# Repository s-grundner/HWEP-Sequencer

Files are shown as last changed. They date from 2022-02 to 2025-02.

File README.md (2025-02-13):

# HWEP - Sequencer [DE]



Frontpanel

| Neueste Renderung der Platine | Assemblierter Prototyp |
|:---:|:---:|
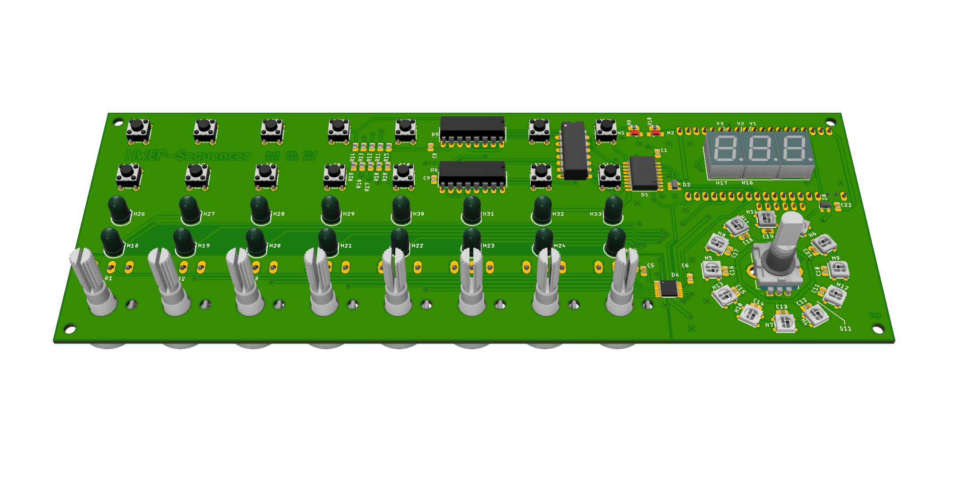
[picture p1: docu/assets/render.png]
render
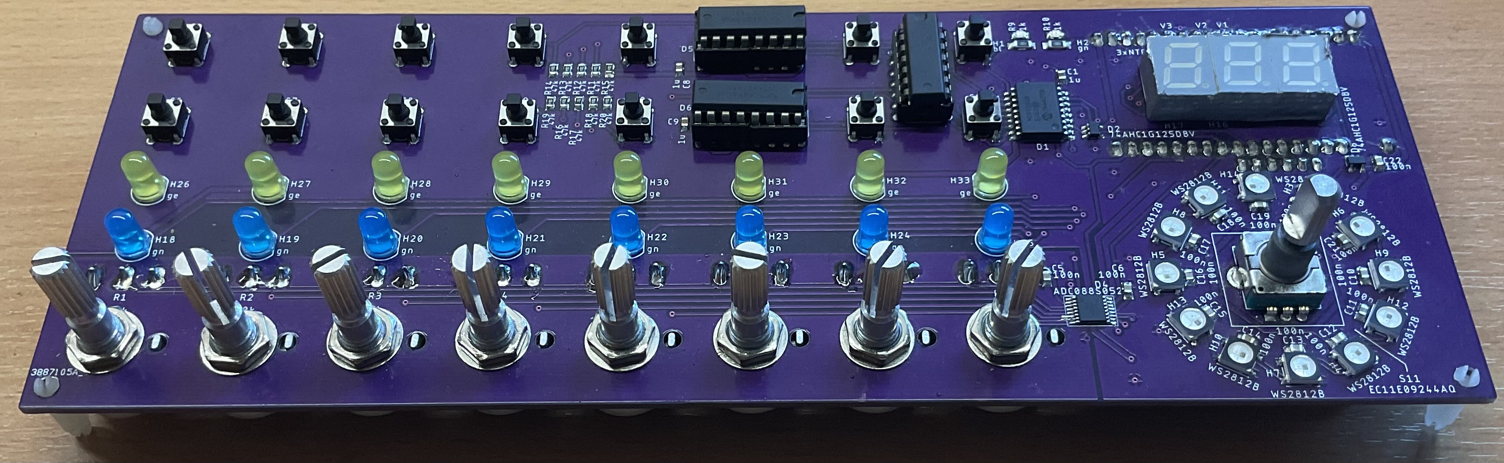
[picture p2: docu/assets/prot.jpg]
prototype
|||

## Projektstatus

MIDI Erweiterung in Arbeit. CAD dateien e.g. Gehäuse sind noch nicht im Projekt inkludiert.
Um die Diagramme in der Dokumentation gut erkennen zu können, empfiehlt sich, das Dark-Mode-Theme von GitHub zu Verwenden.

## Repository Struktur

 - [**Hardware DOCS**](manufacturing/hwep_sequencer_v2)
 - [**Software DOCS**](src/SRC_HWEP_Sequencer_V2)

## KUB - Kurzbeschreibung

Der Sequenzer ist ein musisches Instrument, welches vom Benutzer einstellbare Töne nacheinander abspielt und dadurch eine Melodie erzeugt. Die Tonlage wird durch Potentiometer analog eingestellt und anschließend an die chromatische Skala angepasst. Die acht Töne werden mit jeder steigenden Flanke des Takts durchgeschaltet.

Mit einem Pause-Taster kann der Zyklus pausiert werden. Mit dem Reset-Taster kann zum Anfang des Zyklus gesprungen werden. Der "Show Key" Taster zeigt bei Betätigung die Gespielten Noten am Display an. Der Sequencer ist mit zwei Prescalern für Gate-Länge und Taktrate ausgestattet. Dieser teilt den Takt oder das Gate des Tones durch 1, 2, 4, 8 oder 16. Außerdem verfügt der Sequencer über eine Umschalttaste (Shift), die das Funktionsspektrum erweitern. Die Dokumentation für die Taster befindet sich in der Funktionsbeschreibung.

Zum Bedienen des Sequencers gibt es verschiedene Parameter, die mithilfe eines Dreh-Encoders gesteuert werden können. Der Dreh-Encoder hat einen integrierten Taster, mit welchem man die Parameter, die man verändern will, einstellen kann. Die Veränderung der Parameter wird je nach Modus an verschiedenen Status LEDs und Anzeigen abgezeichnet.

Der Sequencer wird mit dem einem RTOS am ESP32 32-bit Microcontroller betrieben. Der Digitale Audioausgang erfolgt über das I²S (Inter-IC-Sound) Protokoll und kann 16-Bit Sounds bei einer Abtastrate von 44.1kHz übertragen und durch einen I²S-DAC (PCM5102a) direkt als Audio-Signal ausgegeben werden.

## FUB - Funktionsbeschreibung

Button_desc

#### 1. 8 Potentiometer als analoger Eingang

 - dient als analoger Eingang für die Tonlage der einzelnen Töne
 - jedes Potentiometer umfasst 24 Halbtöne bzw. zwei Oktaven
 - die analogen Werte einem 8 Channel ADC (ADC088S052) über die SPI Schnittstelle eingelesen

#### 2. 16 Status LED’s:

 - 8 EN-LED’s:
   - zeigen an, welcher Ton spielen wird oder stummgeschalten ist (LED aus)
 - 8 Index/Cursor-LED’s:
   - **Index:** zeigen an, welcher Ton gerade spielt
   - **Cursor:** dient zum Anzeigen eines Cursors

#### 3. 3x 7-Segent Display:

 - nützen zur Anzeige von Parametern
 - werden mit einem MCP23S08 via die SPI Schnittstelle seriell angesteuert
 
#### 4. Dreh-Encoder:

 - zum Einstellen der Parameter der verschiedenen Modi
 - um den Drehencoder befinden sich 12 RGB-LED’s, welche den Rotationstatus anzeigen
 
#### 5. Taster: 

> Jeder Taster wird mittels eines MCP23S08 via SPI eingelesen.

 - **Pause:** pausiert den Zyklus
 - **Reset:** setzt den Zyklus asynchron zurück
 - **Show Keys:** zeigt die gespielten Noten am Display
 - **Shift:** zum Einstellen der Parameter der verschiedenen Modi
 - e. **Prescaler:** einstellen von zwei verschiedenen Prescalern für Gate und Takt
   - 5 Taster für jeden Prescaler
   - Tasten werden auf 4-Bit Priorität-Encodiert
 
#### 6. 4 Modi

> Jeder Modus verändert die Anzeigen an den Status LED’s und Displays bzw. die Funktionalität verschiedener Eingaben. Nach wechseln eines Modus wird der aktuelle Modus am 7-Segment Display angezeigt, bis die Anzeige benötigt wird, um einen Parameter anzuzeigen.
 
 - BPM:
   - **7-Segment Display:** zeigt die eingestellten BPM bzw. die Wellenform an
   - **Index/Cursor:** zeigt den Index an
   - **Drehencoder:** zum Verändern der BPM
   - **Shift Taster:** Drehencoder verändert die Wellenform
 - Tonleiter Einstellungen:
   - **7-Segment Display:** zeigt den Tonleiter bzw. den Modalen Tonleiter an.
   - **Index/Cursor:** zeigt den Index an
   - **Drehencoder:** zum Verändern den Tonleiter
   - **Shift Taster:** verändert den Modus des Tonleiters (Dur,Moll…)
 - Enable/Reset:
   - **7-Segment Display:**
   - **Index/Cursor:** zeigt den Cursor an
   - **Drehencoder:** bewegt den Cursor. Dort wo der Cursor stehen bleibt, setzt sich der Zyklus zurück.
   - **Shift Taster:** stummt/entstummt einen Ton an der Cursorstellung
 
 - Transpose:
   - **7-Segment Display:** zeigt an um wieviel Halbtöne die Melodie transponiert wird
   - **Index/Cursor:** zeigt den Index an
   - **Drehencoder:** Transponiert die Tonlage um einen Halbton
   - **Shift Taster:** Drehencoder verändert die Tonlage um eine Oktave
 
#### 7. ESP32 32-Bit Microcontroller:

 - Zentrale Recheneinheit für den Sequenzer
 - Berechnung der Wavetables
 - SPI als Übertragungsprotokoll zur Ansteuerung der internen Peripherien
 - Audio-Output:
   - Digitale Audioübertragung via I²S Protokoll
   - 16-bit Audio-Signale mit Abtastrate von 44,1kHz
   - Ein I²S-DAC (PCM5102a) decodiert die Audio-Daten und gibt sie Analog an eine 3,5mm Klinkenbuchse aus.
   - Kompatibel mit Trinity Endstufe

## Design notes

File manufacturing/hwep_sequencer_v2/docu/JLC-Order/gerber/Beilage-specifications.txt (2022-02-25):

PC board specifications: 
Board thickness:   	1.570000mm
Board type:       	FR4
Number of layers:  	2
End copper thickness:	35.000000um
Stop mask color:   	green
Silk screen color: 	white
Surface finish:    	any lead free
Silk screen trim: 	Trim on solder mask opening pads

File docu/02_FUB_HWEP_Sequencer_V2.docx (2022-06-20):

Funktionsbeschreibung

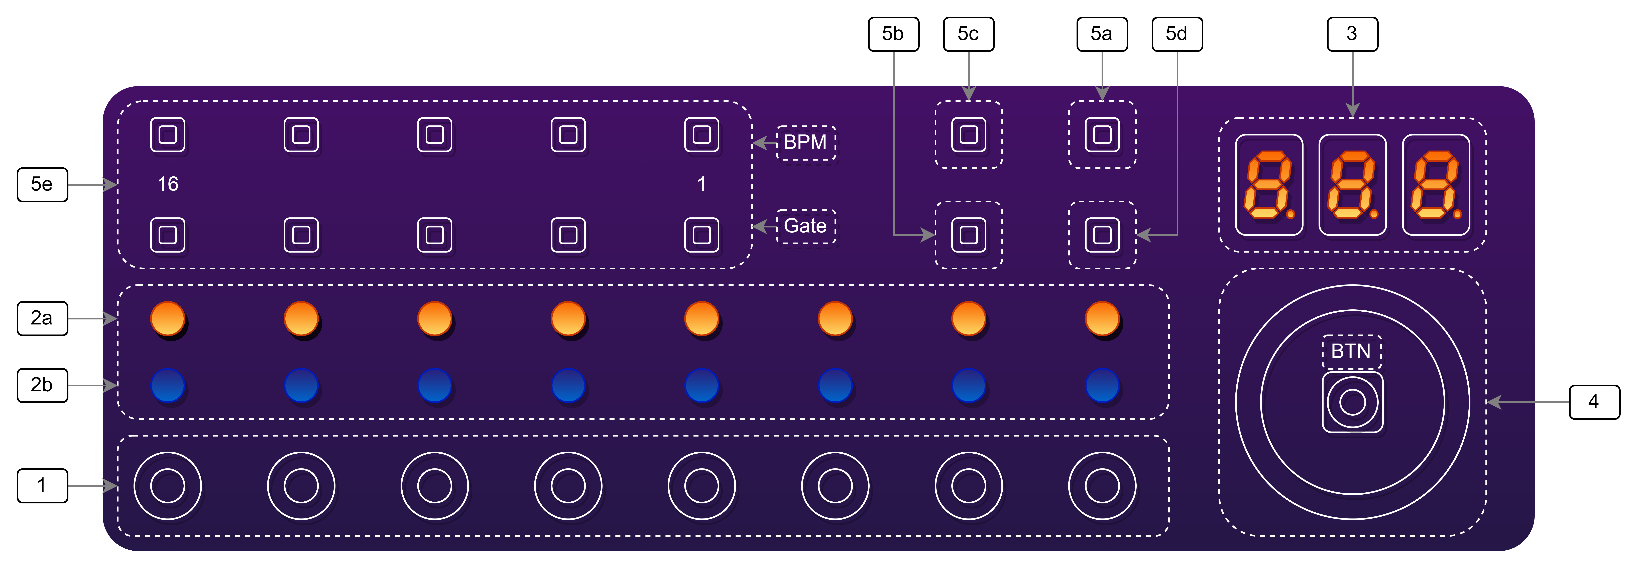
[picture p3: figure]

1. 8 Potentiometer als analoger Eingang:
  a. dient als analoger Eingang für die Tonlage der einzelnen Töne
  b. jedes Potentiometer umfasst 24 Halbtöne bzw. zwei Oktaven
  c. die analogen Werte einem 8 Channel ADC (ADC088S052) über die SPI Schnittstelle eingelesen
2. 16 Status LED’s:
  a. 8 EN-LED’s:
    i. zeigen an, welcher Ton spielen wird oder stummgeschalten ist (LED aus)
  b. 8 Index/Cursor-LED’s:
    i. Index: zeigen an, welcher Ton gerade spielt
    ii. Cursor: dient zum Anzeigen eines Cursors
3. 3x 7-Segent Display:
  a. nützen zur Anzeige von Parametern
  b. werden mit einem MCP23S08 via die SPI Schnittstelle seriell angesteuert
4. Dreh-Encoder:
  a. zum Einstellen der Parameter der verschiedenen Modi
  b. um den Drehencoder befinden sich 12 RGB-LEDs, welche den Rotationstatus anzeigen
5. Taster: Jeder Taster wird mittels eines MCP23S08 via SPI eingelesen.
  a. Pause: pausiert den Zyklus
  b. Reset: setzt den Zyklus asynchron zurück
  c. Show Keys: zeigt die gespielten Noten am Display
  d. Shift: zum Einstellen der Parameter der verschiedenen Modi
  e. Prescaler: einstellen von zwei verschiedenen Prescalern für Gate und Takt
    i. 5 Taster für jeden Prescaler
    ii. Taster werden auf 4-Bit Priorität-Encodiert
6. 4 Modi

Jeder Modus verändert die Anzeigen an den Status LEDs und Displays bzw. die Funktionalität verschiedener Eingaben. Nach wechseln eines Modus wird der aktuelle Modus am 7-Segment Display angezeigt, bis die Anzeige benötigt wird, um einen Parameter anzuzeigen. Der Modus wird Weitergeschalten, indem man den integrierten Taster des Dreh-Encoder drückt.

  a. BPM:
    i. 7-Segment Display: zeigt die eingestellten BPM bzw. die Wellenform an
    ii. Index/Cursor: zeigt den Index an
    iii. Drehencoder: zum Verändern der BPM
    iv. Event Taster: Drehencoder verändert die Wellenform
  b. Tonleiter Einstellungen:
    i. 7-Segment Display: zeigt den Tonleiter bzw. den Modalen Tonleiter an.
    ii. Index/Cursor: zeigt den Index an
    iii. Drehencoder: zum Verändern des Tonleiters
    iv. Event Taster: verändert den Modus des Tonleiters (Dur, Moll…)
  c. Enable/Reset:
    i. 7-Segment Display: -
    ii. Index/Cursor: zeigt den Cursor an
    iii. Drehencoder: bewegt den Cursor. Dort wo der Cursor stehen bleibt, setzt sich der Zyklus zurück.
    iv. Event Taster: stummt/entstummt einen Ton an der Cursorstellung
  d. Transpose:
    i. 7-Segment Display: zeigt an um wieviel Halbtöne die Melodie transponiert wird
    ii. Index/Cursor: zeigt den Index an
    iii. Drehencoder: Transponiert die Tonlage um einen Halbton
    iv. Event Taster: Drehencoder verändert die Tonlage um eine Oktave
7. ESP32 32-Bit Microcontroller:
  a. Zentrale Recheneinheit für den Sequenzer
  b. Berechnung der Wavetables
  c. SPI als Übertragungsprotokoll zur Ansteuerung der internen Peripherien
  d. Audio-Output:
    i. Digitale Audioübertragung via I²S Protokoll
    ii. Auswahl zwischen 16-, 24- und 32-bit Audio-Signale mit Abtastrate von 44,1kHz
    iii. Ein I²S-DAC (PCM5102a) decodiert die Audio-Daten und gibt sie Analog an eine 3,5mm Klinkenbuchse aus.

4AHEL Grundner, Ihninger 20.6.2022 1 / 1

HWEP Sequencer Elektronik Technische Informatik Funktionsbeschreibung

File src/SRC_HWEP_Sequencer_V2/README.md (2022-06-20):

# Software DOCS [DE]

Die Software am ESP32 des Sequencers kümmert sich um die Anzeigen, die Benutzer-Eingaben sowie das Audio. Um diese Aufgaben zu erfüllen, wurde ein Real Time Operating System (freeRTOS) verwendet, welches die auf der nächsten Seite zusehenden Tasks verwaltet.
Der Source Code und auch alle Libraries sind ausschließlich in C geschrieben.

# Toolchain
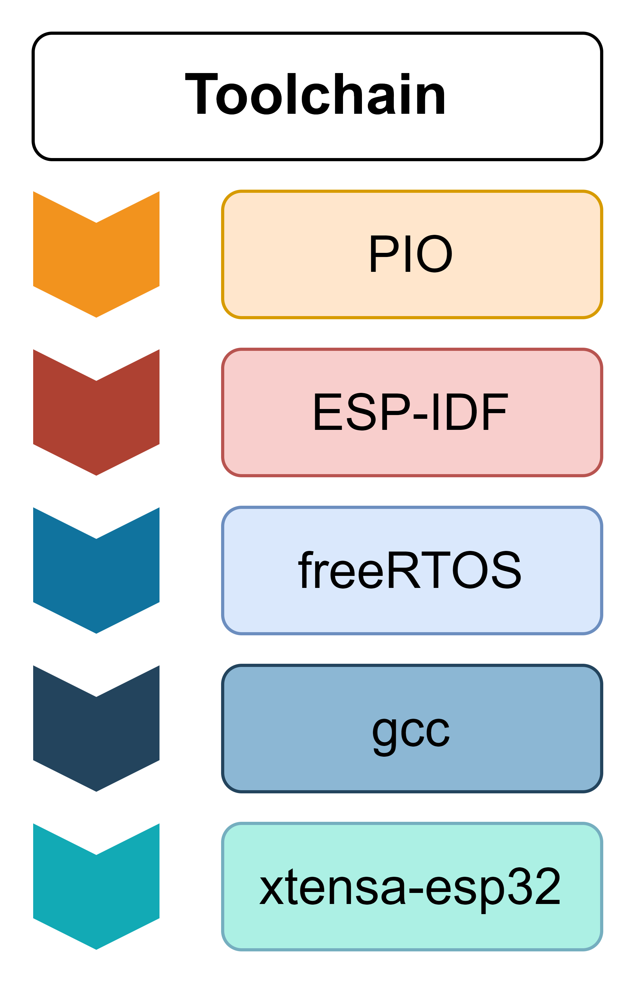
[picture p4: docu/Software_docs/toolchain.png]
Toolchain


# Programm beschreibung

RTOS

BSB

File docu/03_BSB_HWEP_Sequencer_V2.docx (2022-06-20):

##### Blockschaltbild

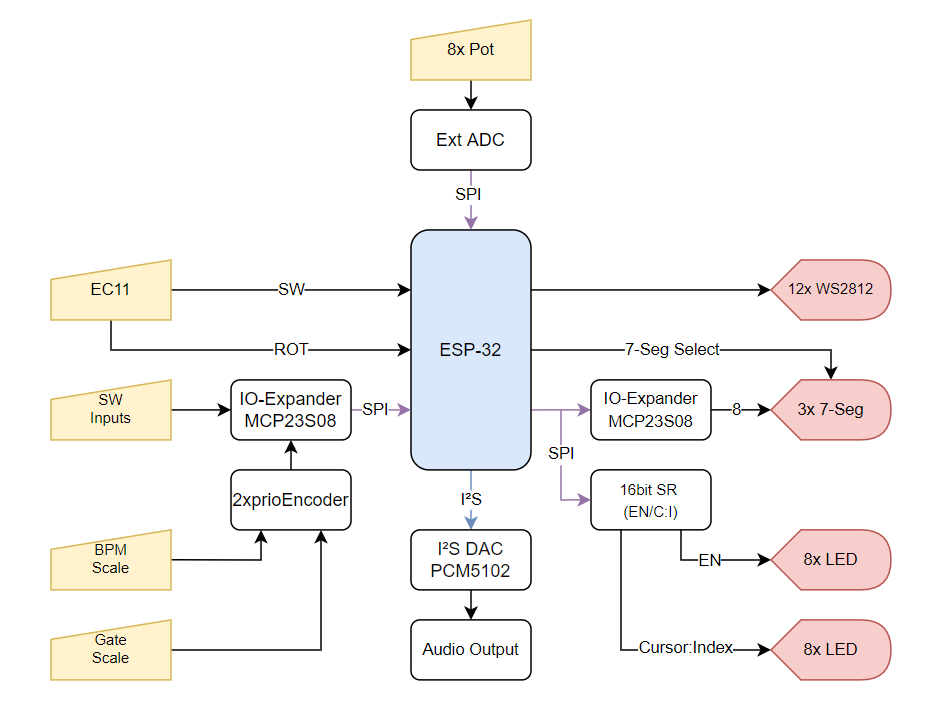
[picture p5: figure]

4AHEL Grundner/Ihninger 20.6.2022

HWEP Sequencer Elektronik Technische Informatik Blockschaltbild

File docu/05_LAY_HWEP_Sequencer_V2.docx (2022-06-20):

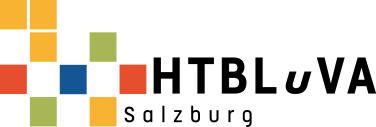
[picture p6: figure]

Werkstoff:

Sachnummer, Dateiname:

Name:

Benennung:

Toleranz:

Blatt:

Blätter:

Datum:

Spr.:

Maßstab:

Dokumentart:

ID-Nr.:

Version:

Dokumentstatus:

Gez.:

Geprüft:

Betreuer:

Freigabe:

Revision:

Beilage 2

Grundner, Ihninger

Sequencer

Layout top

4AHEL

ohne

DE

1

1

20.06.2022

HTBLuVA Salzburg

Elektronik

GruS

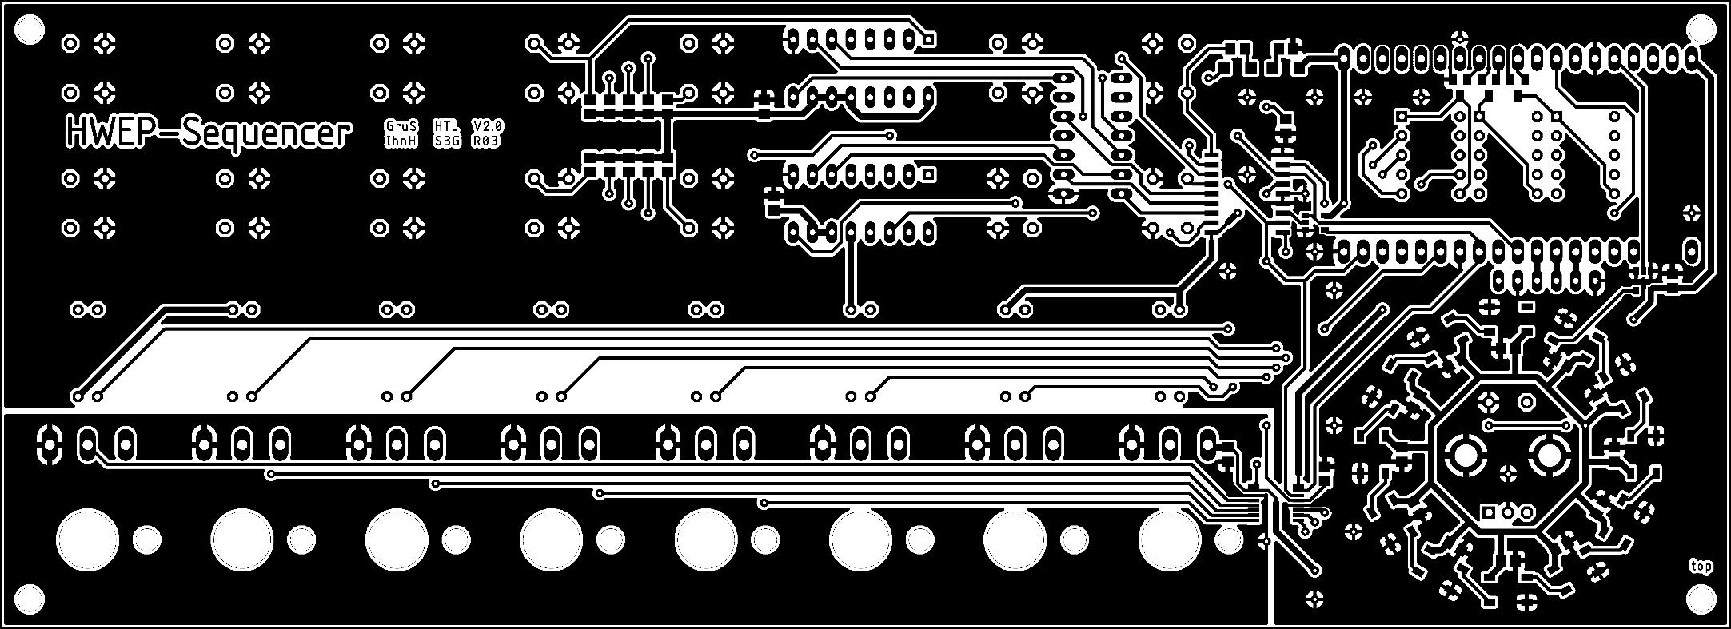
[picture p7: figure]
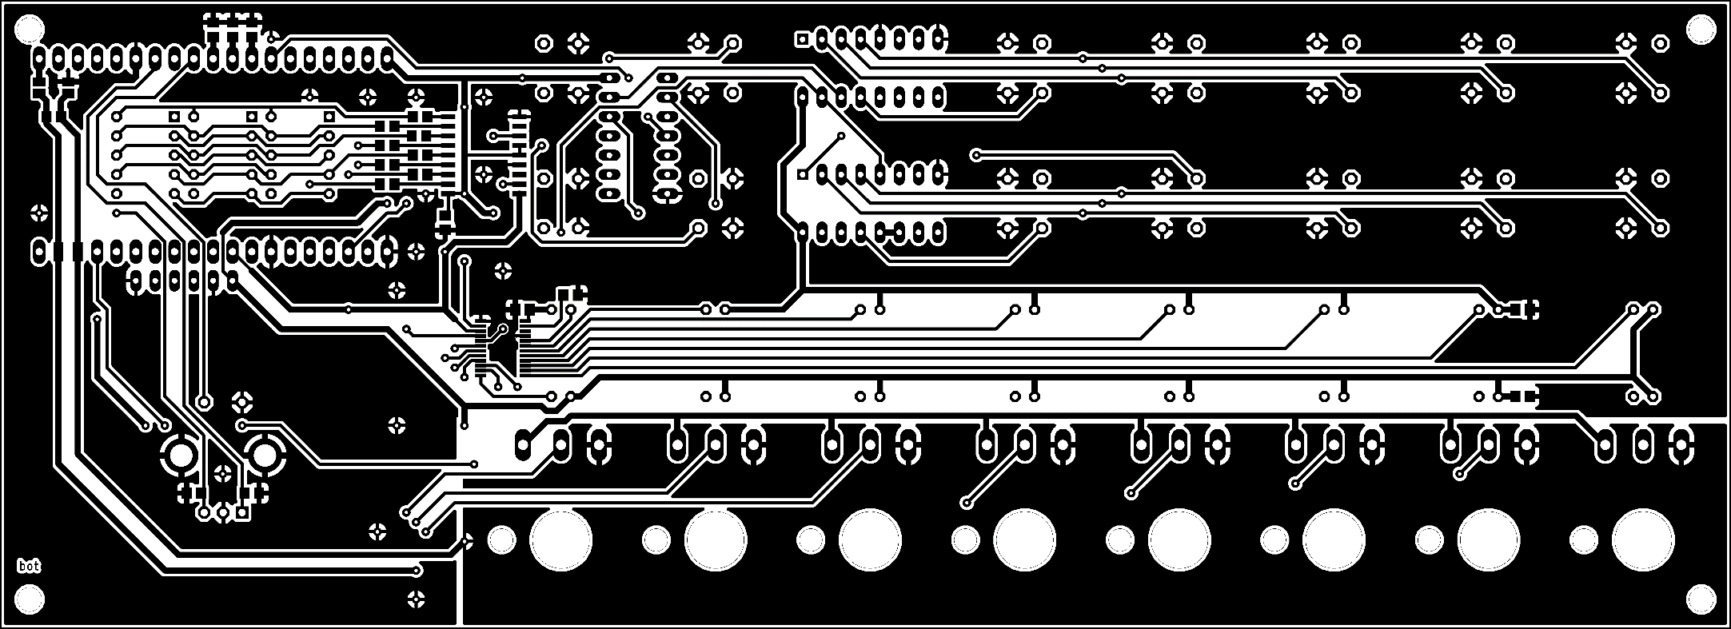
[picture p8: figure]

Werkstoff:

Sachnummer, Dateiname:

Name:

Benennung:

Toleranz:

Blatt:

Blätter:

Datum:

Spr.:

Maßstab:

Dokumentart:

ID-Nr.:

Version:

Dokumentstatus:

Gez.:

Geprüft:

Betreuer:

Freigabe:

Revision:

Beilage 3

Grundner, Ihninger

Sequenzer

Layout bot

4AHEL

ohne

DE

1

1

20.06.2022

HTBLuVA Salzburg

Elektronik

GruS

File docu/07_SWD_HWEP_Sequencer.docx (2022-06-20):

Softwarebeschreibung

Die Software am ESP32 des Sequencers kümmert sich um die Anzeigen, die Benutzer-Eingaben sowie das Audio. Um diese Aufgaben zu erfüllen, wurde ein Real Time Operating System (freeRTOS) verwendet, welches die auf der nächsten Seite zusehenden Tasks verwaltet.

Der Source Code und auch alle Libraries sind ausschließlich in C geschrieben.

Das Hauptprogramm hat folgenden Ablauf:

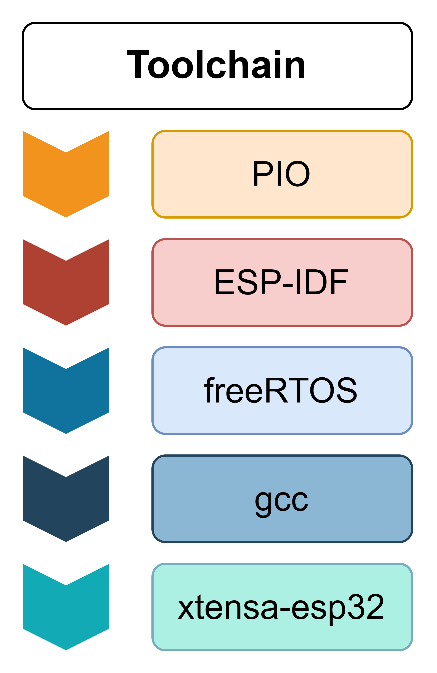
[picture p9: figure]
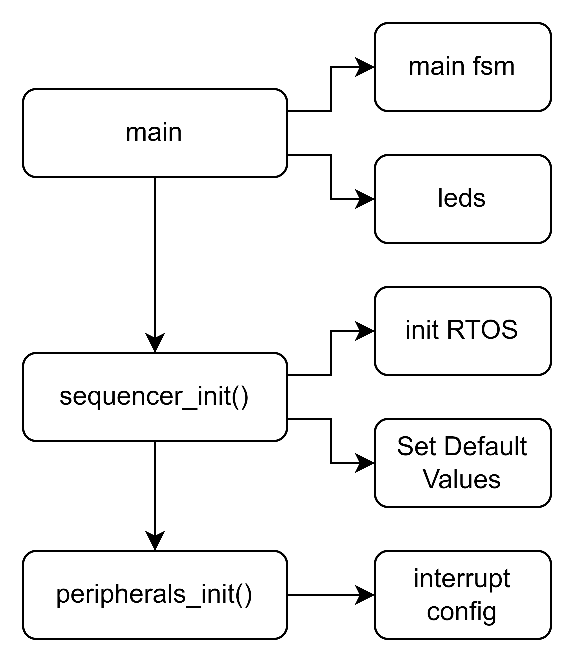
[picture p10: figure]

Das Open Source Projekt kann auf https://github.com/s-grundner/HWEP-Sequencer vollständig angesehen werden.

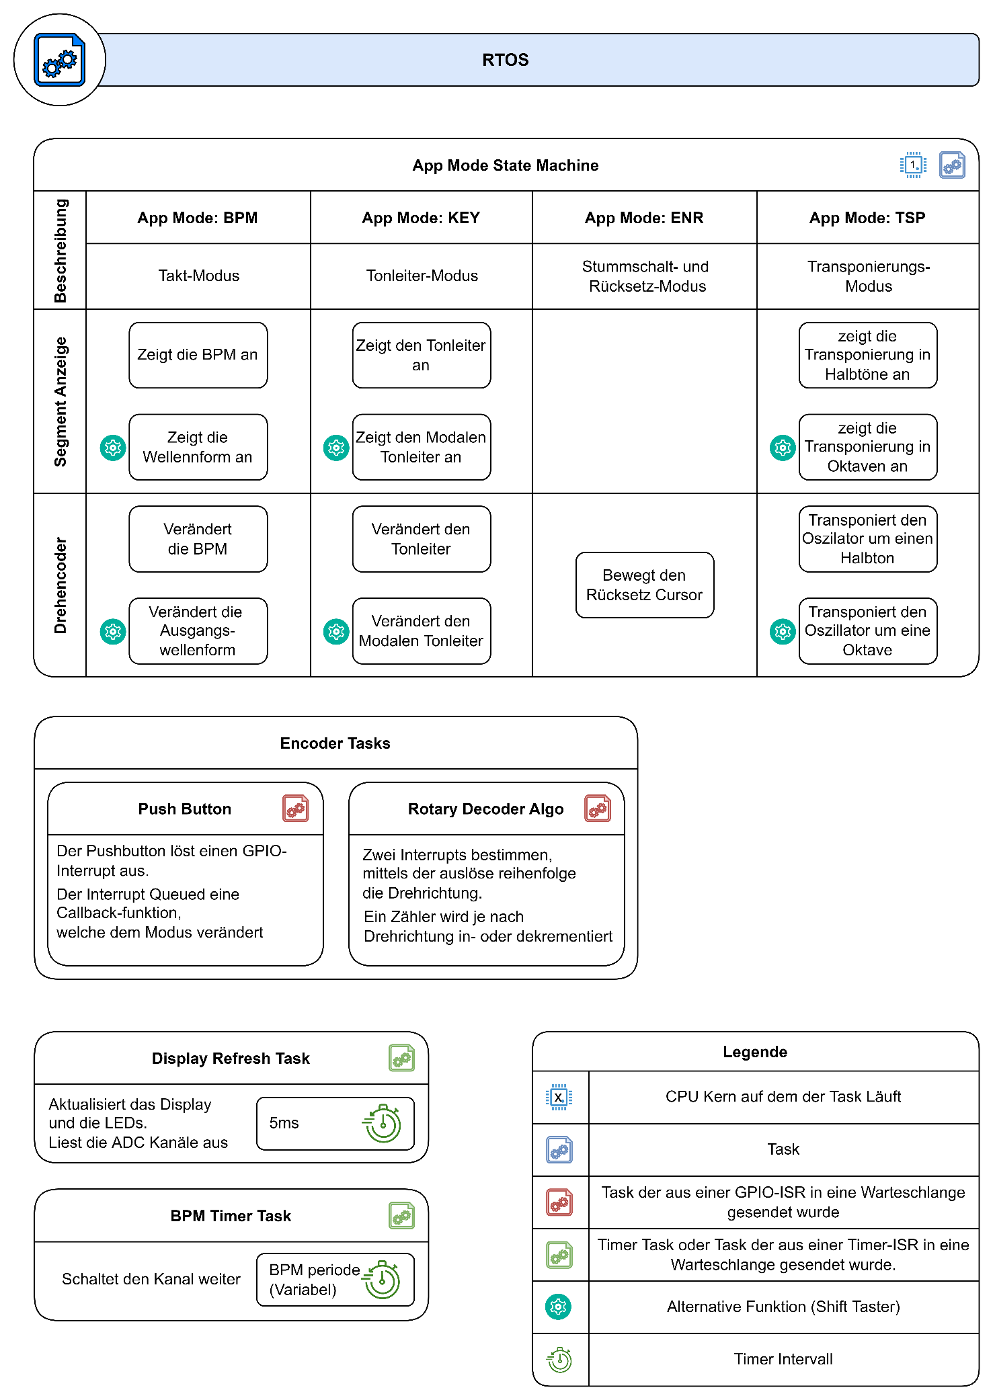
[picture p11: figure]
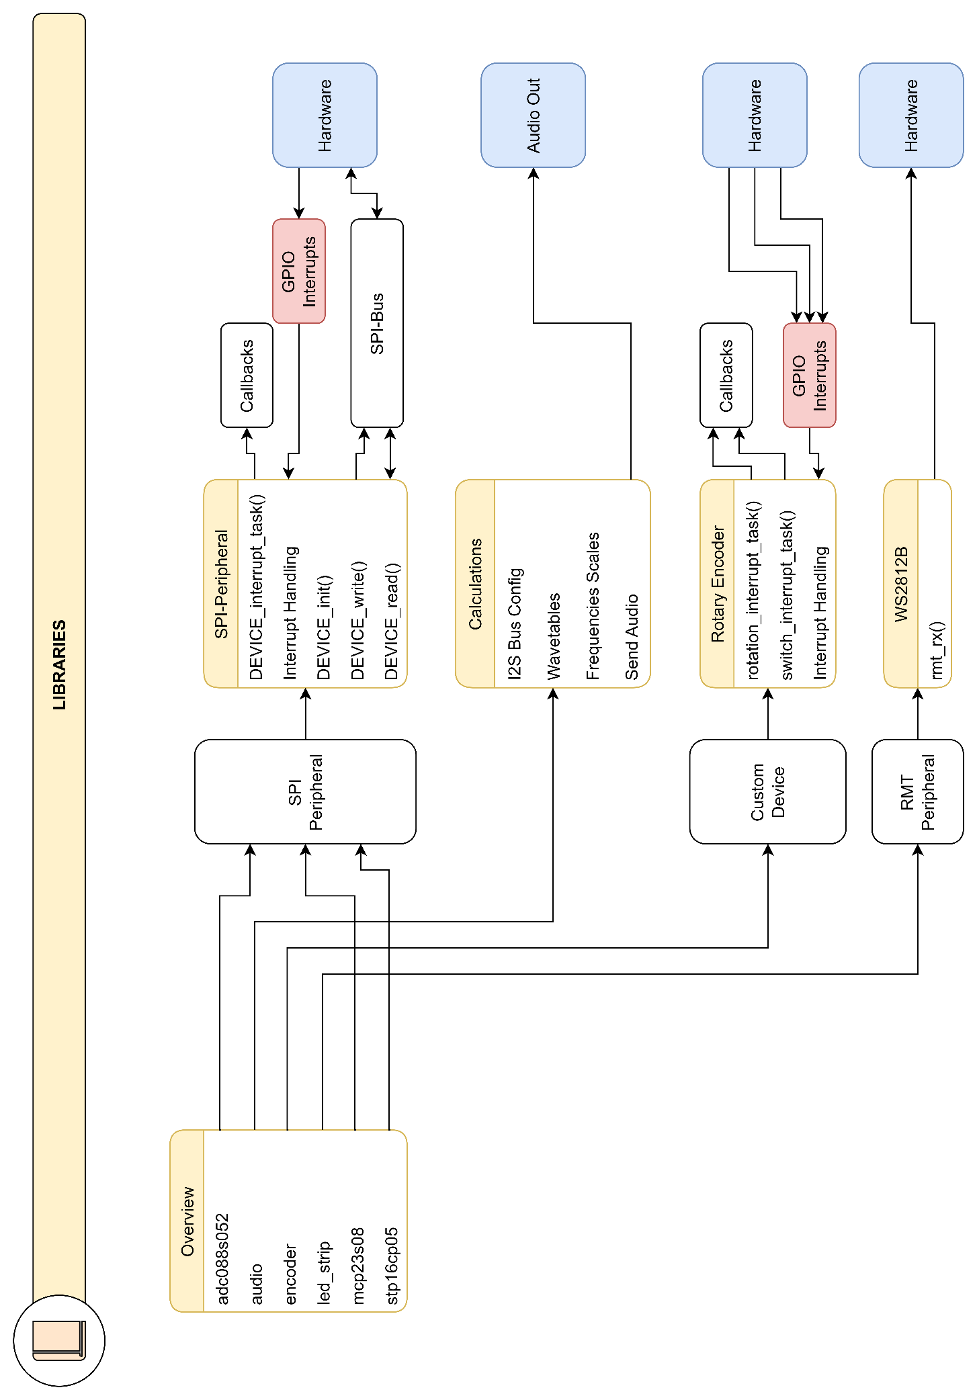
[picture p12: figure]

4AHEL Grundner/Ihninger 20.6.2022

HWEP Sequencer Elektronik Technische Informatik Software-Dokumentation

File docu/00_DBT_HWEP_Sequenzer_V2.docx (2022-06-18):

Sequencer

Ein Projekt

von Grunder Simon

&

Ihninger Hanna

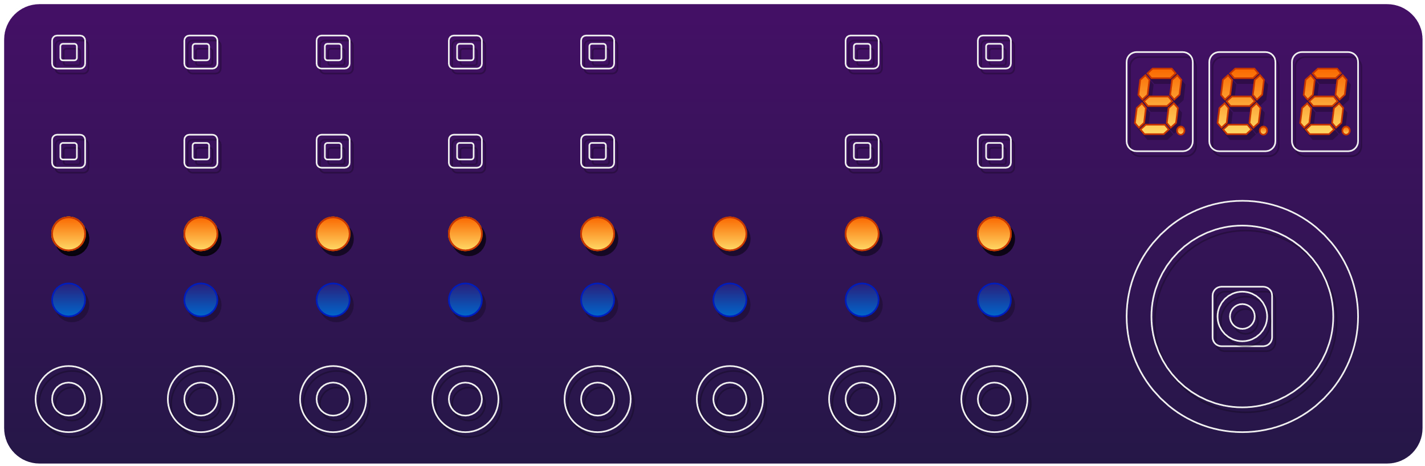
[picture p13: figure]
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

S a l z b u r g

Abteilung für Elektronik und technische Informatik

4AHEL

2022

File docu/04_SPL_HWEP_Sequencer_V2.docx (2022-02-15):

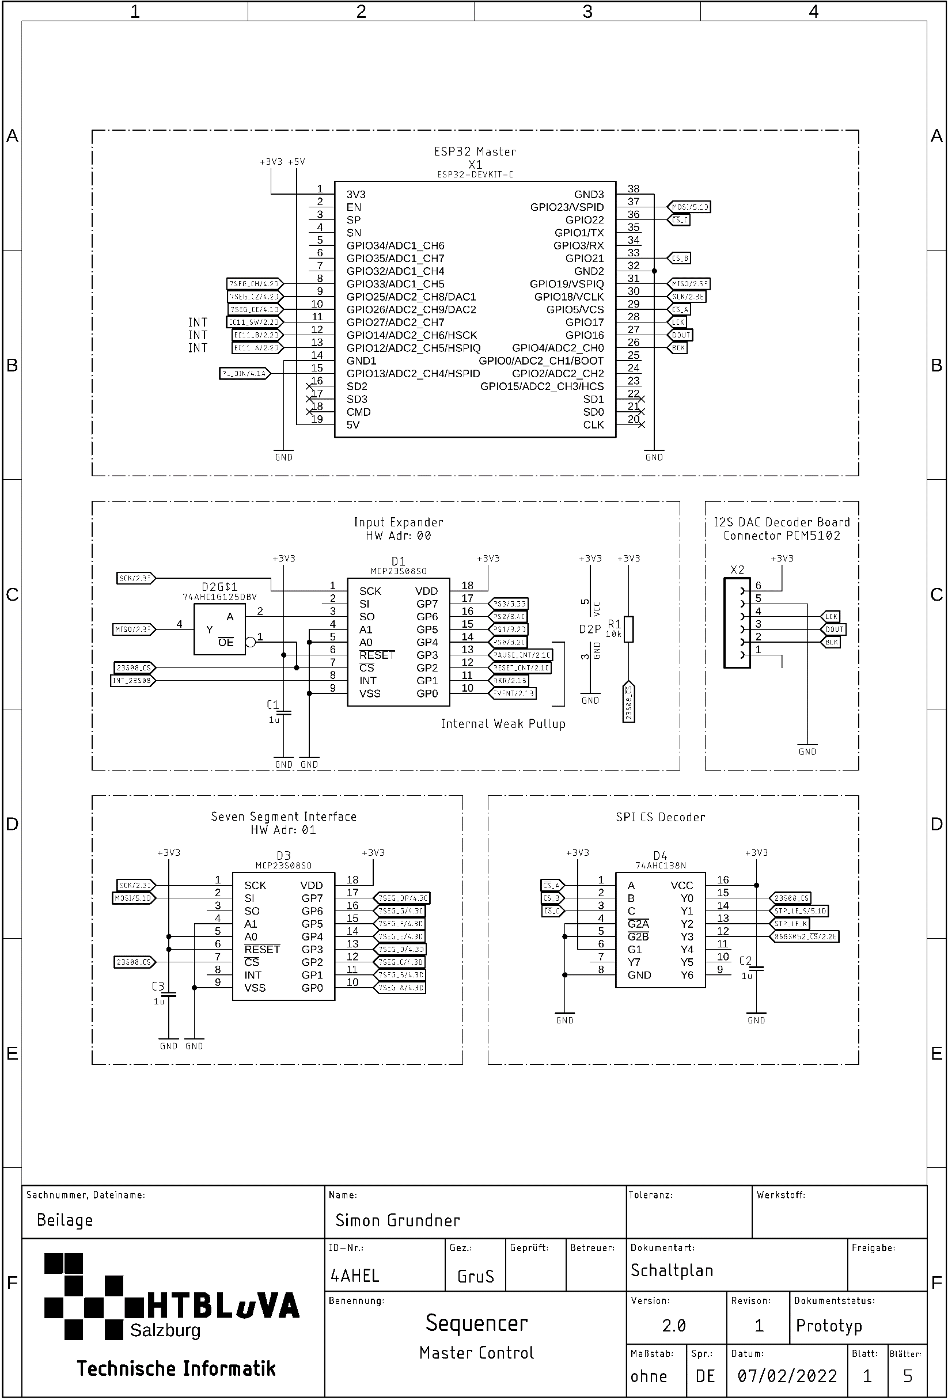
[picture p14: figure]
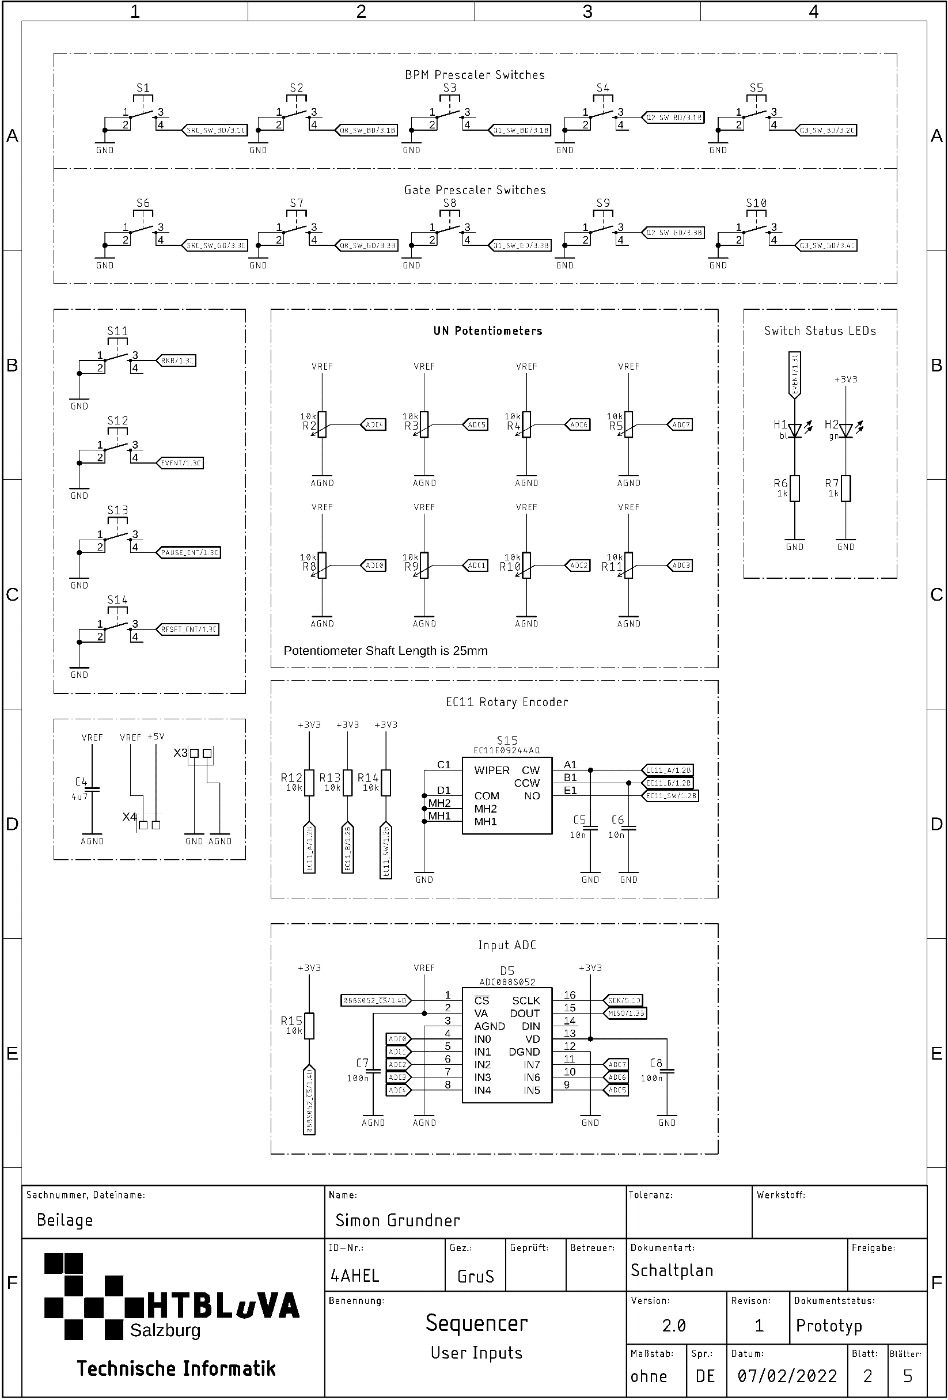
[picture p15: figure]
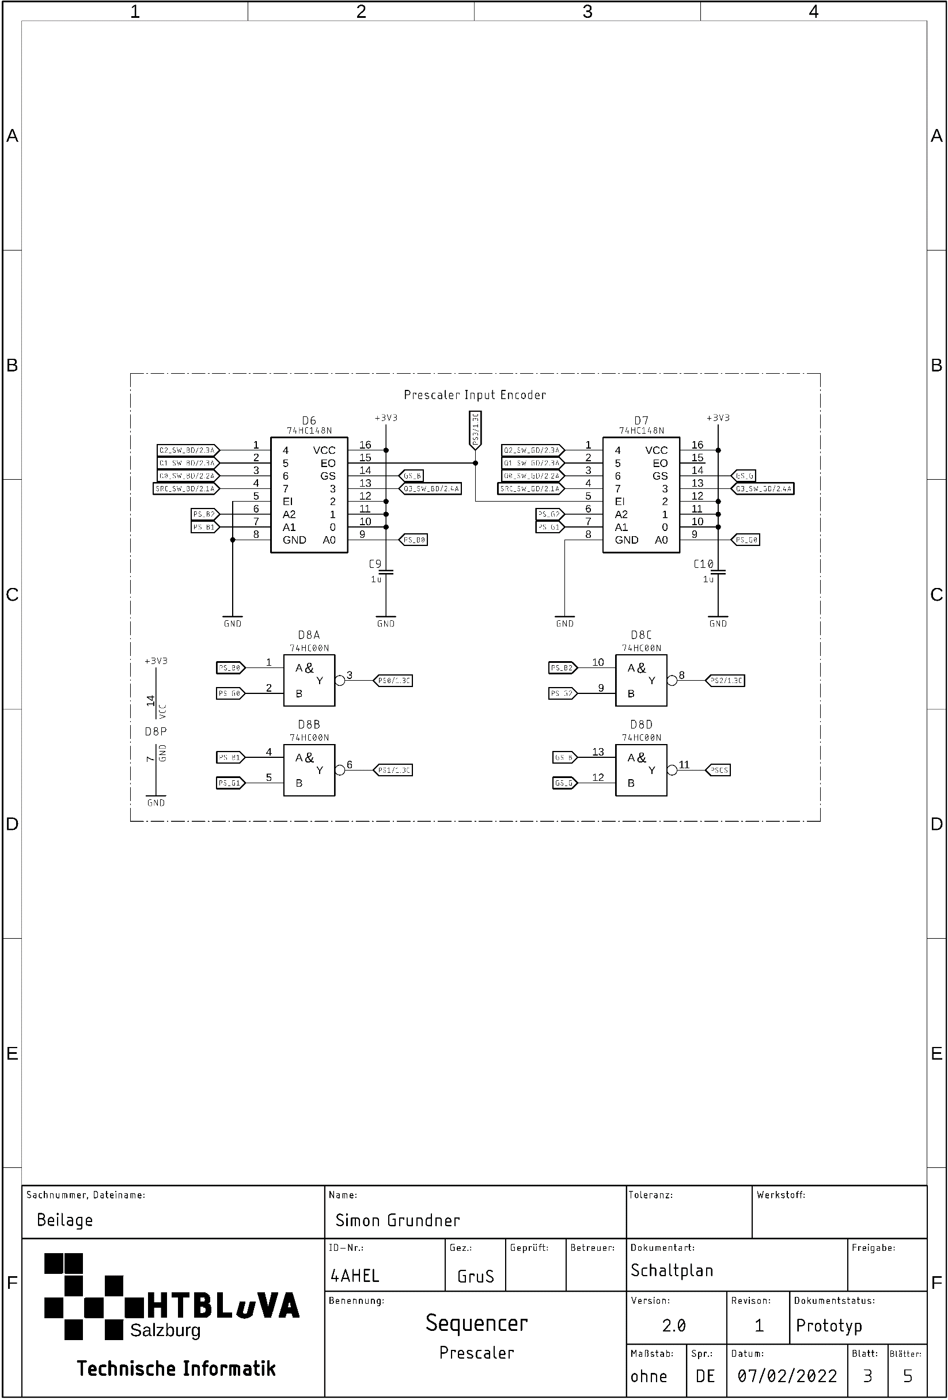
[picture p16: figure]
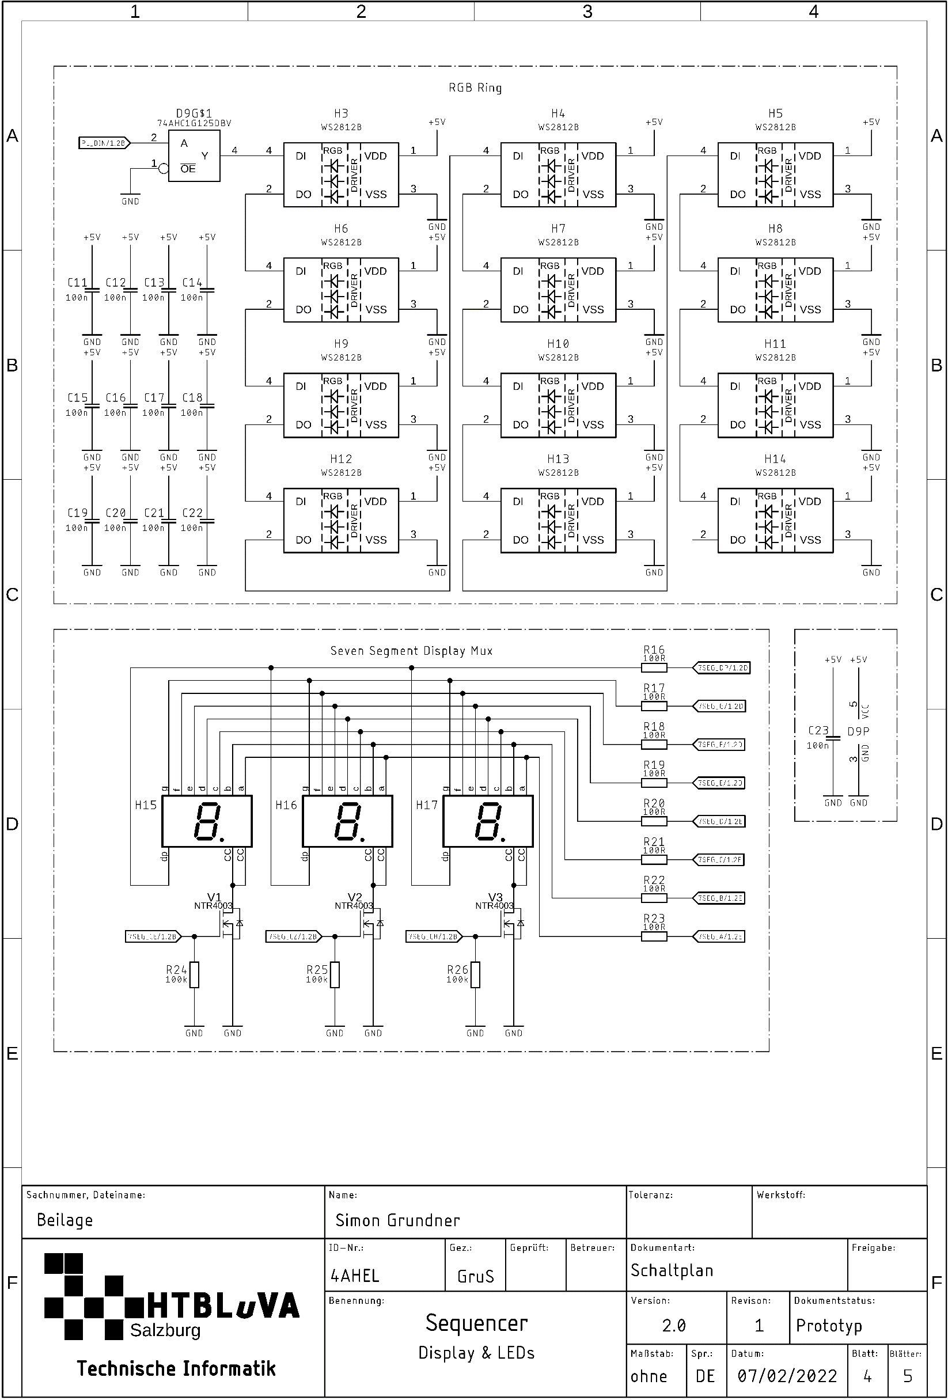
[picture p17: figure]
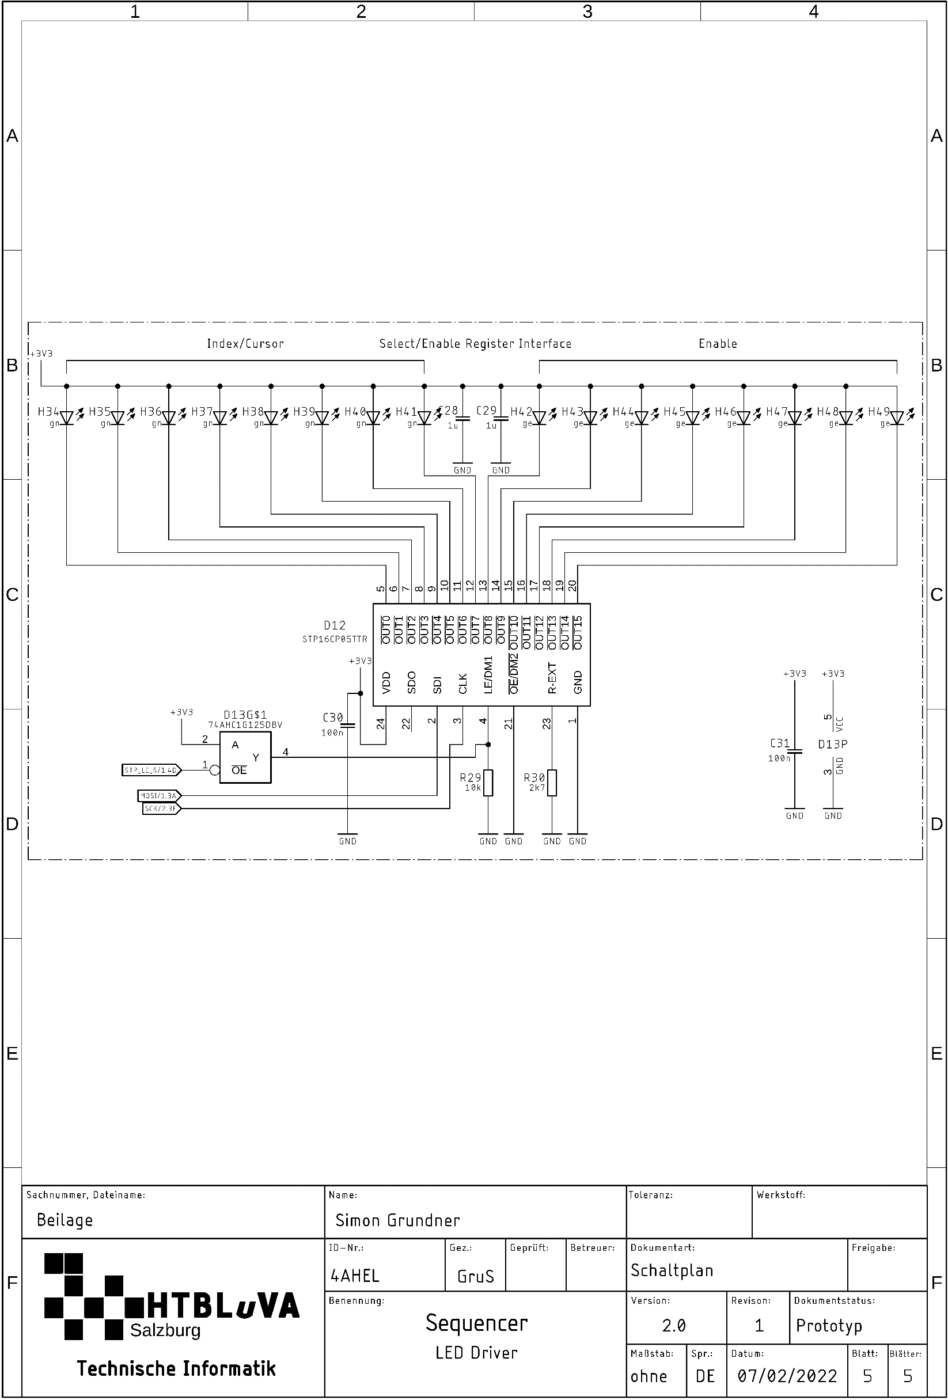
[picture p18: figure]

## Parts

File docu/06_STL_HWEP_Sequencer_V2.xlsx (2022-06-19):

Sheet: Notizblatt
Stückliste Notizblatt |  |  |  |  | HTBLuVA-Salzburg, Elektronik
Lfd. Nr. | Stück- zahl | Ein- heit | Benennung | Referenzkennzeichen | Lieferant | Bestellnummer | MCd | Preis/EH | VE | Bemerkung
1 | 8 | STK | RES 100R |  | www.mouser.de | 652-CR0805JW-101ELF | 1000 | 0.041 | 10 | SMD 0805
2 | 2 | STK | RES 1k |  | www.mouser.de | 652-CR0805FX-1001ELF | 1001 | 0.081 | 10 | SMD 0805
3 | 1 | STK | RES 2k7 |  | www.mouser.de | 652-CR0805FX-2701ELF | 2701 | 0.044 | 10 | SMD 0805
4 | 6 | STK | RES 10k |  | www.mouser.de | 652-CR0805FX-1002ELF | 1002 | 0.024 | 10 | SMD 0805
5 | 3 | STK | RES 100k |  | www.mouser.de | 652-CR0805FX-1003ELF | 1003 | 0.020 | 10 | SMD 0805
6 | 8 | STK | TRIM 10k |  | www.mouser.de | 858-P160KN20QA25B10K | p160 | 0.92 | 10 | P160
7 | 16 | STK | CAP 100n |  | www.mouser.de | 710-885012207045 |  | 0.047 | 10 | SMD 0805
8 | 2 | STK | CAP 10n |  | www.mouser.de | 80-C0805C103K1RAUTO |  | 0.051 | 10 | SMD 0805
9 | 6 | STK | CAP 1u |  | www.mouser.de | 963-UMF212B7105MGHT |  | 0.123 | 10 | SMD 0805
10 | 1 | STK | CAP 4u7 |  | www.mouser.de | 81-GRM21BR71C475KE1L |  | 0.117 | 10 | SMD 0805
11 | 1 | STK | LED bl |  | www.mouser.de | 720-LBQ39EN1P1351 |  | 0.368 | 1 | CHIPLED_1206
12 | 1 | STK | LED or |  | www.mouser.de | 720-LOR976-PS-1 |  | 0.271 | 1 | CHIPLED_1206
13 | 8 | STK | LED gn |  | www.mouser.de | 710-151051VS04000 |  | 0.219 | 1 | LED 5MM
14 | 8 | STK | LED ge |  | www.mouser.de | 710-151051YS04000 |  | 0.193 | 1 | LED 5MM
15 | 12 | STK | LED WS2812B |  | www.mouser.de | 474-COM-16346 |  | 22.750 | 50 | SMD 5050
16 | 3 | STK | TRMFN NTR4003 |  | www.mouser.de | 863-NTR4003NT1G |  | 0.298 | 1 | SOT-23
17 | 1 | STK | IC 74HC00 |  | www.mouser.de | 595-SN74HC00NE4 |  | 0.525 | 1 | DIP14
18 | 2 | STK | IC 74AHC1G125DBV |  | www.mouser.de | 595-SN74AHC1G125DBVT |  | 0.823 | 1 | SOT23-5
19 | 2 | STK | IC 74HC148N |  | www.mouser.de | 595-SN74HC148N |  | 0.525 | 1 | DIP16
20 | 1 | STK | IC ADC088S052 |  | www.mouser.de | 926-AD088S052CIMTNPB |  | 3.89 | 1 | TSSOP16
21 | 2 | STK | IC MCP23S08SO |  | www.mouser.de | 579-MCP23S08-E/SO |  | 1.36 | 1 | SO18W
22 | 2 | STK | IC STP16CP05TTR |  | www.mouser.de | 511-STP16CP05TTR |  | 1.75 |  | TSSOP24
23 | 1 | STK | MOD ESP32 |  | www.mouser.de |  |  |  |  | DevKitC, 2xH19 RM2,54 D25,4
24 | 1 | STK | MOD PCM5102 |  | www.amazon.de | https://www.amazon.de/-/en/Hojffuue-PCM5102-Digital-Analogue-Converter/dp/B09FZCQWZR |  | 12.68 |  | 1xH06
25 | 3 | STK | DISP HD-H103 |  | www.mouser.de |  |  |  |  | HDSP-E
26 | 1 | STK | SW EC11E09244AQ |  | www.mouser.de | 688-EC11E09244AQ |  | 4.860 | 1 | EC11E
27 | 14 | STK | SW |  | www.mouser.de | 179-TS016673BK260D |  | 0.11 | 10 | B3F-10XX
28 | 2 | STK | CON FE19 |  | www.amazon.de | https://www.amazon.de/-/en/gp/product/B07VNXL5BD/ref=ewc_pr_img_1?smid=A2VP41F3CQXNC&psc=1 |  |  |  | FE19 RM2,54
29 | 1 | STK | CON FE06 |  | www.amazon.de | https://www.amazon.de/-/en/gp/product/B07VNXL5BD/ref=ewc_pr_img_1?smid=A2VP41F3CQXNC&psc=1 |  |  |  | FE06 RM2,54
30 | 1 | STK | CON MA06 |  | www.amazon.de | https://www.amazon.de/-/en/gp/product/B07VNXL5BD/ref=ewc_pr_img_1?smid=A2VP41F3CQXNC&psc=1 |  |  |  | MA06 RM2,54
Nach dieser Linie dürfen keine Daten mehr eingegeben werden

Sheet: Eingabe
Jahrgang: |  |  |  | 2AHEL |  | Toleranz: |  |  |  | Dokumentart: | Stückliste | Sachnummer, Dateiname:
Katalognummer: |  |  |  |  |  | Werkstoff: |  |  |  | Datum: | 2022-06-19 | Stückliste: |  | Beilage 3
Vorname Nachname: |  |  |  | Simon Grundner |  | Geprüft : |  |  |  | Version: | 1.0 | Materialkalkulation: |  | Beilage 10
Kurzzeichen: |  |  |  | GruS |  | Betreuer: |  |  |  | Revision: | 1 | Einheiten zur Bestellung: |  | 1
Benennung (Projekt) / Version: |  |  |  | Sequencer |  | Freigabe. |  | StrH |  | Dokumentenstatus: | Fertigung | Ausbildungsrichtung:
Benennung (Projekt) Zeile 2: |  |  |  |  |  | Sprache: |  | DE |  | Maßstab: | ohne | Technische Informatik
Lfd. Nr. | Stück- zahl | Ein- heit | Benennung | Referenzkennzeichen | Lieferant | Bestellnummer | MCd | Preis/EH | VE | Bemerkung | Preisvorschau 71,3 €/STK | 1 EH inkl. 10% GK = 59,42 € zuzgl. 20% MwSt. = 71,3 € Bestellnummer Bestellmenge Bestelltextkontrolle - Ben. Ref.KZ - keine Feldlängenkontrolle
1 | 8 | STK | RES 100R |  | www.mouser.de | 652-CR0805JW-101ELF | 1000 | 0.041 | 10 | SMD 0805 | 0.4100 | 652-CR0805JW-101ELF | 10 STK | RES 100R
2 | 2 | STK | RES 1k |  | www.mouser.de | 652-CR0805FX-1001ELF | 1001 | 0.088 | 1 | SMD 0805 | 0.1760 | 652-CR0805FX-1001ELF | 2 STK | RES 1k
3 | 1 | STK | RES 2k7 |  | www.mouser.de | 652-CR0805FX-2701ELF | 2701 | 0.088 | 1 | SMD 0805 | 0.0880 | 652-CR0805FX-2701ELF | 1 STK | RES 2k7
4 | 6 | STK | RES 10k |  | www.mouser.de | 652-CR0805FX-1002ELF | 1002 | 0.024 | 10 | SMD 0805 | 0.2400 | 652-CR0805FX-1002ELF | 10 STK | RES 10k
5 | 3 | STK | RES 100k |  | www.mouser.de | 652-CR0805FX-1003ELF | 1003 | 0.020 | 10 | SMD 0805 | 0.2000 | 652-CR0805FX-1003ELF | 10 STK | RES 100k
6 | 8 | STK | TRIM 10k |  | www.mouser.de | 858-P160KN20QA25B10K | p160 | 0.92 | 10 | P160 | 9.1900 | 858-P160KN20QA25B10K | 10 STK | TRIM 10k
7 | 16 | STK | CAP 100n |  | www.mouser.de | 710-885012207045 |  | 0.047 | 10 | SMD 0805 | 0.9400 | 710-885012207045 | 20 STK | CAP 100n
8 | 2 | STK | CAP 10n |  | www.mouser.de | 80-C0805C103K1RAUTO |  | 0.051 | 10 | SMD 0805 | 0.5100 | 80-C0805C103K1RAUTO | 10 STK | CAP 10n
9 | 6 | STK | CAP 1u |  | www.mouser.de | 963-UMF212B7105MGHT |  | 0.123 | 10 | SMD 0805 | 1.2300 | 963-UMF212B7105MGHT | 10 STK | CAP 1u
10 | 1 | STK | CAP 4u7 |  | www.mouser.de | 81-GRM21BR71C475KE1L |  | 0.117 | 10 | SMD 0805 | 1.1700 | 81-GRM21BR71C475KE1L | 10 STK | CAP 4u7
11 | 1 | STK | LED bl |  | www.mouser.de | 720-LBQ39EN1P1351 |  | 0.368 | 1 | CHIPLED_1206 | 0.3680 | 720-LBQ39EN1P1351 | 1 STK | LED bl
12 | 1 | STK | LED or |  | www.mouser.de | 720-LOR976-PS-1 |  | 0.271 | 1 | CHIPLED_1206 | 0.2710 | 720-LOR976-PS-1 | 1 STK | LED or
13 | 8 | STK | LED gn |  | www.mouser.de | 710-151051VS04000 |  | 0.219 | 1 | LED 5MM | 1.7520 | 710-151051VS04000 | 8 STK | LED gn
14 | 8 | STK | LED ge |  | www.mouser.de | 710-151051YS04000 |  | 0.193 | 1 | LED 5MM | 1.5440 | 710-151051YS04000 | 8 STK | LED ge
15 | 12 | STK | LED WS2812B |  | www.mouser.de | 474-COM-16346 |  | 0.455 | 1 | SMD 5050 | 5.4600 | 474-COM-16346 | 12 STK | LED WS2812B
16 | 3 | STK | TRMFN NTR4003 |  | www.mouser.de | 863-NTR4003NT1G |  | 0.298 | 1 | SOT-23 | 0.8940 | 863-NTR4003NT1G | 3 STK | TRMFN NTR4003
17 | 1 | STK | IC 74HC00 |  | www.mouser.de | 595-SN74HC00NE4 |  | 0.525 | 1 | DIP14 | 0.5250 | 595-SN74HC00NE4 | 1 STK | IC 74HC00
18 | 2 | STK | IC 74AHC1G125DBV |  | www.mouser.de | 595-SN74AHC1G125DBVT |  | 0.823 | 1 | SOT23-5 | 1.6460 | 595-SN74AHC1G125DBVT | 2 STK | IC 74AHC1G125DBV
19 | 2 | STK | IC 74HC148N |  | www.mouser.de | 595-SN74HC148N |  | 0.525 | 1 | DIP16 | 1.0500 | 595-SN74HC148N | 2 STK | IC 74HC148N
20 | 1 | STK | IC ADC088S052 |  | www.mouser.de | 926-AD088S052CIMTNPB |  | 3.89 | 1 | TSSOP16 | 3.8900 | 926-AD088S052CIMTNPB | 1 STK | IC ADC088S052
21 | 2 | STK | IC MCP23S08SO |  | www.mouser.de | 579-MCP23S08-E/SO |  | 1.36 | 1 | SO18W | 2.7200 | 579-MCP23S08-E/SO | 2 STK | IC MCP23S08SO
22 | 1 | STK | IC STP16CP05TTR |  | www.mouser.de | 511-STP16CP05TTR |  | 1.75 |  | TSSOP24 | 0.0000 | 511-STP16CP05TTR | 0 STK | IC STP16CP05TTR
23 | 1 | STK | MOD ESP32 |  | www.mouser.de |  |  |  |  | DevKitC, 2xH19 RM2,54 D25,4
24 | 1 | STK | MOD PCM5102 |  | www.amazon.de | https://www.amazon.de/-/en/Hojffuue-PCM5102-Digital-Analogue-Converter/dp/B09FZCQWZR |  | 12.68 | 1 | 1xH06 | 12.6800 | https://www.amazon.de/-/en/Hojffuue-PCM5102-Digital-Analogue-Converter/dp/B09FZCQWZR | 1 STK | MOD PCM5102
25 | 3 | STK | DISP HD-H103 |  | www.mouser.de |  |  |  |  | HDSP-E
26 | 1 | STK | SW EC11E09244AQ |  | www.mouser.de | 688-EC11E09244AQ |  | 4.860 | 1 | EC11E | 4.8600 | 688-EC11E09244AQ | 1 STK | SW EC11E09244AQ
27 | 14 | STK | SW |  | www.mouser.de | 179-TS016673BK260D |  | 0.11 | 10 | B3F-10XX | 2.2000 | 179-TS016673BK260D | 20 STK | SW
28 | 2 | STK | CON FE19 |  | www.amazon.de | https://www.amazon.de/-/en/gp/product/B07VNXL5BD/ref=ewc_pr_img_1?smid=A2VP41F3CQXNC&psc=1 |  |  | 1 | FE19 RM2,54
29 | 1 | STK | CON FE06 |  | www.amazon.de | https://www.amazon.de/-/en/gp/product/B07VNXL5BD/ref=ewc_pr_img_1?smid=A2VP41F3CQXNC&psc=1 |  |  | 0 | FE06 RM2,54
30 | 1 | STK | CON MA06 |  | www.amazon.de | https://www.amazon.de/-/en/gp/product/B07VNXL5BD/ref=ewc_pr_img_1?smid=A2VP41F3CQXNC&psc=1 |  |  | 0 | MA06 RM2,54

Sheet: Stückliste (1)
1 | 2 | 3 | 4 |  | 5 |  |  |  |  | 6 |  | 7
Lfd. Nr. | Stück- zahl | Ein- heit | Benennung |  | Lieferant / Bestellnummer |  |  |  |  | MCd |  | Bemerkung
1 | 8 | STK | RES 100R |  | www.mouser.de 652-CR0805JW-101ELF |  |  |  |  | 1000 |  | SMD 0805
2 | 2 | STK | RES 1k |  | www.mouser.de 652-CR0805FX-1001ELF |  |  |  |  | 1001 |  | SMD 0805
3 | 1 | STK | RES 2k7 |  | www.mouser.de 652-CR0805FX-2701ELF |  |  |  |  | 2701 |  | SMD 0805
4 | 6 | STK | RES 10k |  | www.mouser.de 652-CR0805FX-1002ELF |  |  |  |  | 1002 |  | SMD 0805
5 | 3 | STK | RES 100k |  | www.mouser.de 652-CR0805FX-1003ELF |  |  |  |  | 1003 |  | SMD 0805
6 | 8 | STK | TRIM 10k |  | www.mouser.de 858-P160KN20QA25B10K |  |  |  |  | p160 |  | P160
7 | 16 | STK | CAP 100n |  | www.mouser.de 710-885012207045 |  |  |  |  |  |  | SMD 0805
8 | 2 | STK | CAP 10n |  | www.mouser.de 80-C0805C103K1RAUTO |  |  |  |  |  |  | SMD 0805
9 | 6 | STK | CAP 1u |  | www.mouser.de 963-UMF212B7105MGHT |  |  |  |  |  |  | SMD 0805
10 | 1 | STK | CAP 4u7 |  | www.mouser.de 81-GRM21BR71C475KE1L |  |  |  |  |  |  | SMD 0805
11 | 1 | STK | LED bl |  | www.mouser.de 720-LBQ39EN1P1351 |  |  |  |  |  |  | CHIPLED_1206
12 | 1 | STK | LED or |  | www.mouser.de 720-LOR976-PS-1 |  |  |  |  |  |  | CHIPLED_1206
13 | 8 | STK | LED gn |  | www.mouser.de 710-151051VS04000 |  |  |  |  |  |  | LED 5MM
14 | 8 | STK | LED ge |  | www.mouser.de 710-151051YS04000 |  |  |  |  |  |  | LED 5MM
15 | 12 | STK | LED WS2812B |  | www.mouser.de 474-COM-16346 |  |  |  |  |  |  | SMD 5050
16 | 3 | STK | TRMFN NTR4003 |  | www.mouser.de 863-NTR4003NT1G |  |  |  |  |  |  | SOT-23
17 | 1 | STK | IC 74HC00 |  | www.mouser.de 595-SN74HC00NE4 |  |  |  |  |  |  | DIP14
18 | 2 | STK | IC 74AHC1G125DBV |  | www.mouser.de 595-SN74AHC1G125DBVT |  |  |  |  |  |  | SOT23-5
19 | 2 | STK | IC 74HC148N |  | www.mouser.de 595-SN74HC148N |  |  |  |  |  |  | DIP16
20 | 1 | STK | IC ADC088S052 |  | www.mouser.de 926-AD088S052CIMTNPB |  |  |  |  |  |  | TSSOP16
21 | 2 | STK | IC MCP23S08SO |  | www.mouser.de 579-MCP23S08-E/SO |  |  |  |  |  |  | SO18W
22 | 1 | STK | IC STP16CP05TTR |  | www.mouser.de 511-STP16CP05TTR |  |  |  |  |  |  | TSSOP24
23 | 1 | STK | MOD ESP32 |  | www.mouser.de |  |  |  |  |  |  | DevKitC, 2xH19 RM2,54 D25,4
24 | 1 | STK | MOD PCM5102 |  | www.amazon.de https://www.amazon.de/-/en/Hojffuue-PCM5102-Digital-Analogue-Converter/dp/B09FZCQWZR |  |  |  |  |  |  | 1xH06
25 | 3 | STK | DISP HD-H103 |  | www.mouser.de |  |  |  |  |  |  | HDSP-E
Sachnummer, Dateiname: |  |  |  | Name: |  |  |  | Toleranz: |  |  |  | Werkstoff:
Beilage 3 |  |  |  | Simon Grundner
 |  |  |  | ID-Nr.: | Gez.: | Geprüft: | Betreuer: | Dokumentart:
 |  |  |  | 2AHEL | GruS |  |  | Stückliste
 |  |  |  | Benennung: |  |  |  | Version: |  |  | Revision: |  | Dokumentenstatus:
 |  |  |  | Sequencer |  |  |  | 1.0 |  |  | 1 |  | Fertigung
HTBLuVA Salzburg
 |  |  |  |  |  |  |  | Maßstab: | Spr.: |  | Datum:
Technische Informatik |  |  |  |  |  |  |  | ohne | DE |  | 2022-06-19

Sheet: Stückliste (2)
1 | 2 | 3 | 4 |  | 5 |  |  |  |  | 6 |  | 7
Lfd. Nr. | Stück- zahl | Ein- heit | Benennung |  | Lieferant / Bestellnummer |  |  |  |  | MCd |  | Bemerkung
26 | 1 | STK | SW EC11E09244AQ |  | www.mouser.de 688-EC11E09244AQ |  |  |  |  |  |  | EC11E
27 | 14 | STK | SW |  | www.mouser.de 179-TS016673BK260D |  |  |  |  |  |  | B3F-10XX
28 | 2 | STK | CON FE19 |  | www.amazon.de https://www.amazon.de/-/en/gp/product/B07VNXL5BD/ref=ewc_pr_img_1?smid=A2VP41F3CQXNC&psc=1 |  |  |  |  |  |  | FE19 RM2,54
29 | 1 | STK | CON FE06 |  | www.amazon.de https://www.amazon.de/-/en/gp/product/B07VNXL5BD/ref=ewc_pr_img_1?smid=A2VP41F3CQXNC&psc=1 |  |  |  |  |  |  | FE06 RM2,54
30 | 1 | STK | CON MA06 |  | www.amazon.de https://www.amazon.de/-/en/gp/product/B07VNXL5BD/ref=ewc_pr_img_1?smid=A2VP41F3CQXNC&psc=1 |  |  |  |  |  |  | MA06 RM2,54
Sachnummer, Dateiname: |  |  |  | Name: |  |  |  | Toleranz: |  |  |  | Werkstoff:
Beilage 3 |  |  |  | Simon Grundner
 |  |  |  | ID-Nr.: | Gez.: | Geprüft: | Betreuer: | Dokumentart:
 |  |  |  | 2AHEL | GruS |  |  | Stückliste
 |  |  |  | Benennung: |  |  |  | Version: |  |  | Revision: |  | Dokumentenstatus:
 |  |  |  | Sequencer |  |  |  | 1.0 |  |  | 1 |  | Fertigung
HTBLuVA Salzburg
 |  |  |  |  |  |  |  | Maßstab: | Spr.: |  | Datum:
Technische Informatik |  |  |  |  |  |  |  | ohne | DE |  | 2022-06-19

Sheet: Stückliste (3)
1 | 2 | 3 | 4 |  | 5 |  |  |  |  | 6 |  | 7
Lfd. Nr. | Stück- zahl | Ein- heit | Benennung |  | Lieferant / Bestellnummer |  |  |  |  | MCd |  | Bemerkung
Sachnummer, Dateiname: |  |  |  | Name: |  |  |  | Toleranz: |  |  |  | Werkstoff:
Beilage 3 |  |  |  | Simon Grundner
 |  |  |  | ID-Nr.: | Gez.: | Geprüft: | Betreuer: | Dokumentart:
 |  |  |  | 2AHEL | GruS |  |  | Stückliste
 |  |  |  | Benennung: |  |  |  | Version: |  |  | Revision: |  | Dokumentenstatus:
 |  |  |  | Sequencer |  |  |  | 1.0 |  |  | 1 |  | Fertigung
HTBLuVA Salzburg
 |  |  |  |  |  |  |  | Maßstab: | Spr.: |  | Datum:
Technische Informatik |  |  |  |  |  |  |  | ohne | DE |  | 2022-06-19

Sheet: Stückliste (4)
1 | 2 | 3 | 4 |  | 5 |  |  |  |  | 6 |  | 7
Lfd. Nr. | Stück- zahl | Ein- heit | Benennung |  | Lieferant / Bestellnummer |  |  |  |  | MCd |  | Bemerkung
Sachnummer, Dateiname: |  |  |  | Name: |  |  |  | Toleranz: |  |  |  | Werkstoff:
Beilage 3 |  |  |  | Simon Grundner
 |  |  |  | ID-Nr.: | Gez.: | Geprüft: | Betreuer: | Dokumentart:
 |  |  |  | 2AHEL | GruS |  |  | Stückliste
 |  |  |  | Benennung: |  |  |  | Version: |  |  | Revision: |  | Dokumentenstatus:
 |  |  |  | Sequencer |  |  |  | 1.0 |  |  | 1 |  | Fertigung
HTBLuVA Salzburg
 |  |  |  |  |  |  |  | Maßstab: | Spr.: |  | Datum:
Technische Informatik |  |  |  |  |  |  |  | ohne | DE |  | 2022-06-19

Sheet: Stückliste (5)
1 | 2 | 3 | 4 |  | 5 |  |  |  |  | 6 |  | 7
Lfd. Nr. | Stück- zahl | Ein- heit | Benennung |  | Lieferant / Bestellnummer |  |  |  |  | MCd |  | Bemerkung
Sachnummer, Dateiname: |  |  |  | Name: |  |  |  | Toleranz: |  |  |  | Werkstoff:
Beilage 3 |  |  |  | Simon Grundner
 |  |  |  | ID-Nr.: | Gez.: | Geprüft: | Betreuer: | Dokumentart:
 |  |  |  | 2AHEL | GruS |  |  | Stückliste
 |  |  |  | Benennung: |  |  |  | Version: |  |  | Revision: |  | Dokumentenstatus:
 |  |  |  | Sequencer |  |  |  | 1.0 |  |  | 1 |  | Fertigung
HTBLuVA Salzburg
 |  |  |  |  |  |  |  | Maßstab: | Spr.: |  | Datum:
Technische Informatik |  |  |  |  |  |  |  | ohne | DE |  | 2022-06-19

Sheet: Materialkalkulation (1)
1 | 2 | 3 | 4 |  |  | 5 |  |  |  |  |  |  | 6
Lfd. Nr. | Stück- zahl | Ein- heit | Benennung |  |  | Lieferant / Bestellnummer |  |  |  |  |  |  | Preis
 |  |  |  |  |  |  |  |  |  |  |  |  | Einzel
1 | 8 | STK | RES 100R |  |  | www.mouser.de / 652-CR0805JW-101ELF |  |  |  |  |  |  | 0.041
2 | 2 | STK | RES 1k |  |  | www.mouser.de / 652-CR0805FX-1001ELF |  |  |  |  |  |  | 0.088
3 | 1 | STK | RES 2k7 |  |  | www.mouser.de / 652-CR0805FX-2701ELF |  |  |  |  |  |  | 0.088
4 | 6 | STK | RES 10k |  |  | www.mouser.de / 652-CR0805FX-1002ELF |  |  |  |  |  |  | 0.024
5 | 3 | STK | RES 100k |  |  | www.mouser.de / 652-CR0805FX-1003ELF |  |  |  |  |  |  | 0.020
6 | 8 | STK | TRIM 10k |  |  | www.mouser.de / 858-P160KN20QA25B10K |  |  |  |  |  |  | 0.919
7 | 16 | STK | CAP 100n |  |  | www.mouser.de / 710-885012207045 |  |  |  |  |  |  | 0.047
8 | 2 | STK | CAP 10n |  |  | www.mouser.de / 80-C0805C103K1RAUTO |  |  |  |  |  |  | 0.051
9 | 6 | STK | CAP 1u |  |  | www.mouser.de / 963-UMF212B7105MGHT |  |  |  |  |  |  | 0.123
10 | 1 | STK | CAP 4u7 |  |  | www.mouser.de / 81-GRM21BR71C475KE1L |  |  |  |  |  |  | 0.117
11 | 1 | STK | LED bl |  |  | www.mouser.de / 720-LBQ39EN1P1351 |  |  |  |  |  |  | 0.368
12 | 1 | STK | LED or |  |  | www.mouser.de / 720-LOR976-PS-1 |  |  |  |  |  |  | 0.271
13 | 8 | STK | LED gn |  |  | www.mouser.de / 710-151051VS04000 |  |  |  |  |  |  | 0.219
14 | 8 | STK | LED ge |  |  | www.mouser.de / 710-151051YS04000 |  |  |  |  |  |  | 0.193
15 | 12 | STK | LED WS2812B |  |  | www.mouser.de / 474-COM-16346 |  |  |  |  |  |  | 0.455
16 | 3 | STK | TRMFN NTR4003 |  |  | www.mouser.de / 863-NTR4003NT1G |  |  |  |  |  |  | 0.298
17 | 1 | STK | IC 74HC00 |  |  | www.mouser.de / 595-SN74HC00NE4 |  |  |  |  |  |  | 0.525
18 | 2 | STK | IC 74AHC1G125DBV |  |  | www.mouser.de / 595-SN74AHC1G125DBVT |  |  |  |  |  |  | 0.823
19 | 2 | STK | IC 74HC148N |  |  | www.mouser.de / 595-SN74HC148N |  |  |  |  |  |  | 0.525
20 | 1 | STK | IC ADC088S052 |  |  | www.mouser.de / 926-AD088S052CIMTNPB |  |  |  |  |  |  | 3.890
21 | 2 | STK | IC MCP23S08SO |  |  | www.mouser.de / 579-MCP23S08-E/SO |  |  |  |  |  |  | 1.360
22 | 1 | STK | IC STP16CP05TTR |  |  | www.mouser.de / 511-STP16CP05TTR |  |  |  |  |  |  | 1.750
23 | 1 | STK | MOD ESP32 |  |  | www.mouser.de /
24 | 1 | STK | MOD PCM5102 |  |  | www.amazon.de / https://www.amazon.de/-/en/Hojffuue-PCM5102-Digital-Analogue-Converter/dp/B09FZCQWZR |  |  |  |  |  |  | 12.680
25 | 3 | STK | DISP HD-H103 |  |  | www.mouser.de /
26 | 1 | STK | SW EC11E09244AQ |  |  | www.mouser.de / 688-EC11E09244AQ |  |  |  |  |  |  | 4.860
27 | 14 | STK | SW |  |  | www.mouser.de / 179-TS016673BK260D |  |  |  |  |  |  | 0.110
28 | 2 | STK | CON FE19 |  |  | www.amazon.de / https://www.amazon.de/-/en/gp/product/B07VNXL5BD/ref=ewc_pr_img_1?smid=A2VP41F3CQXNC&psc=1
29 | 1 | STK | CON FE06 |  |  | www.amazon.de / https://www.amazon.de/-/en/gp/product/B07VNXL5BD/ref=ewc_pr_img_1?smid=A2VP41F3CQXNC&psc=1
30 | 1 | STK | CON MA06 |  |  | www.amazon.de / https://www.amazon.de/-/en/gp/product/B07VNXL5BD/ref=ewc_pr_img_1?smid=A2VP41F3CQXNC&psc=1
 |  |  |  |  |  | Übertrag:
 |  |  |  |  |  | Materialpreis |  |  |  |  |  |  | €50.807
 |  |  |  |  |  | Materialgemeinkosten (10%) |  |  |  |  |  |  | €5.081
 |  |  |  |  |  | Materialverkaufspreis |  |  |  |  |  |  | €55.888
Sachnummer, Dateiname: |  |  |  | Name: |  |  |  |  | Toleranz: |  |  | Werkstoff:
Beilage 10 |  |  |  | Simon Grundner
 |  |  |  | ID-Nr.: | Gez.: |  | Geprüft: | Betreuer: | Dokumentart:
 |  |  |  | 2AHEL | GruS |  |  |  | Materialkalkulation
 |  |  |  | Benennung: |  |  |  |  | Version: |  | Revision: |  | Dokumentenstatus:
 |  |  |  | Sequencer |  |  |  |  | 1.0 |  | 1 |  | Fertigung
HTBLuVA Salzburg
 |  |  |  |  |  |  |  |  | Maßstab: | Spr.: | Datum:
Technische Informatik |  |  |  |  |  |  |  |  | ohne | DE | 2022-06-19

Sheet: Materialkalkulation (2)
1 | 2 | 3 | 4 |  |  | 5 |  |  |  |  |  |  | 6
Lfd. Nr. | Stück- zahl | Ein- heit | Benennung |  |  | Lieferant / Bestellnummer |  |  |  |  |  |  | Preis
 |  |  |  |  |  |  |  |  |  |  |  |  | Einzel
 |  |  |  |  |  | Übertrag: |  |  |  |  |  |  | €55.888
 |  |  |  |  |  | Materialpreis |  |  |  |  |  |  | €0.000
 |  |  |  |  |  | Materialgemeinkosten (10%) |  |  |  |  |  |  | €0.000
 |  |  |  |  |  | Materialverkaufspreis |  |  |  |  |  |  | €55.888
Sachnummer, Dateiname: |  |  |  | Name: |  |  |  |  | Toleranz: |  |  | Werkstoff:
Beilage 10 |  |  |  | Simon Grundner
 |  |  |  | ID-Nr.: | Gez.: |  | Geprüft: | Betreuer: | Dokumentart:
 |  |  |  | 2AHEL | GruS |  |  |  | Materialkalkulation
 |  |  |  | Benennung: |  |  |  |  | Version: |  | Revision: |  | Dokumentenstatus:
 |  |  |  | Sequencer |  |  |  |  | 1.0 |  | 1 |  | Fertigung
HTBLuVA Salzburg
 |  |  |  |  |  |  |  |  | Maßstab: | Spr.: | Datum:
Technische Informatik |  |  |  |  |  |  |  |  | ohne | DE | 2022-06-19

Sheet: Materialkalkulation (3)
1 | 2 | 3 | 4 |  |  | 5 |  |  |  |  |  |  | 6
Lfd. Nr. | Stück- zahl | Ein- heit | Benennung |  |  | Lieferant / Bestellnummer |  |  |  |  |  |  | Preis
 |  |  |  |  |  |  |  |  |  |  |  |  | Einzel
 |  |  |  |  |  | Übertrag: |  |  |  |  |  |  | €55.888
 |  |  |  |  |  | Materialpreis |  |  |  |  |  |  | €0.000
 |  |  |  |  |  | Materialgemeinkosten (10%) |  |  |  |  |  |  | €0.000
 |  |  |  |  |  | Materialverkaufspreis |  |  |  |  |  |  | €55.888
Sachnummer, Dateiname: |  |  |  | Name: |  |  |  |  | Toleranz: |  |  | Werkstoff:
Beilage 10 |  |  |  | Simon Grundner
 |  |  |  | ID-Nr.: | Gez.: |  | Geprüft: | Betreuer: | Dokumentart:
 |  |  |  | 2AHEL | GruS |  |  |  | Materialkalkulation
 |  |  |  | Benennung: |  |  |  |  | Version: |  | Revision: |  | Dokumentenstatus:
 |  |  |  | Sequencer |  |  |  |  | 1.0 |  | 1 |  | Fertigung
HTBLuVA Salzburg
 |  |  |  |  |  |  |  |  | Maßstab: | Spr.: | Datum:
Technische Informatik |  |  |  |  |  |  |  |  | ohne | DE | 2022-06-19
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

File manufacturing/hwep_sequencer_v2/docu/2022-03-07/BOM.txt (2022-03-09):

Stückliste exportiert aus C:/Users/Smon/source/HWEP/eagle/hwep_sequencer_v2/Beilage.sch am 07.03.2022 22:36

Qty Value         Device          Package             Parts                                                                        Description                                                                                             ARROW_PART_NUMBER   ARROW_PRICE-STOCK                                                                 CATEGORY DESCRIPTION                                                                                             HEIGHT MANUFACTURER_NAME MANUFACTURER_PART_NUMBER MF MOUSER_PART_NUMBER   MOUSER_PRICE-STOCK                                                                                               MPN OC_FARNELL OC_NEWARK POPULARITY
1                 FE06-1          FE06                X2                                                                           FEMALE HEADER                                                                                                                                                                                                 18                                                                                                                                                                                                                                                                                                                                             
3                 HD-H103         HDSP-E              H15, H16, H17                                                                LED DISPLAY                                                                                                                                                                                                   15                                                                                                                                                                                                                                                                                                              unknown    unknown   0         
2                 JUMPSMD1FACH-1  MYLIB_SJ            X3, X4                                                                       SMD solder JUMPER                                                                                                                                                                                             18                                                                                                                                                                                                                                                                                                                                             
14                TASTE10XX       B3F-10XX            S1, S2, S3, S4, S5, S6, S7, S8, S9, S10, S12, S13, S14, S15                  OMRON SWITCH                                                                                                                                                                                                  17                                                                                                                                                                                                                                                                                                                                             
8   100R          R-EU_R0805      R0805               R21, R22, R23, R24, R25, R26, R27, R28                                       RESISTOR, European symbol                                                                                                                                                                                                                                                                                                                                                                                                                                                                                                                                    
3   100k          R-EUSR0805      R0805               R29, R30, R31                                                                RESISTOR, European symbol                                                                                                                                                                                                                                                                                                                                                                                                                                                                                                                                    
16  100n          C-EUC0805       C0805               C5, C6, C10, C11, C12, C13, C14, C15, C16, C17, C18, C19, C20, C21, C22, C25 CAPACITOR, European symbol                                                                                                                                                                                    2                                                                                                                                                                                                                                                                                                                                              
8   10k           P160LB          P160LB              R1, R2, R3, R4, R5, R6, R7, R8                                               Datasheet P160                                                                                                                                                                                                                                                                                                                                                                                                                                                                                                                                               
2   10n           C-EUC0805       C0805               C3, C4                                                                       CAPACITOR, European symbol                                                                                                                                                                                    2                                                                                                                                                                                                                                                                                                                                              
2   1k            R-EUSR0805      R0805               R9, R10                                                                      RESISTOR, European symbol                                                                                                                                                                                                                                                                                                                                                                                                                                                                                                                                    
6   1u            C-EUC0805       C0805               C1, C2, C8, C9, C23, C24                                                     CAPACITOR, European symbol                                                                                                                                                                                    2                                                                                                                                                                                                                                                                                                                                              
1   2k7           R-EUSR0805      R0805               R32                                                                          RESISTOR, European symbol                                                                                                                                                                                                                                                                                                                                                                                                                                                                                                                                    
10  47k           R-EUSR0805      R0805               R11, R12, R13, R14, R15, R16, R17, R18, R19, R20                             RESISTOR, European symbol                                                                                                                                                                                                                                                                                                                                                                                                                                                                                                                                    
1   4u7           C-EUC0805       C0805               C7                                                                           CAPACITOR, European symbol                                                                                                                                                                                    2                                                                                                                                                                                                                                                                                                                                              
2   74AHC1G125DBV 74AHC1G125DBV   SOT23-5             D2, D8                                                                       Single Bus Buffer Gate with 3-State Output                                                                                                                                                                    13                                                                                                                                                                                                                                                                                                                                             
1   74HC00N       74HC00N         DIP14               D7                                                                           Quad 2-Input Logic NAND                                                                                                                                                                                       13                                                                                                                                                                                                                                                                                                                                             
2   74HC148N      74HC148N        DIP16               D5, D6                                                                       Priority encoder,SN74HC148N DIL16 25pcs                                                                                                                                                                       13                                                                                                                                                                                                                                                                                                                                             
1   ADC088S052    ADC088S052      TSSOP16             D4                                                                           8-Channel, 200 ksps to 500 ksps, 8-Bit A/D Converter                                                    ADC088S052CIMT/NOPB https://www.arrow.com/en/products/adc088s052cimtnopb/texas-instruments?region=nac 2        8-Channel, 200 ksps to 500 ksps, 8-Bit A/D Converter                                                    1.2mm  Texas Instruments ADC088S052CIMT/NOPB         926-AD088S052CIMTNPB https://www.mouser.co.uk/ProductDetail/Texas-Instruments/ADC088S052CIMT-NOPB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                                    
1   EC11E09244AQ  EC11E09244AQ    EC11                S11                                                                          Alps 9 Pulse Incremental Mechanical Rotary Encoder with a 6 mm Flat Shaft (Not Indexed), Through Hole//                                                                                                       17       Alps 9 Pulse Incremental Mechanical Rotary Encoder with a 6 mm Flat Shaft (Not Indexed), Through Hole// 24.5mm ALPS              EC11E09244AQ                688-EC11E09244AQ     https://www.mouser.com/Search/Refine.aspx?Keyword=688-EC11E09244AQ                                                                                  
1   ESP32CLIP2122 ESP32CLIP2122   ESP32-DEVKIT-C-CLIP X1                                                                                                                                                                                                                                                                                         18                                                                                                                                                                                                                                                                                                                                             
2   MCP23S08SO    MCP23S08SO      SO18W               D1, D3                                                                       8-bit I/O Expander,SPI,MCP23S08-E/SO                                                                    MCP23S08-E/SO       https://www.arrow.com/en/products/mcp23s08-eso/microchip-technology?region=nac    13       8-bit I/O Expander,SPI,MCP23S08-E/SO                                                                    2.65mm Microchip         MCP23S08-E/SO               579-MCP23S08-E/SO    https://www.mouser.co.uk/ProductDetail/Microchip-Technology/MCP23S08-E-SO?qs=Sez7gRs8XSXMFunLZ5Ve%2FA%3D%3D                                         
3   NTR4003       NTR4003         SOT23               V1, V2, V3                                                                   Datasheet                                                                                                                                                                                                     5                                                                                                                                                                                                                                                                                                                                              
1   STP16CP05TTR  STP16CP05TTR    TSSOP24             D9                                                                           STP16CP05                                                                                                                                                                                                     13                                                                                                                                                                                                                                                                                                                                             
12  WS2812B       WS2812B         WS2812B             H3, H4, H5, H6, H7, H8, H9, H10, H11, H12, H13, H14                                                                                                                                                                                                                                        7                                                                                                                                                                                                                                                                                                                                              
1   bl            LEDCHIPLED_1206 CHIPLED_1206        H1                                                                           LED, EN-60617                                                                                                                                                                                                 7                                                                                                                                                                                                                                                                                                                                              
8   ge            LED5MM          LED5MM              H26, H27, H28, H29, H30, H31, H32, H33                                       LED, EN-60617                                                                                                                                                                                                 7                                                                                                                                                                                                                                                                                                                                              
8   gn            LED5MM          LED5MM              H18, H19, H20, H21, H22, H23, H24, H25                                       LED, EN-60617                                                                                                                                                                                                 7                                                                                                                                                                                                                                                                                                                                              
1   gn            LEDCHIPLED_1206 CHIPLED_1206        H2                                                                           LED, EN-60617                                                                                                                                                                                                 7

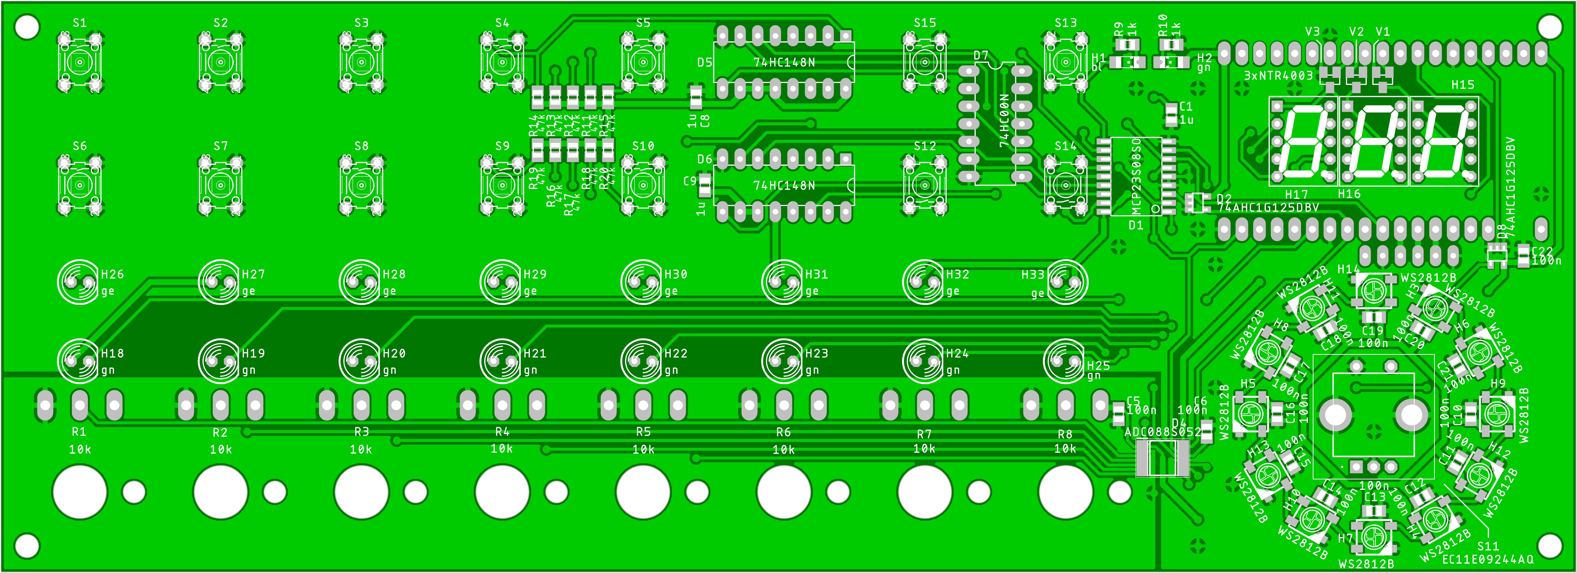
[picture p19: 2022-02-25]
manufacturing/hwep_sequencer_v2/docu/JLC-Order/images/Beilage-pcb-top.png

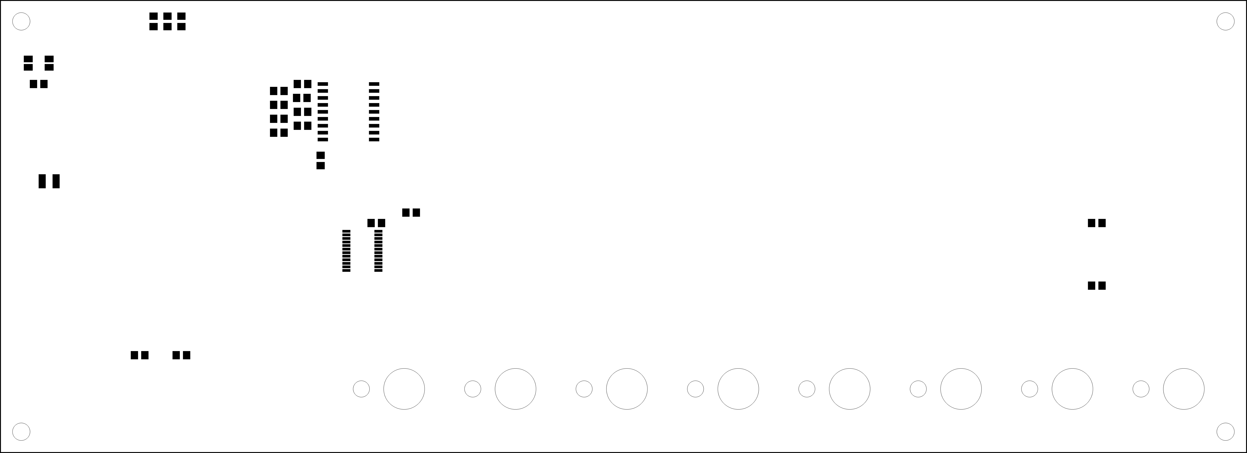
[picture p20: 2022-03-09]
manufacturing/hwep_sequencer_v2/docu/JLC-Order/images/Beilage-paste-bottom.png

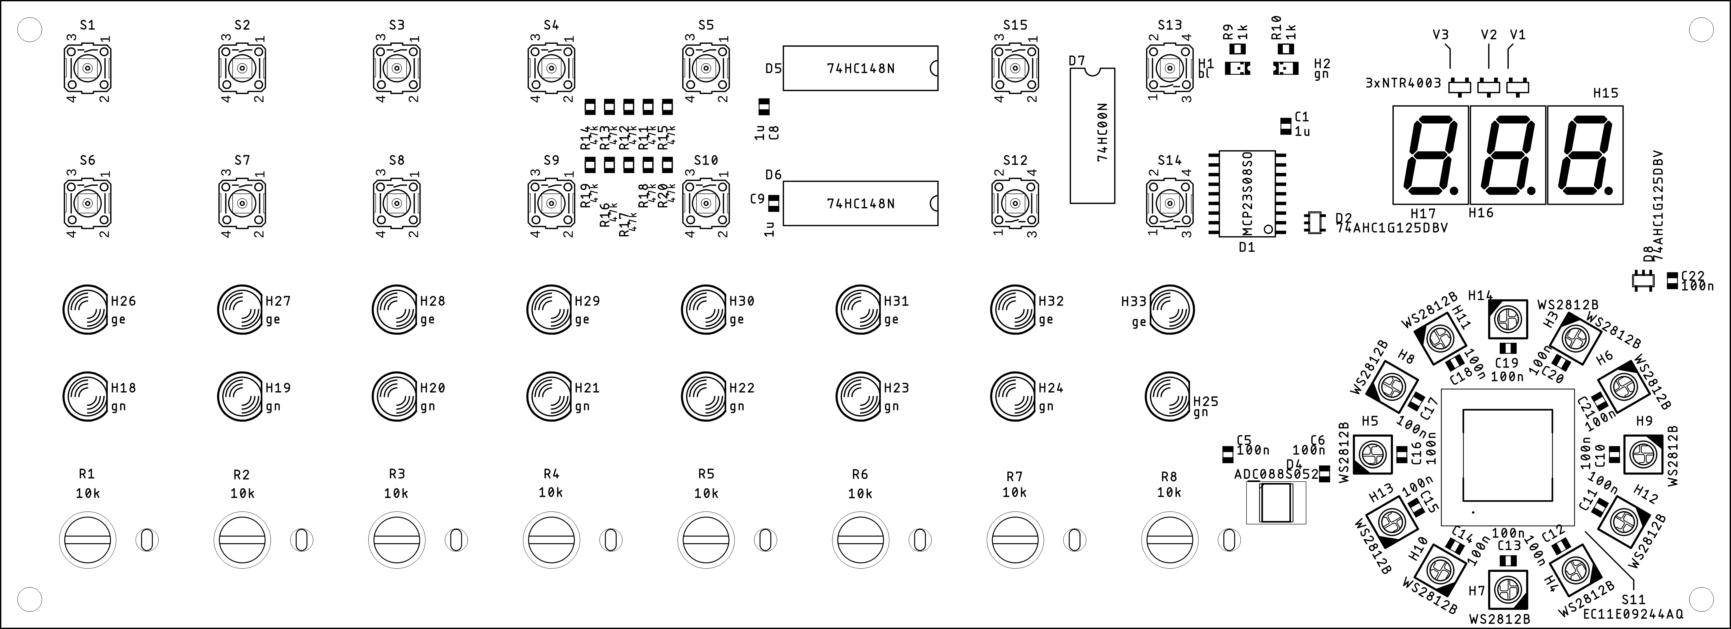
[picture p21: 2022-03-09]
manufacturing/hwep_sequencer_v2/docu/JLC-Order/images/Beilage-parts-top.png

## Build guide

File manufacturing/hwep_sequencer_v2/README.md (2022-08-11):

# Hardware DOCS

## BSB - Blockschaltbild

BSB

## SPL - Schaltplan

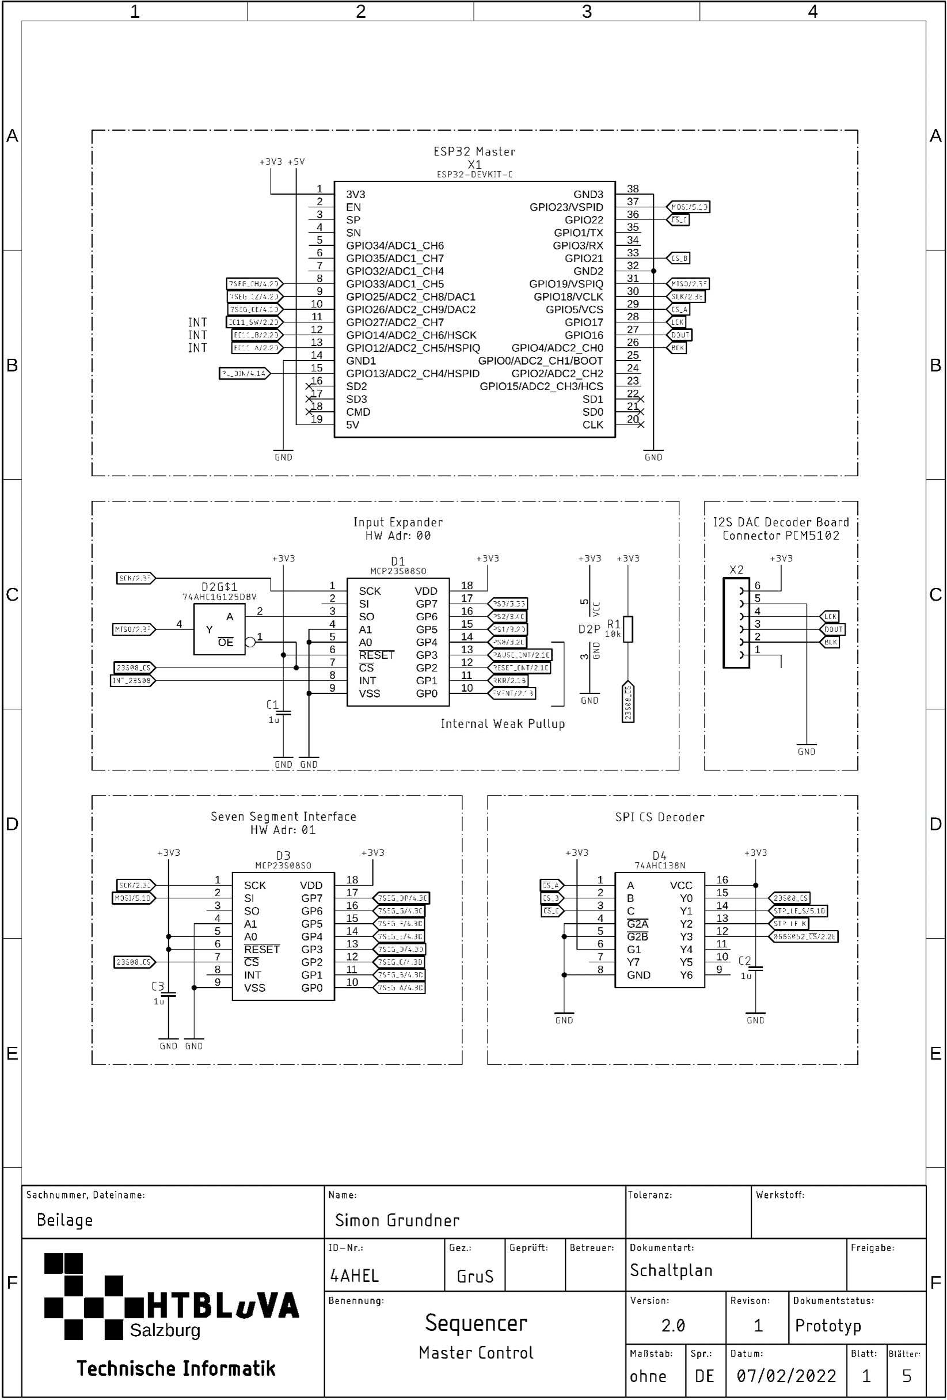
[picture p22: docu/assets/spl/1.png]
spl1

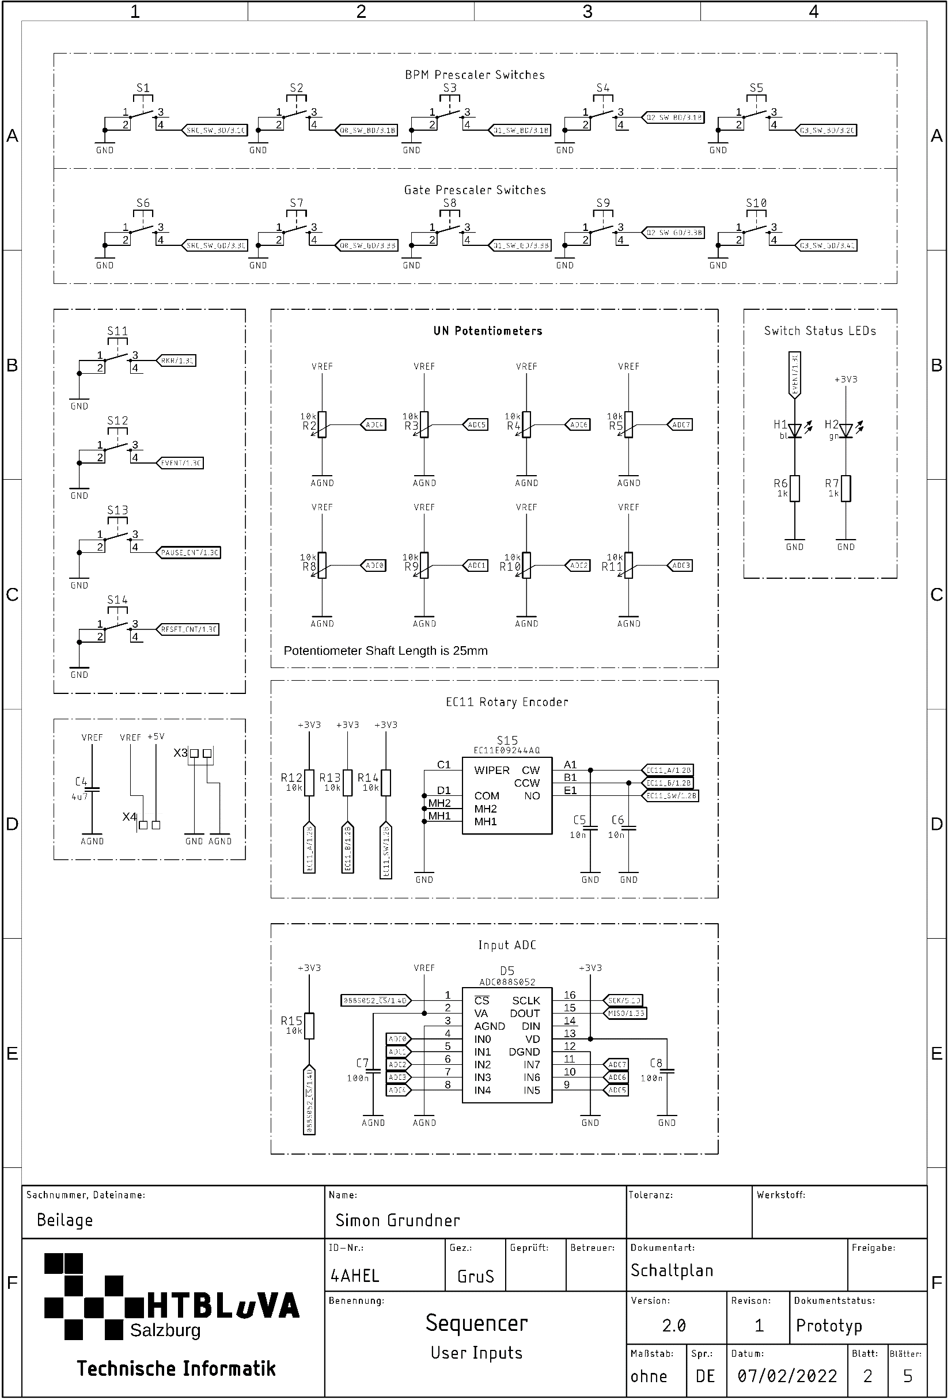
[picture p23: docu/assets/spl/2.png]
spl2

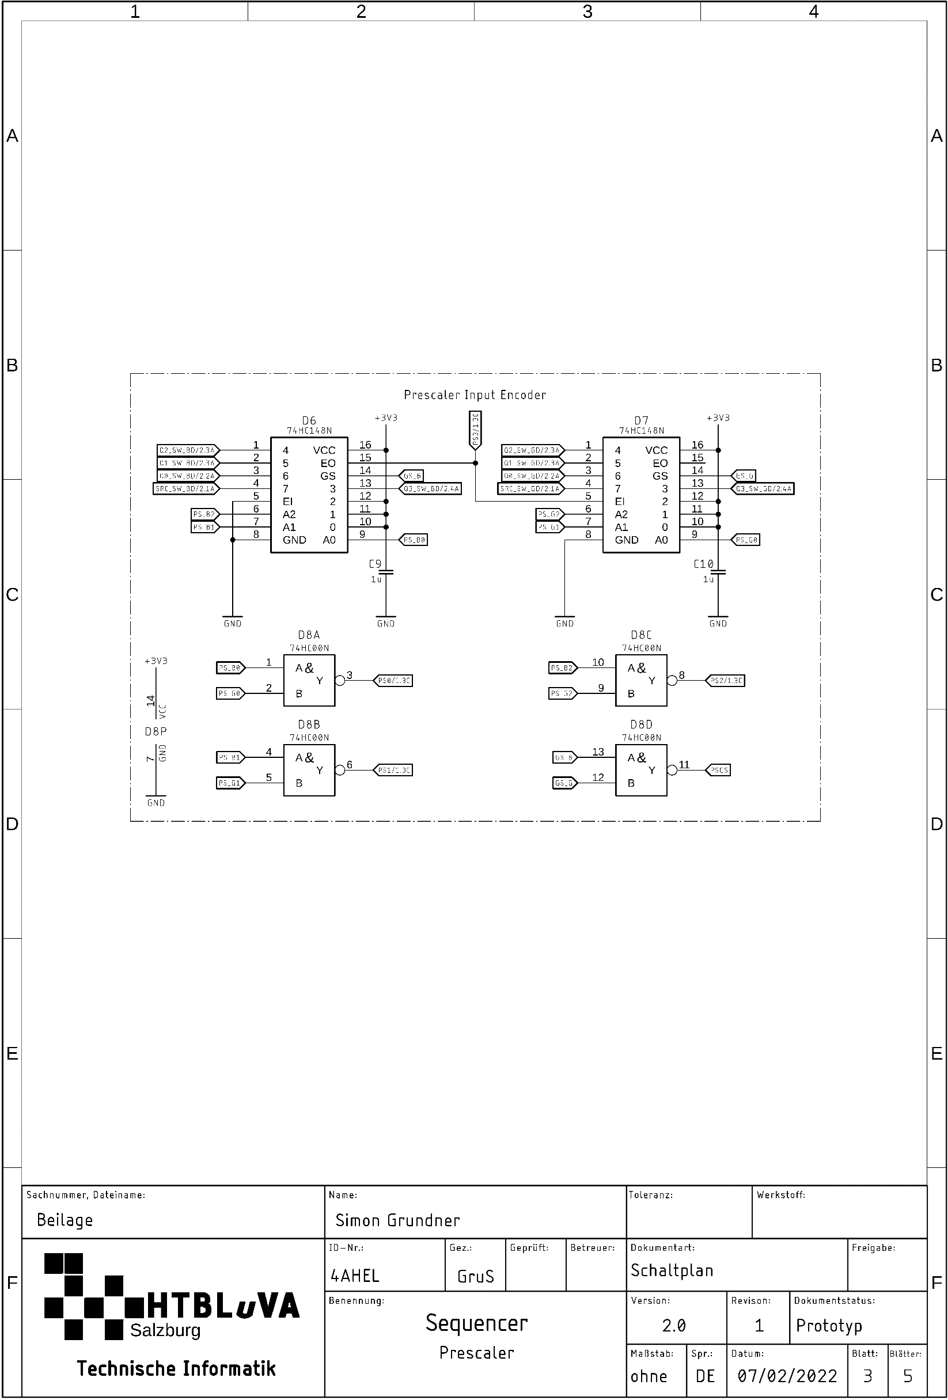
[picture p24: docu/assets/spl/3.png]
spl3

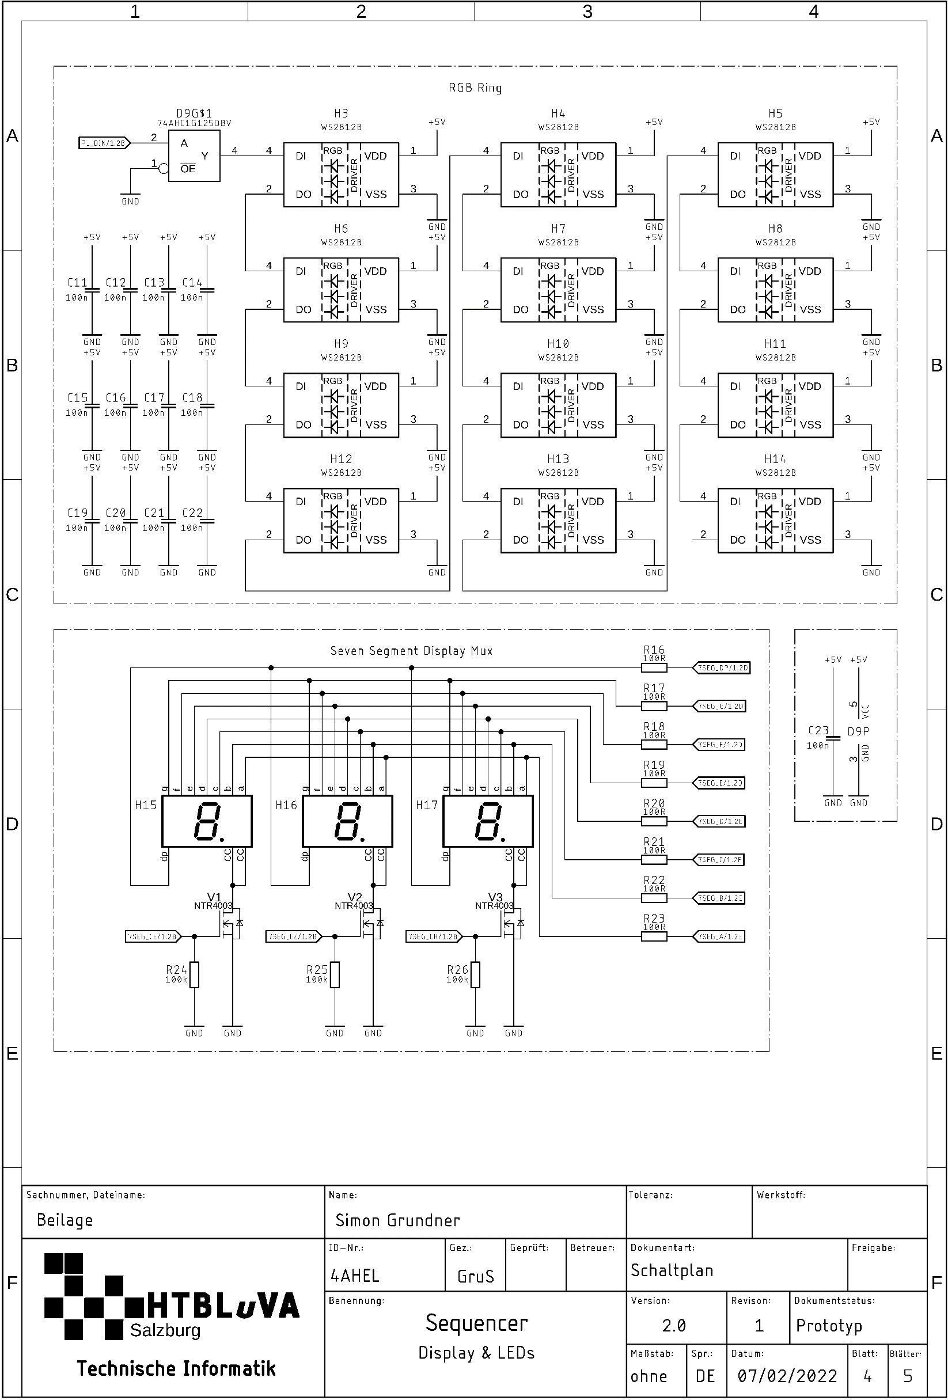
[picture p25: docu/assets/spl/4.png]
spl4

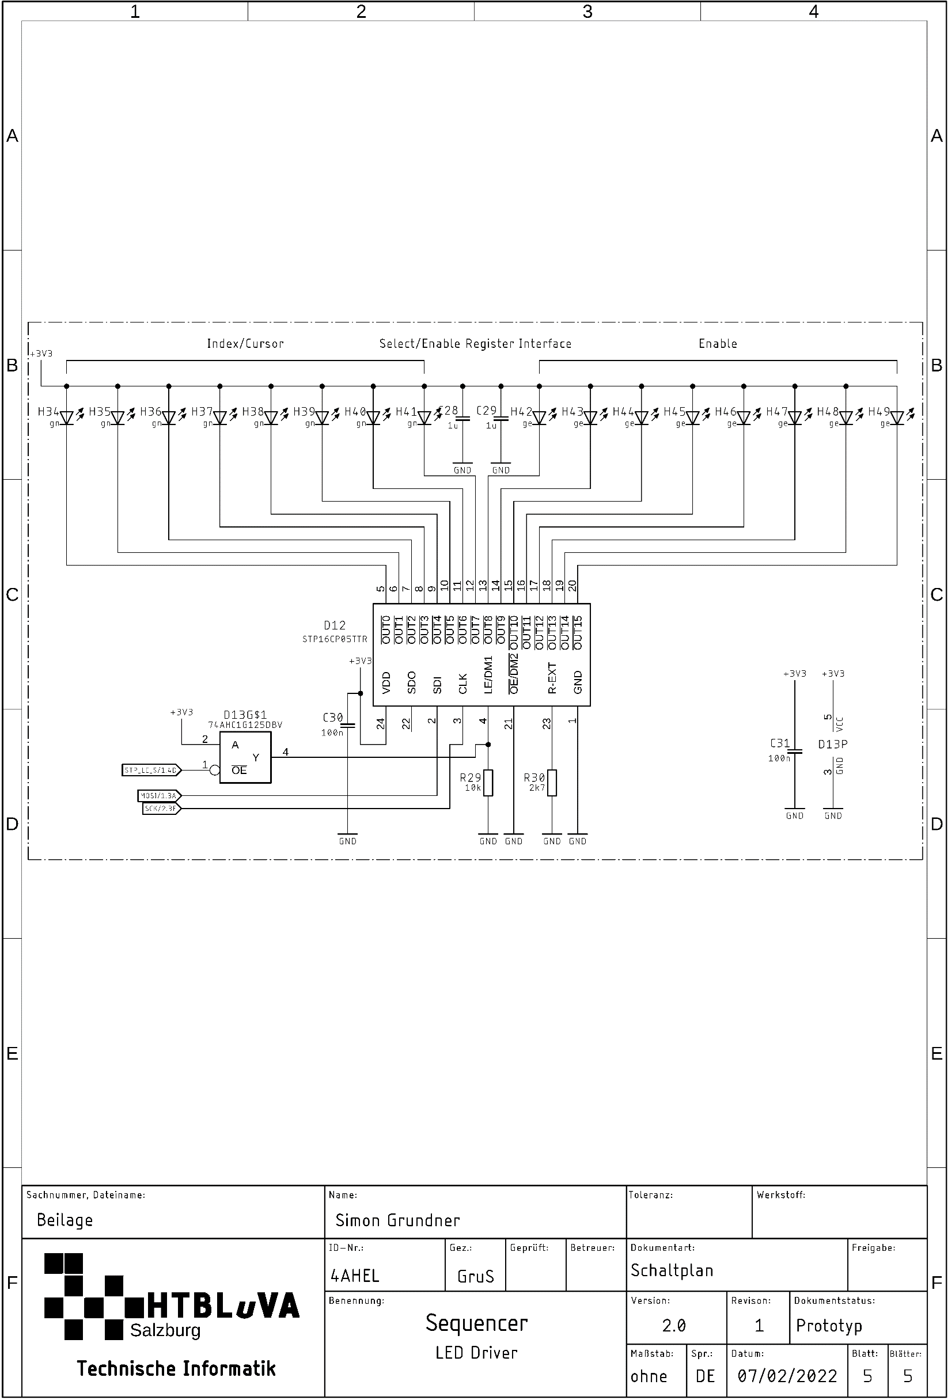
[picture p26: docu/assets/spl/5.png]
spl5


## BSP - Bestückungsplan

### Top
top

### Bottom
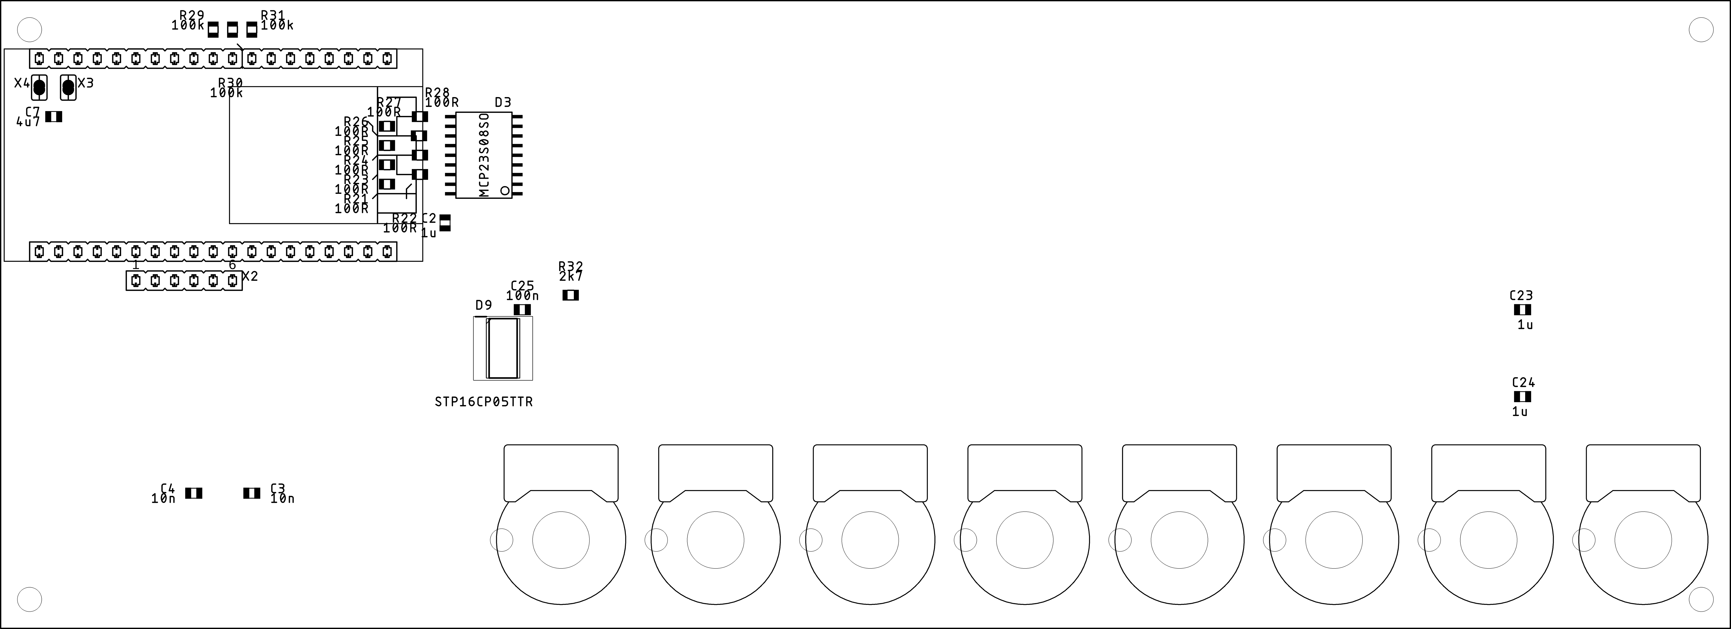
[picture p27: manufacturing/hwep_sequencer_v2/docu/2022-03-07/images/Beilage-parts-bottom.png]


## LAY - Layout

### Top-Layer
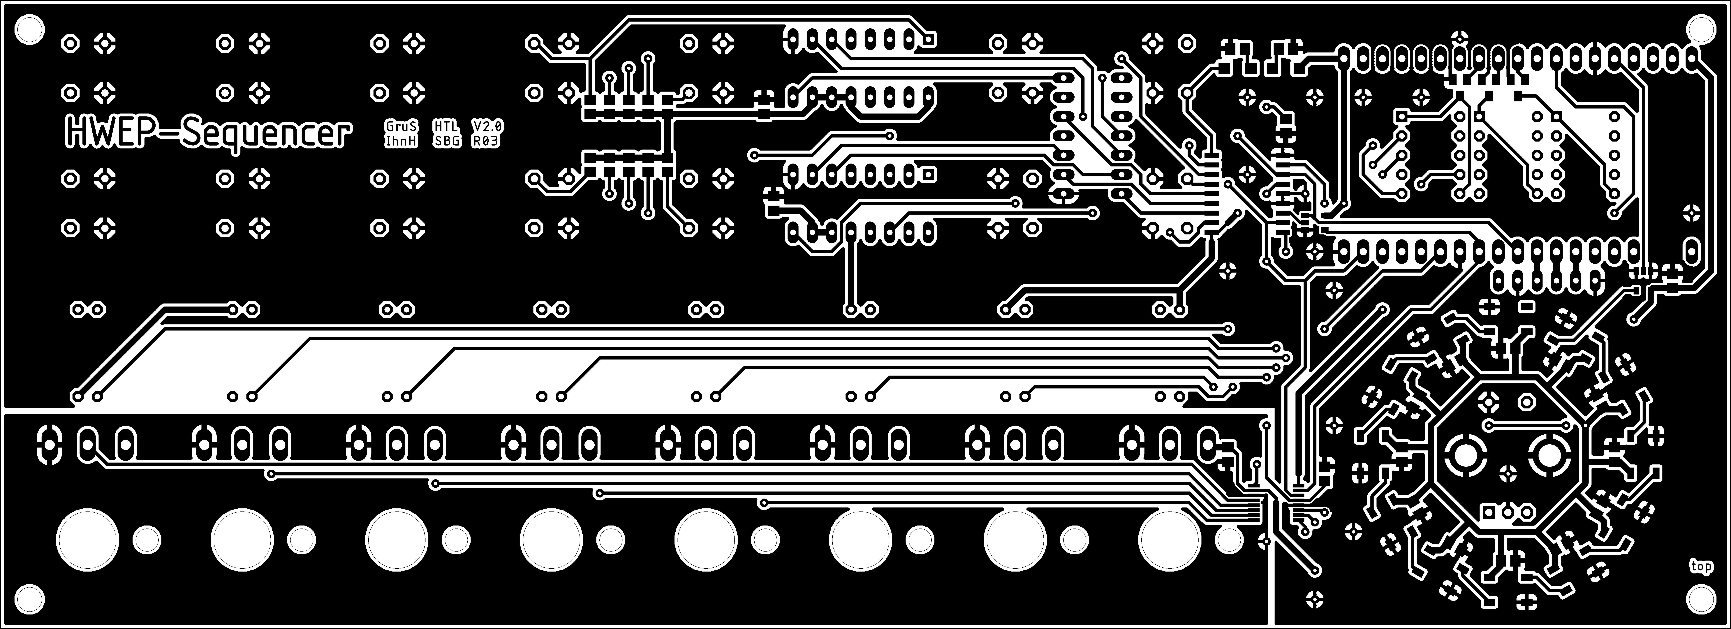
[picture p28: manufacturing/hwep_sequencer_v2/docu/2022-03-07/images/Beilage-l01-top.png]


### Bottom-Layer
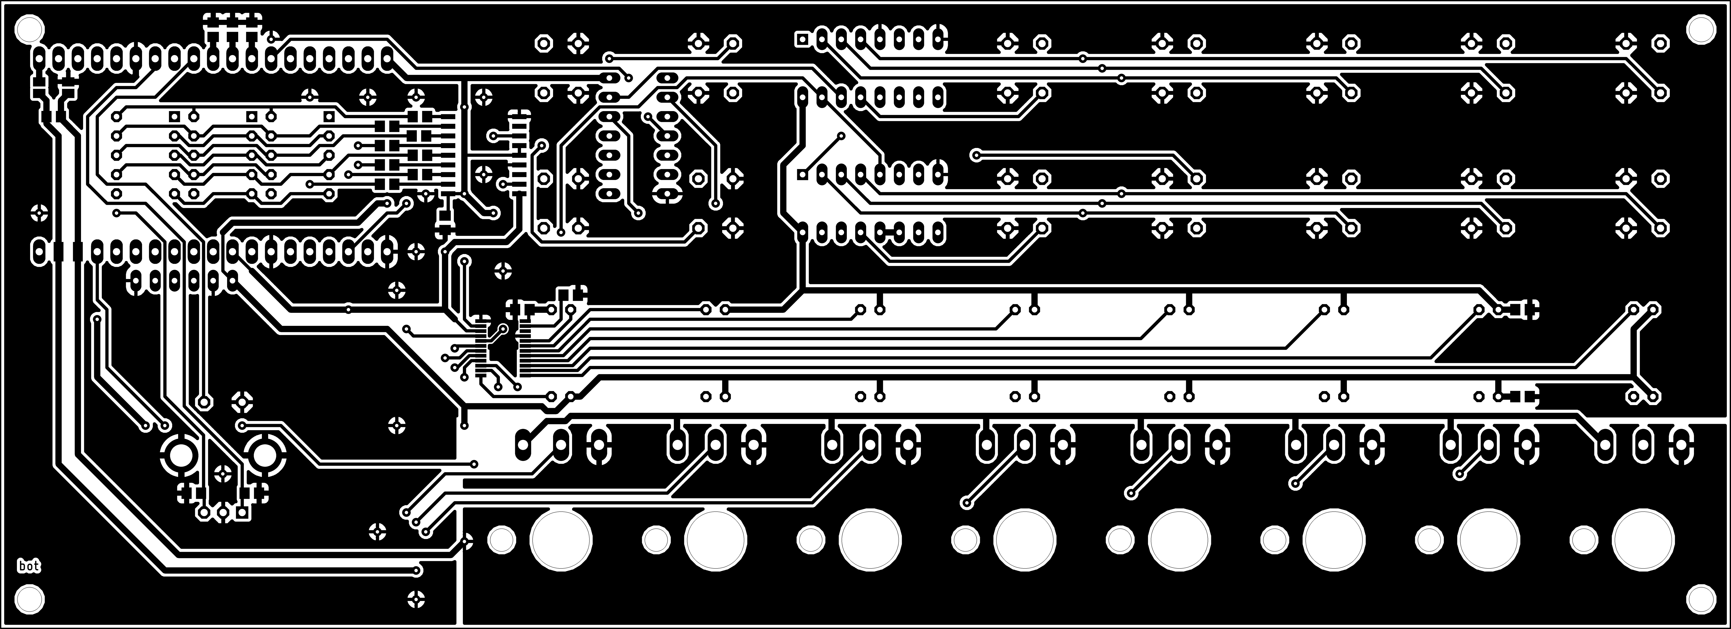
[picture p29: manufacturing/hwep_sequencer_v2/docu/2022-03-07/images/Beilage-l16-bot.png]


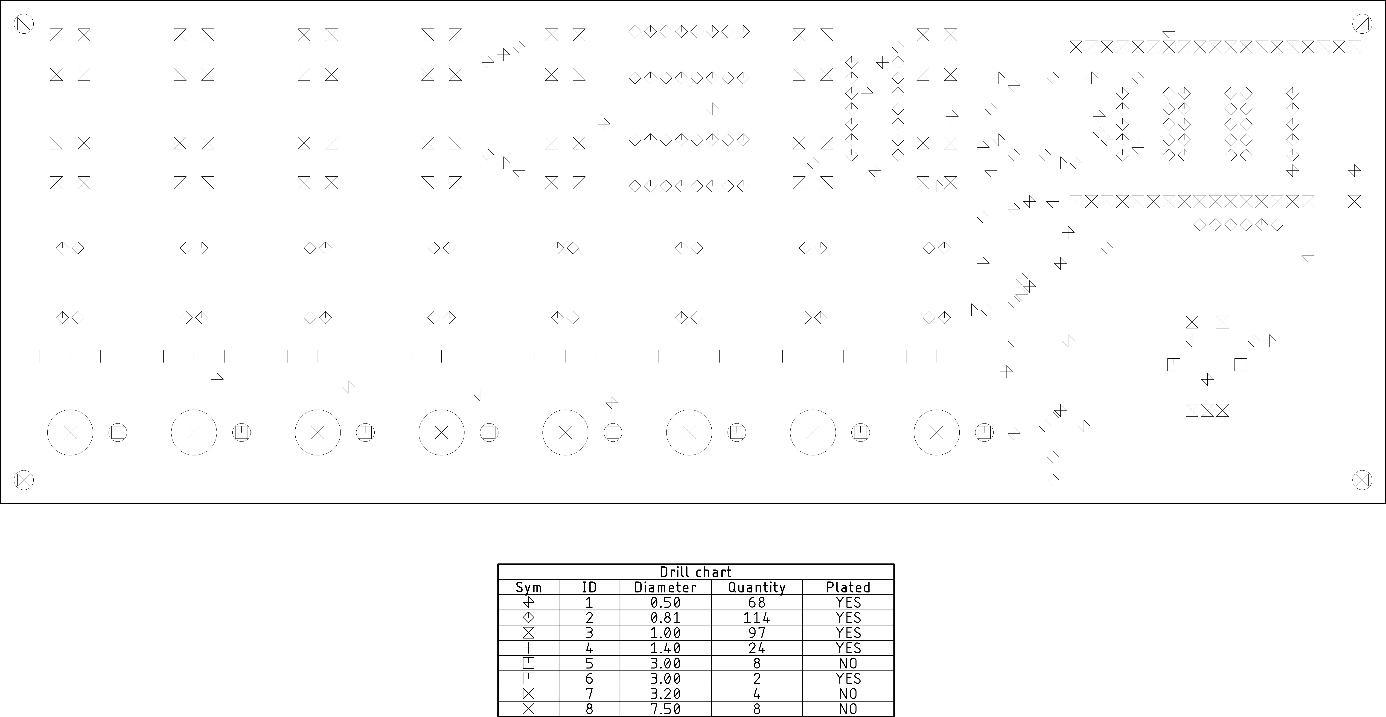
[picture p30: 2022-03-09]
manufacturing/hwep_sequencer_v2/docu/2022-03-07/images/Beilage-fabrication.png

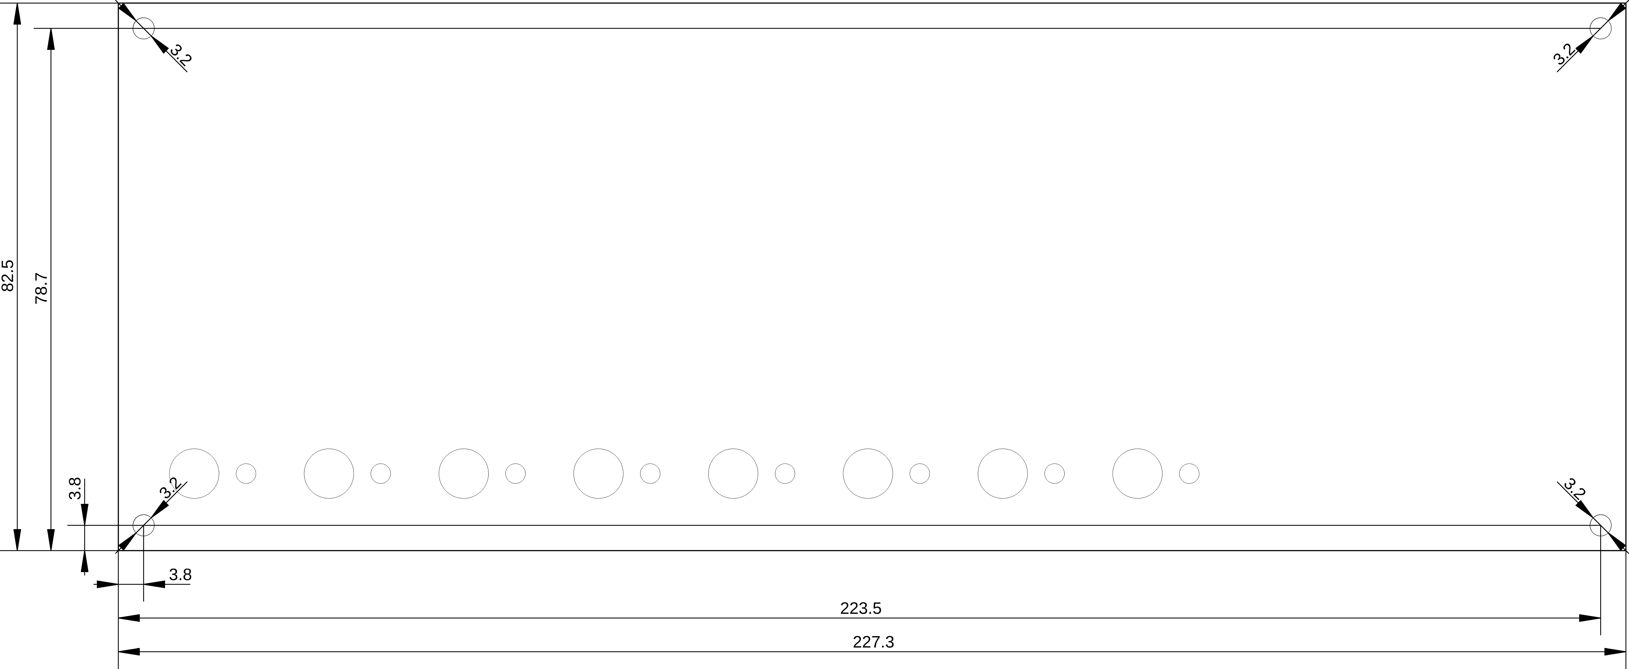
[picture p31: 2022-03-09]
manufacturing/hwep_sequencer_v2/docu/JLC-Order/images/Beilage-construction.png

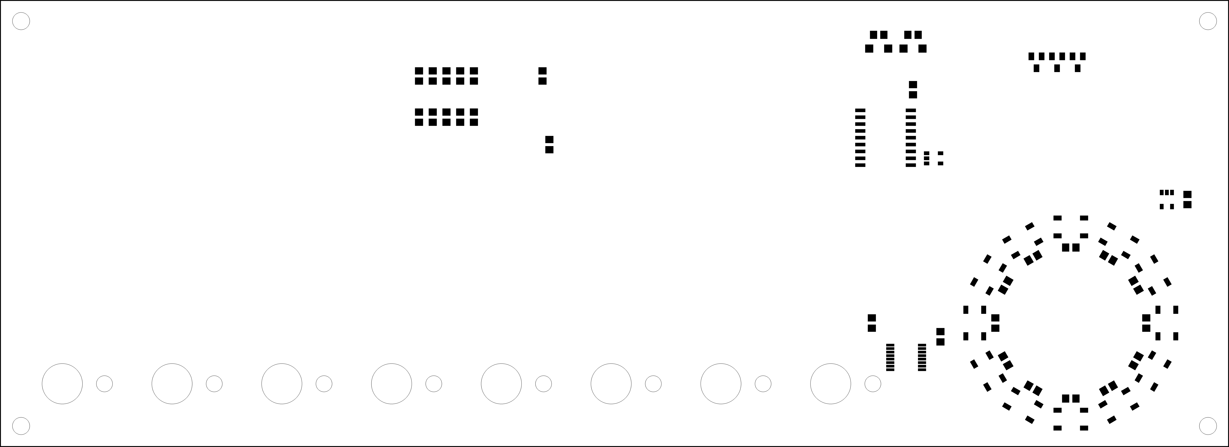
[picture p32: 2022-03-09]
manufacturing/hwep_sequencer_v2/docu/2022-03-07/images/Beilage-paste-top.png

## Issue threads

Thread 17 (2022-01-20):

Frontpanel Layout Sketch in Fusion 360

s-grundner, 2022-01-20:
+ Sketch the holes for Frontpanel
+ Ensure that all Parts are accessible
+ CAD Model via Fusion 360 Version Management and Team Projects on Autodesk Account
+ Adjust height of Potentiometers and Rotary Encoder ( -> Change Part with shorter Shaft if necessary (Part: EC11N1525404))
```
                        ___           ___     <- Level
Poti: 25mm shaft ->    |   |         |   |    <- 20 mm shaft :Rotary Encoder (EC11E09244AQ)
PCB:                ___|___|_________|___|___
                       |   |
```
Max Height shoult be about the same if Potentiometer is directly Panel Mounted on PCB

Closed 2023-07-31.

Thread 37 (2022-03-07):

Prio Encoder in SMD (Version 3)

s-grundner, 2022-03-07:
595-SN74HC148NSR

s-grundner, 2025-04-27:
## Display

Check if Seven Segment wiring/footprint is correct. There had to be hardware rewirings because the wiring is messed up. Carefully check footprint of segment display for pinout and if common anode / cathode

s-grundner, 2025-04-27:
## USB Interface

- Catch Logs
- Read the state of the State-Machine
- Recieve MIDI

s-grundner, 2025-04-27:
## ESP32

- Dont use the DevBoard anymore but Stick with the ESP32-Wroom module, as the features of the ESP-IDF worked quite nicely in this case.
- Update to the current IDF-Version and then **Stick to this Version**. Seriously, Please define the IDF-Version stricktly, as updates are very likely to be incompatible
- Implement own SMPS for Powering the board.

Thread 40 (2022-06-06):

ADC DATA SWAP isn't working. Currupted ADC values

s-grundner, 2022-06-06:
ADC needs to dataswap the values recieved via SPI because the are greater than 1 byte.
For now, the data is not swapped and the values are read incorrectly

s-grundner, 2022-06-14:
i was too stupid to read the whole transaction Array. Problem solved

Closed 2022-06-14.

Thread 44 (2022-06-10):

Debounce Encoder Pushbutton

s-grundner, 2022-06-10:
Bouncing of the encoder affects the user expierience. pls fix

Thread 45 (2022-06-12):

MCP spi transmission bug for input buttons

s-grundner, 2022-06-12:
# issue: ESP Crashes because SPI bus fails to end transaction

␛[0;31mE (15340) spi_master: spi_device_polling_start(926): Cannot send polling transaction while the previous polling transaction is not terminated.␛[0m
ESP_ERROR_CHECK failed: esp_err_t 0x103 (ESP_ERR_INVALID_STATE) at 0x40085310
file: "lib/mcp23s08/mcp23s08.c" line 132
func: mcp23s08_read
expression: err

abort() was called at PC 0x40085313 on core 1

Backtrace:0x400829ab:0x3ffbf9a0 0x40086ad9:0x3ffbf9c0 0x4008c272:0x3ffbf9e0 0x40085313:0x3ffbfa50 0x400d1e7a:0x3ffbfa70 0x400d1504:0x3ffbfac0 0x400d1d0d:0x3ffbfaf0 0x40089625:0x3ffbfb20

ELF file SHA256: 8198769bc07fa498

# Bug reproduction
Spam Direct input buttons (not prio encoded)

s-grundner, 2022-06-12:
Bc mcp_read function is called in an ISR, it can interrupt pending SPI transactions.
a solution would be to implement a Semaphore

s-grundner, 2022-06-12:
https://github.com/espressif/esp-idf/blob/master/examples/peripherals/spi_master/hd_eeprom/components/eeprom/spi_eeprom.c

fix with reference left off at mcp_init .....

s-grundner, 2022-06-14:
refer to new issue #47

Closed 2022-06-14.

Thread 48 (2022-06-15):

Implement RTOS

s-grundner, 2022-06-15:
All spi transactinos are scheduled wrong. especially with interrupts and timers. ESP often crashes and button functionality is restricted.

Queues and Semaphores could come in handy. please refer to API documantaion:
https://docs.espressif.com/projects/esp-idf/en/latest/esp32/api-reference/system/freertos.html#
https://docs.espressif.com/projects/esp-idf/en/latest/esp32/api-reference/system/freertos.html#queue-api
https://docs.espressif.com/projects/esp-idf/en/latest/esp32/api-reference/system/freertos.html#semaphore-api

# todo
 - use Software timer instead of harware timer
 - add Mutex/Semaphore for the SPI bus
 - add `wait_done()` functions to all peripherals to wait until the bus is clear

Closed 2022-06-17.

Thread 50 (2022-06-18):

SPI bus Crashes after a while

s-grundner, 2022-06-18:
occurences increase when toggling LEDS in ENR mode

s-grundner, 2022-06-18:
STP gets its data from quite a few ISRs
Could cause bus to fail

Closed 2022-06-18.

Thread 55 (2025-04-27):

Code Style

s-grundner, 2025-04-27:
# Style optimizations

## sequencer.c

### refresh_task()

1. remove very ugly macro and introduce local varaible:

```c
#define SSEG_H (ctx->sseg_handle)
```

2. Denest code with invertet condition early `continue`, such as:

```c
if (xQueueReceive(refresh_q, &ctx, portMAX_DELAY) == pdFALSE) { continue; }
if (xSemaphoreTake(timer_sem, 3) == pdTRUE) { ... }
```

Section of current implementation.

```c
if (xQueueReceive(refresh_q, &ctx, portMAX_DELAY) == pdTRUE)
{
	if (xSemaphoreTake(timer_sem, 3) == pdTRUE)
	{ ... }}
```

### manage_display()

simplify switch case. only set `str` in cases and finally call seg_write funciton afterwards.

Section of current implementation:

```c
char str[] = "   ";
switch (sqc_handle->cur_appmode)
{
case APP_MODE_BPM:
	// write display data
	sseg_write(sqc_handle->sseg_handle, sqc_handle->btn_shift ? get_wt_name(sqc_handle->osc.wt_index) : itoa(sqc_handle->cur_bpm, str, 10));
	break;
case APP_MODE_KEY:
	// write display data
	sseg_write(sqc_handle->sseg_handle, sqc_handle->btn_shift ? get_modal_name(sqc_handle->cur_modal) : get_key_name(sqc_handle->cur_key));
	break;
case APP_MODE_ENR:
	break;
case APP_MODE_TSP:
	// write display data
	sseg_write(sqc_handle->sseg_handle, sqc_handle->btn_shift ? itoa(sqc_handle->osc.oct_offset, str, 10) : itoa(sqc_handle->osc.transpose, str, 10));
	break;
default:
	break;
}
```

###

## audio_config.h - Convert Waveform Settings to Enum

Current code implementation:

```c
#define SINE_WT 0
#define SAW_WT 1
#define SQUARE_WT 2
#define TRI_WT 3
#define SILENCE 4
#define WAVEFORM_TYPE_COUNT 5
```

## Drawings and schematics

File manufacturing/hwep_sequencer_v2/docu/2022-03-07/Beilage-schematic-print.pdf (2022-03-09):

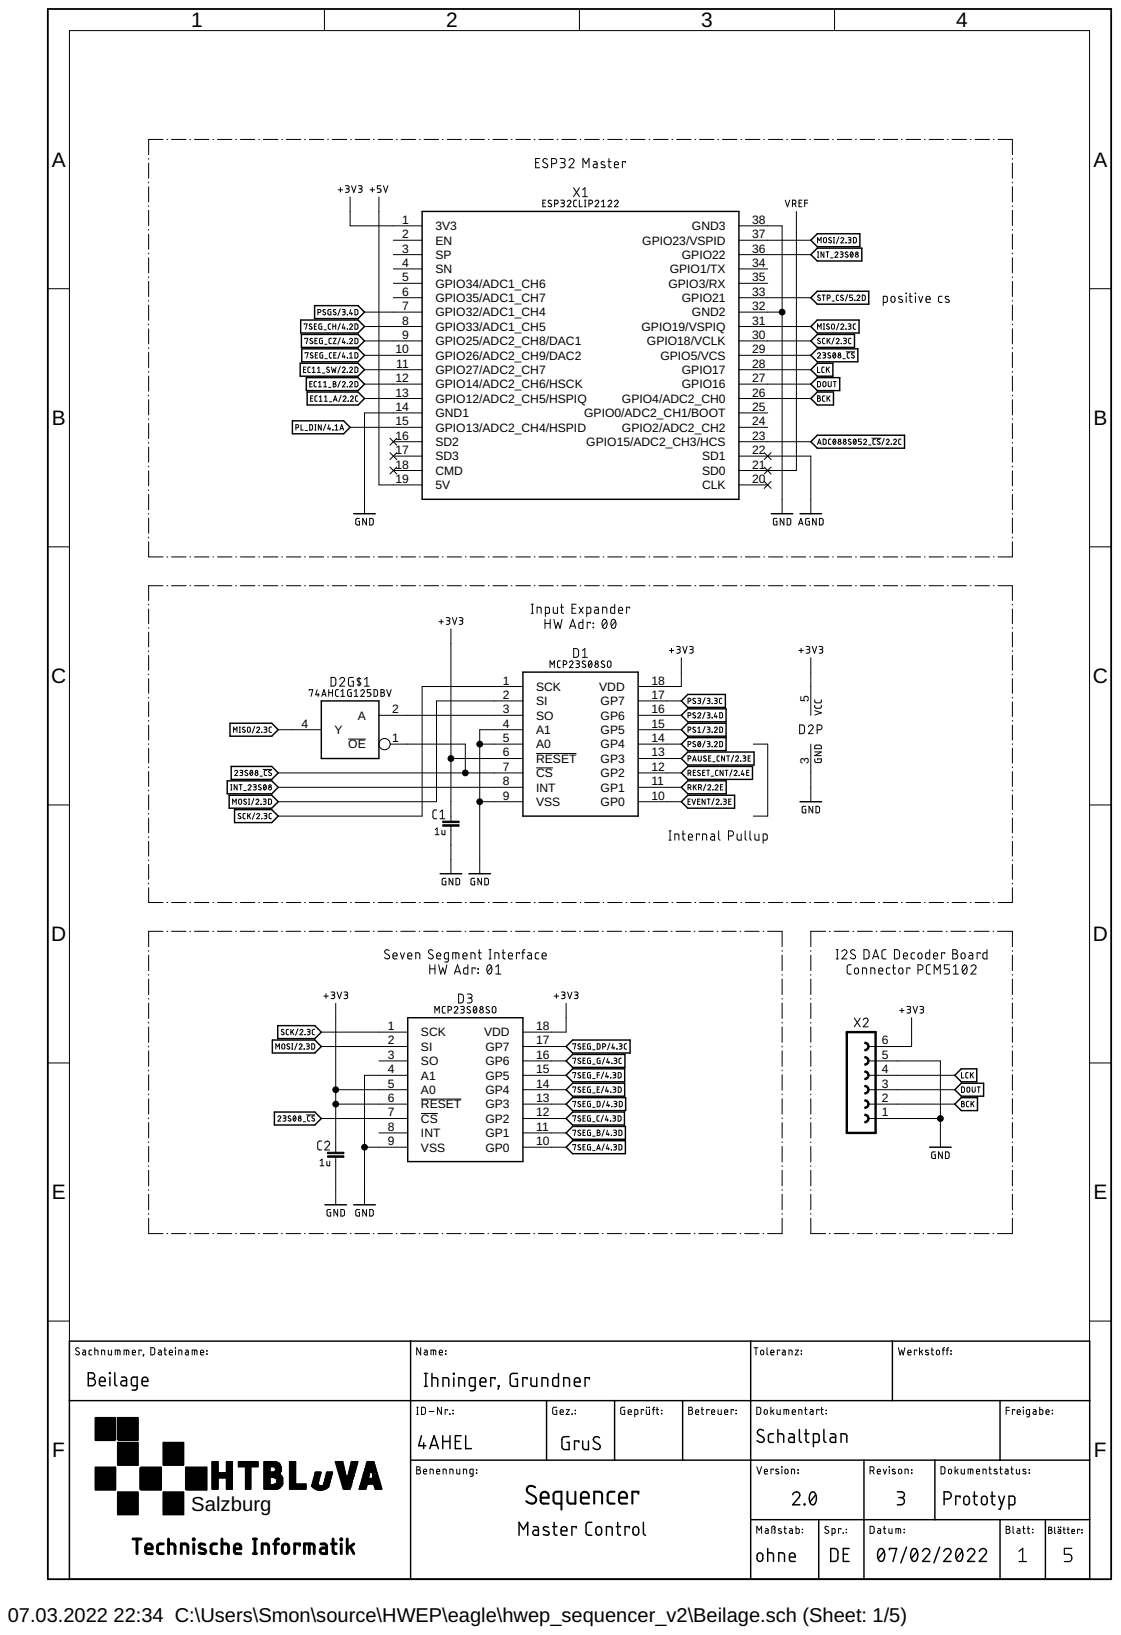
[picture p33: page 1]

36 GPIO23/VSPID

34 GPIO22

22 GPIO15/ADC2_CH3/HCS

07.03.2022 22:34 C:\Users\Smon\source\HWEP\eagle\hwep_sequencer_v2\Beilage.sch (Sheet: 1/5)

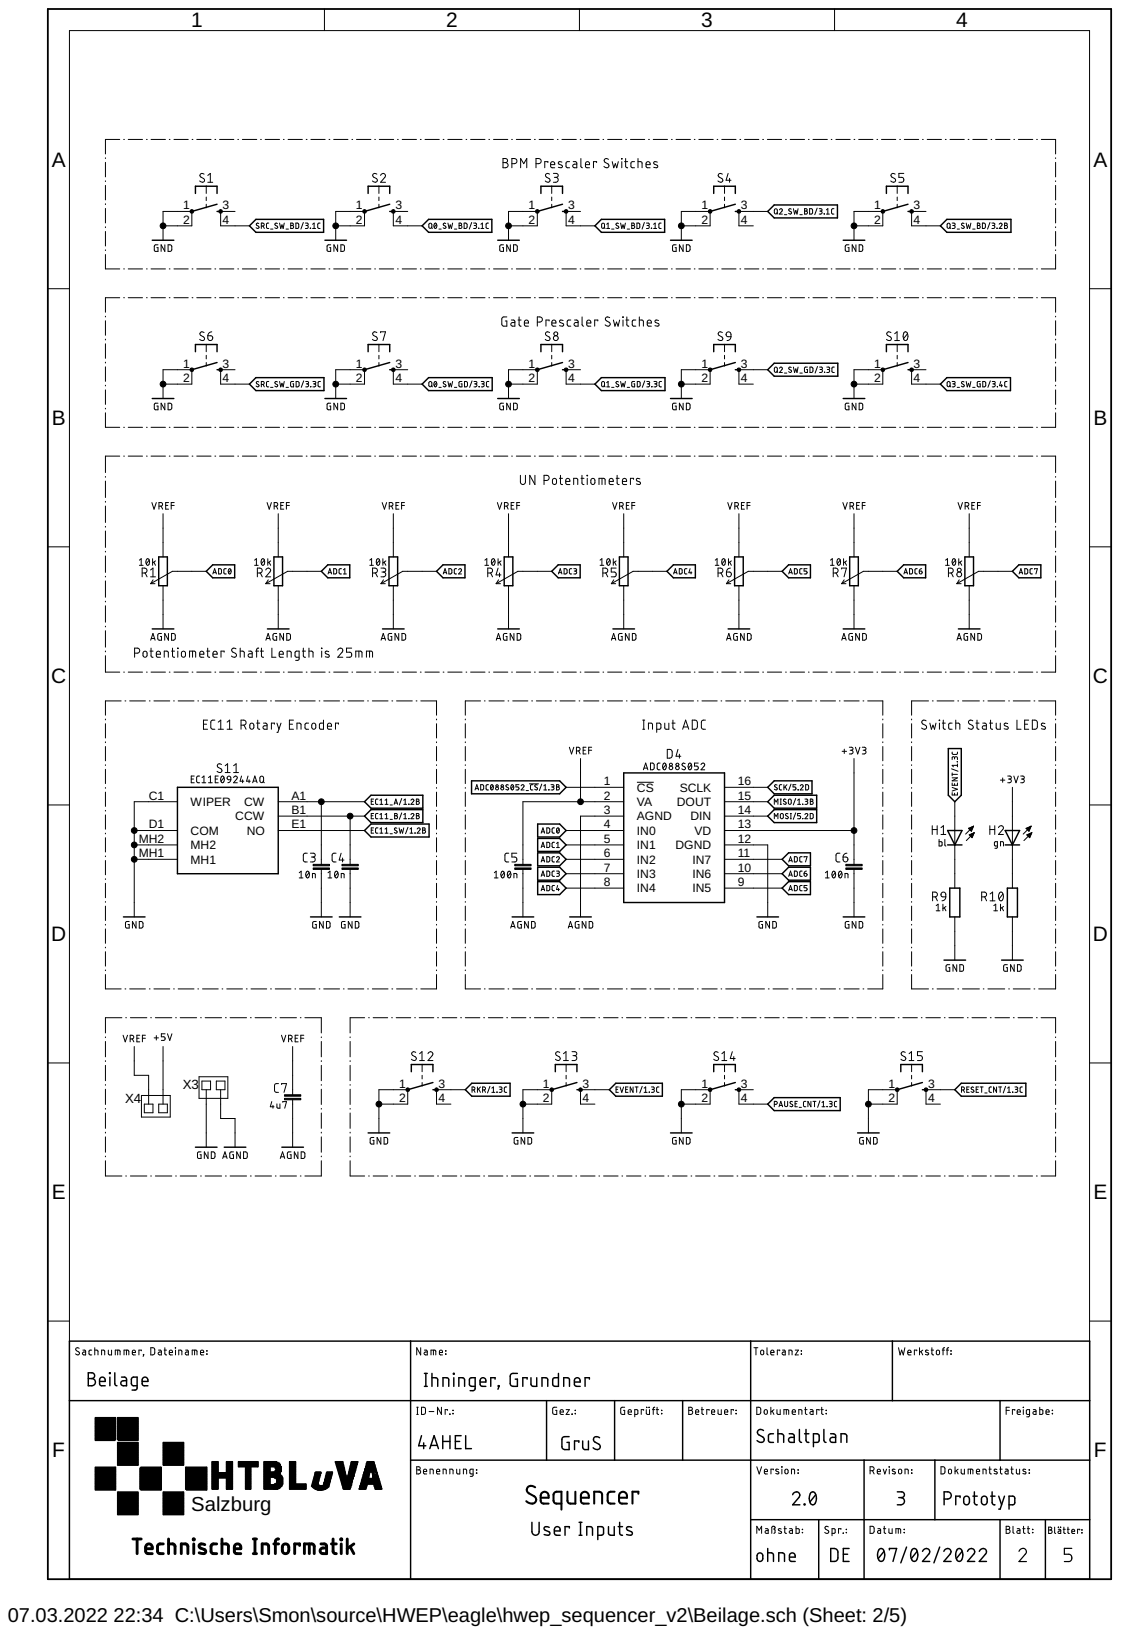
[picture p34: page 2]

6 | 11
7 | 10

07.03.2022 22:34 C:\Users\Smon\source\HWEP\eagle\hwep_sequencer_v2\Beilage.sch (Sheet: 2/5)

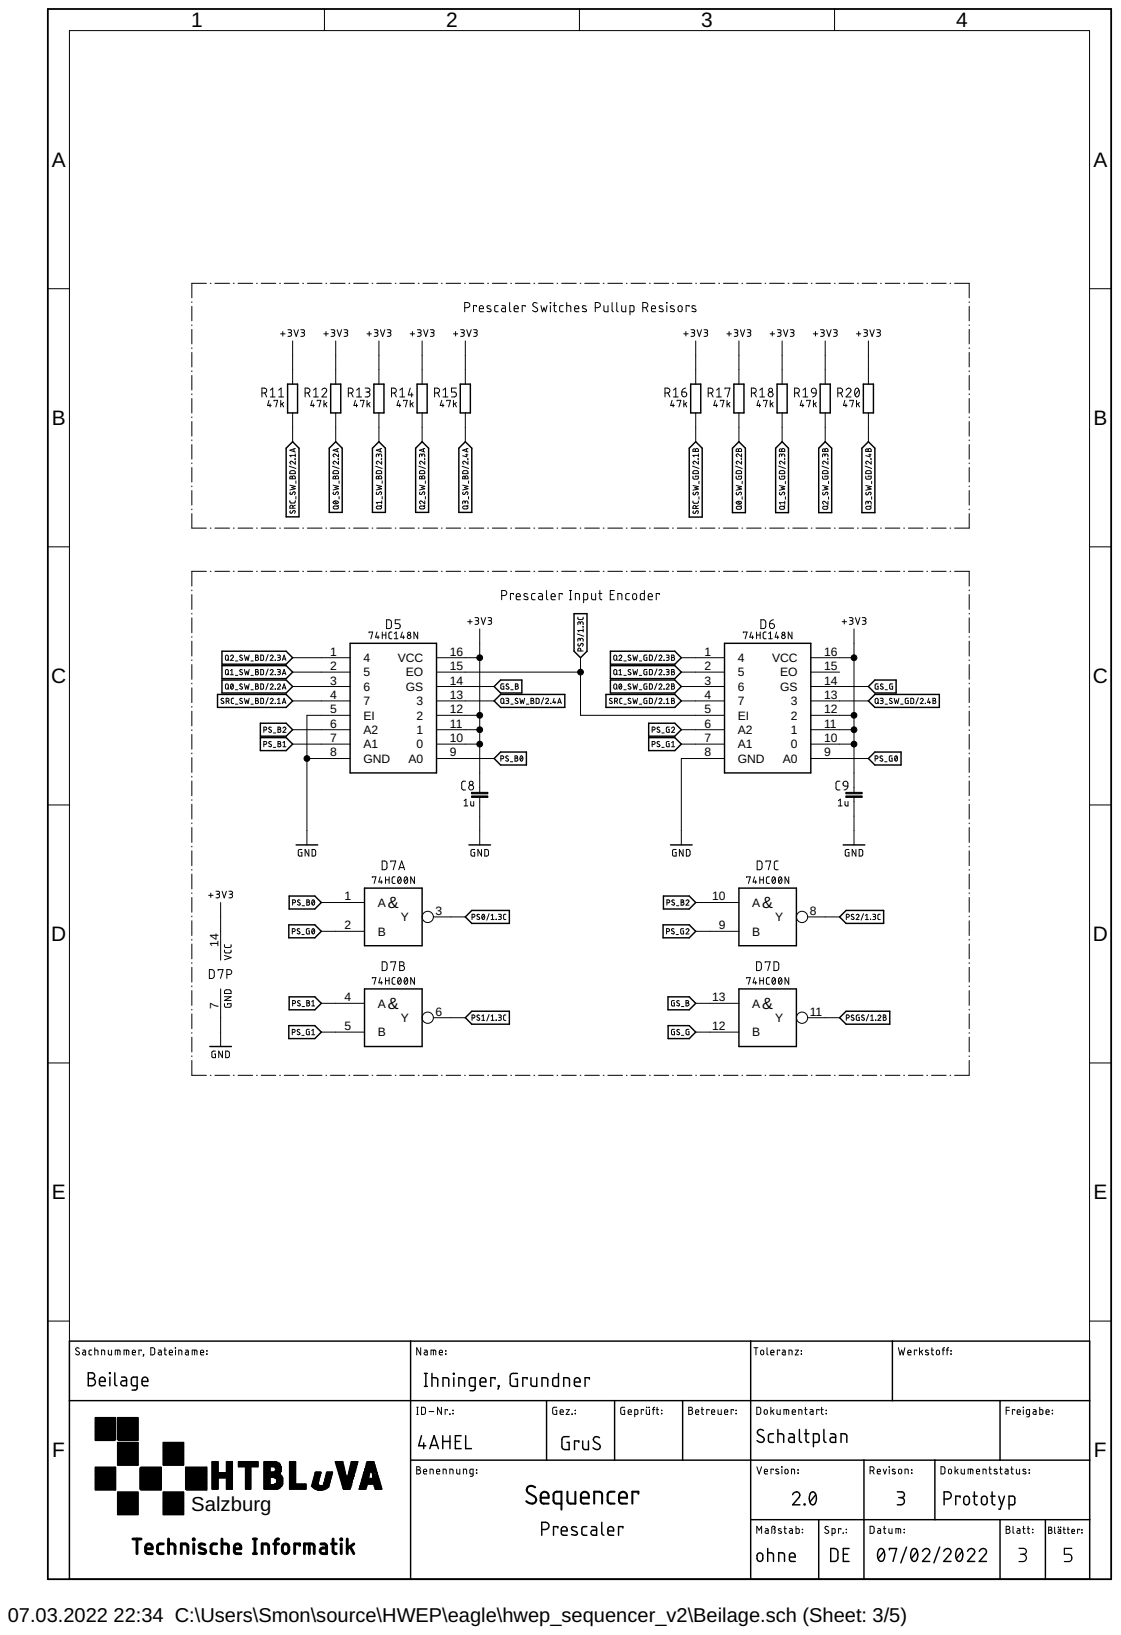
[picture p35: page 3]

07.03.2022 22:34 C:\Users\Smon\source\HWEP\eagle\hwep_sequencer_v2\Beilage.sch (Sheet: 3/5)

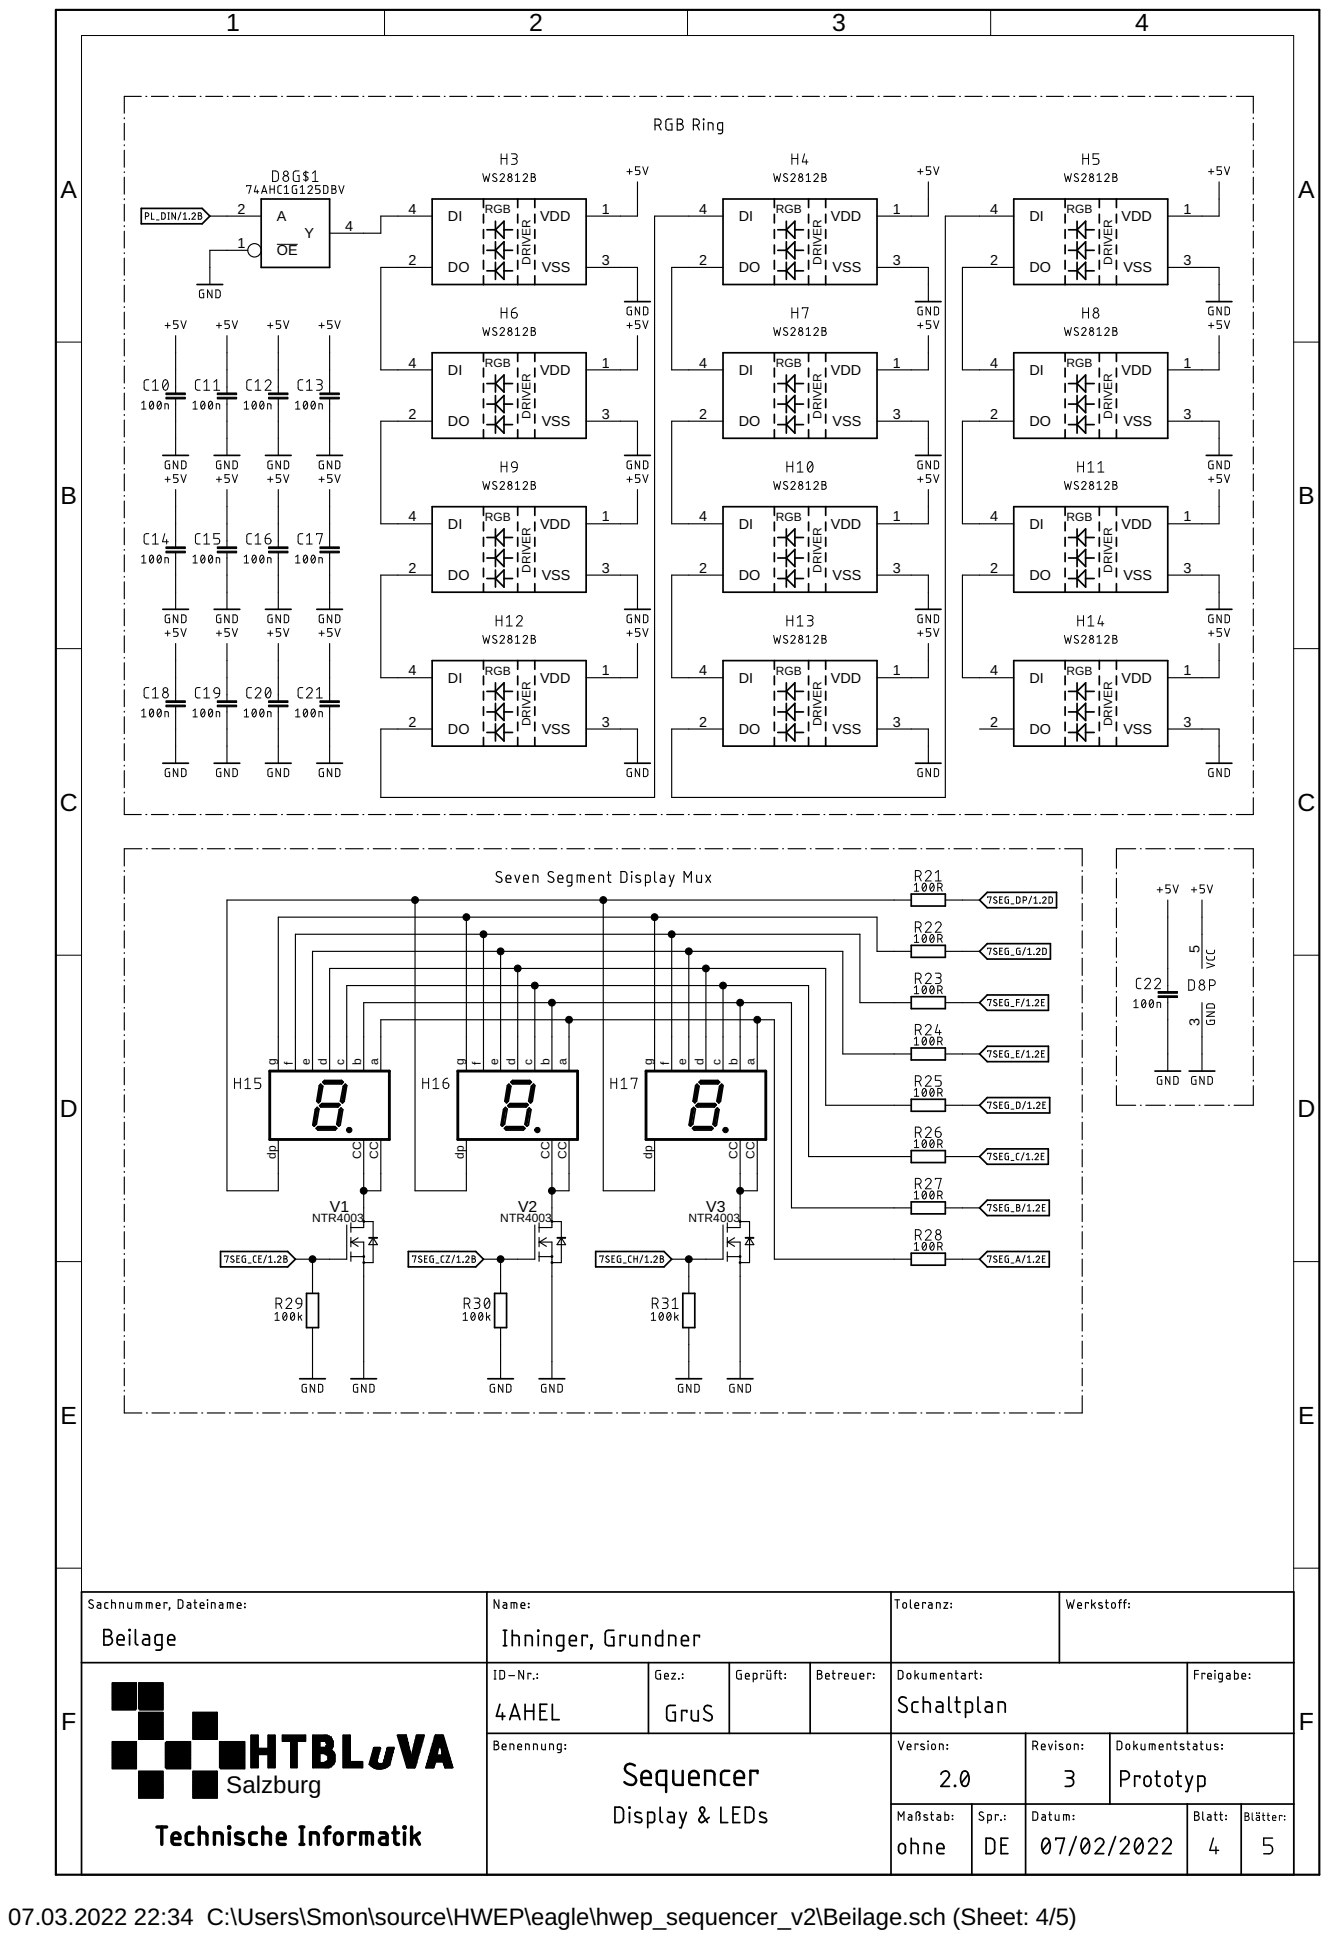
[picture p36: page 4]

07.03.2022 22:34 C:\Users\Smon\source\HWEP\eagle\hwep_sequencer_v2\Beilage.sch (Sheet: 4/5)

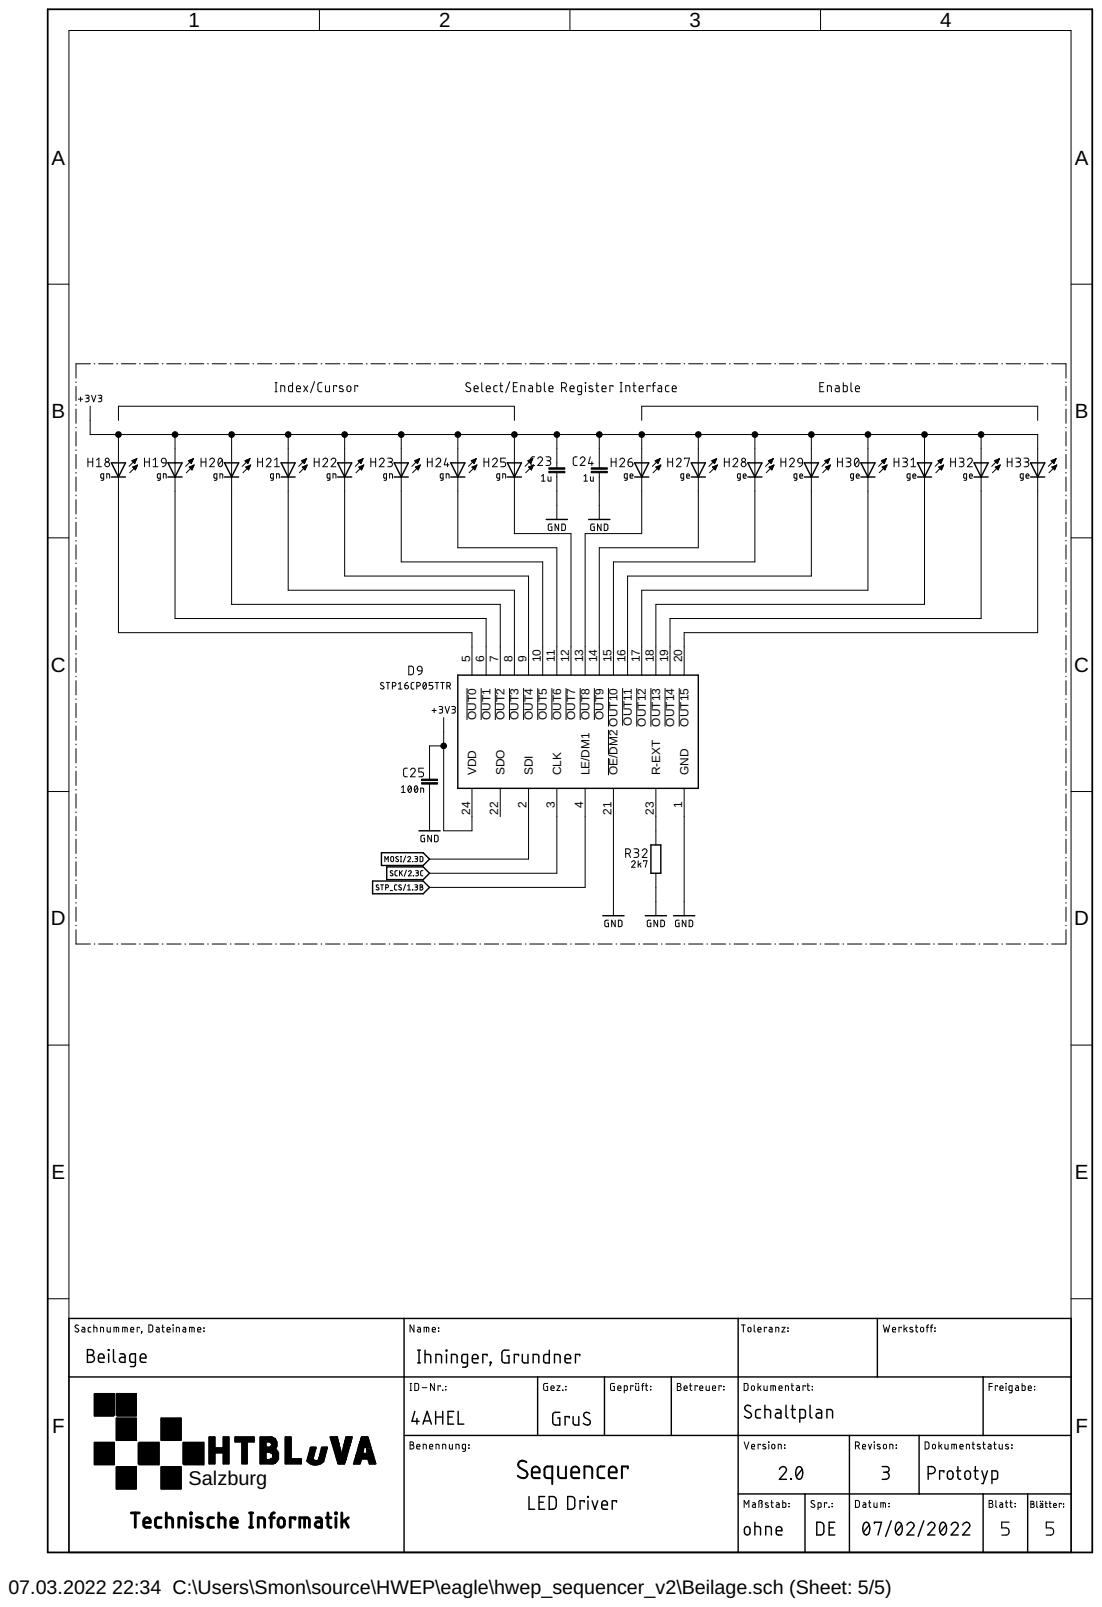
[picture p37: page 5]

07.03.2022 22:34 C:\Users\Smon\source\HWEP\eagle\hwep_sequencer_v2\Beilage.sch (Sheet: 5/5)

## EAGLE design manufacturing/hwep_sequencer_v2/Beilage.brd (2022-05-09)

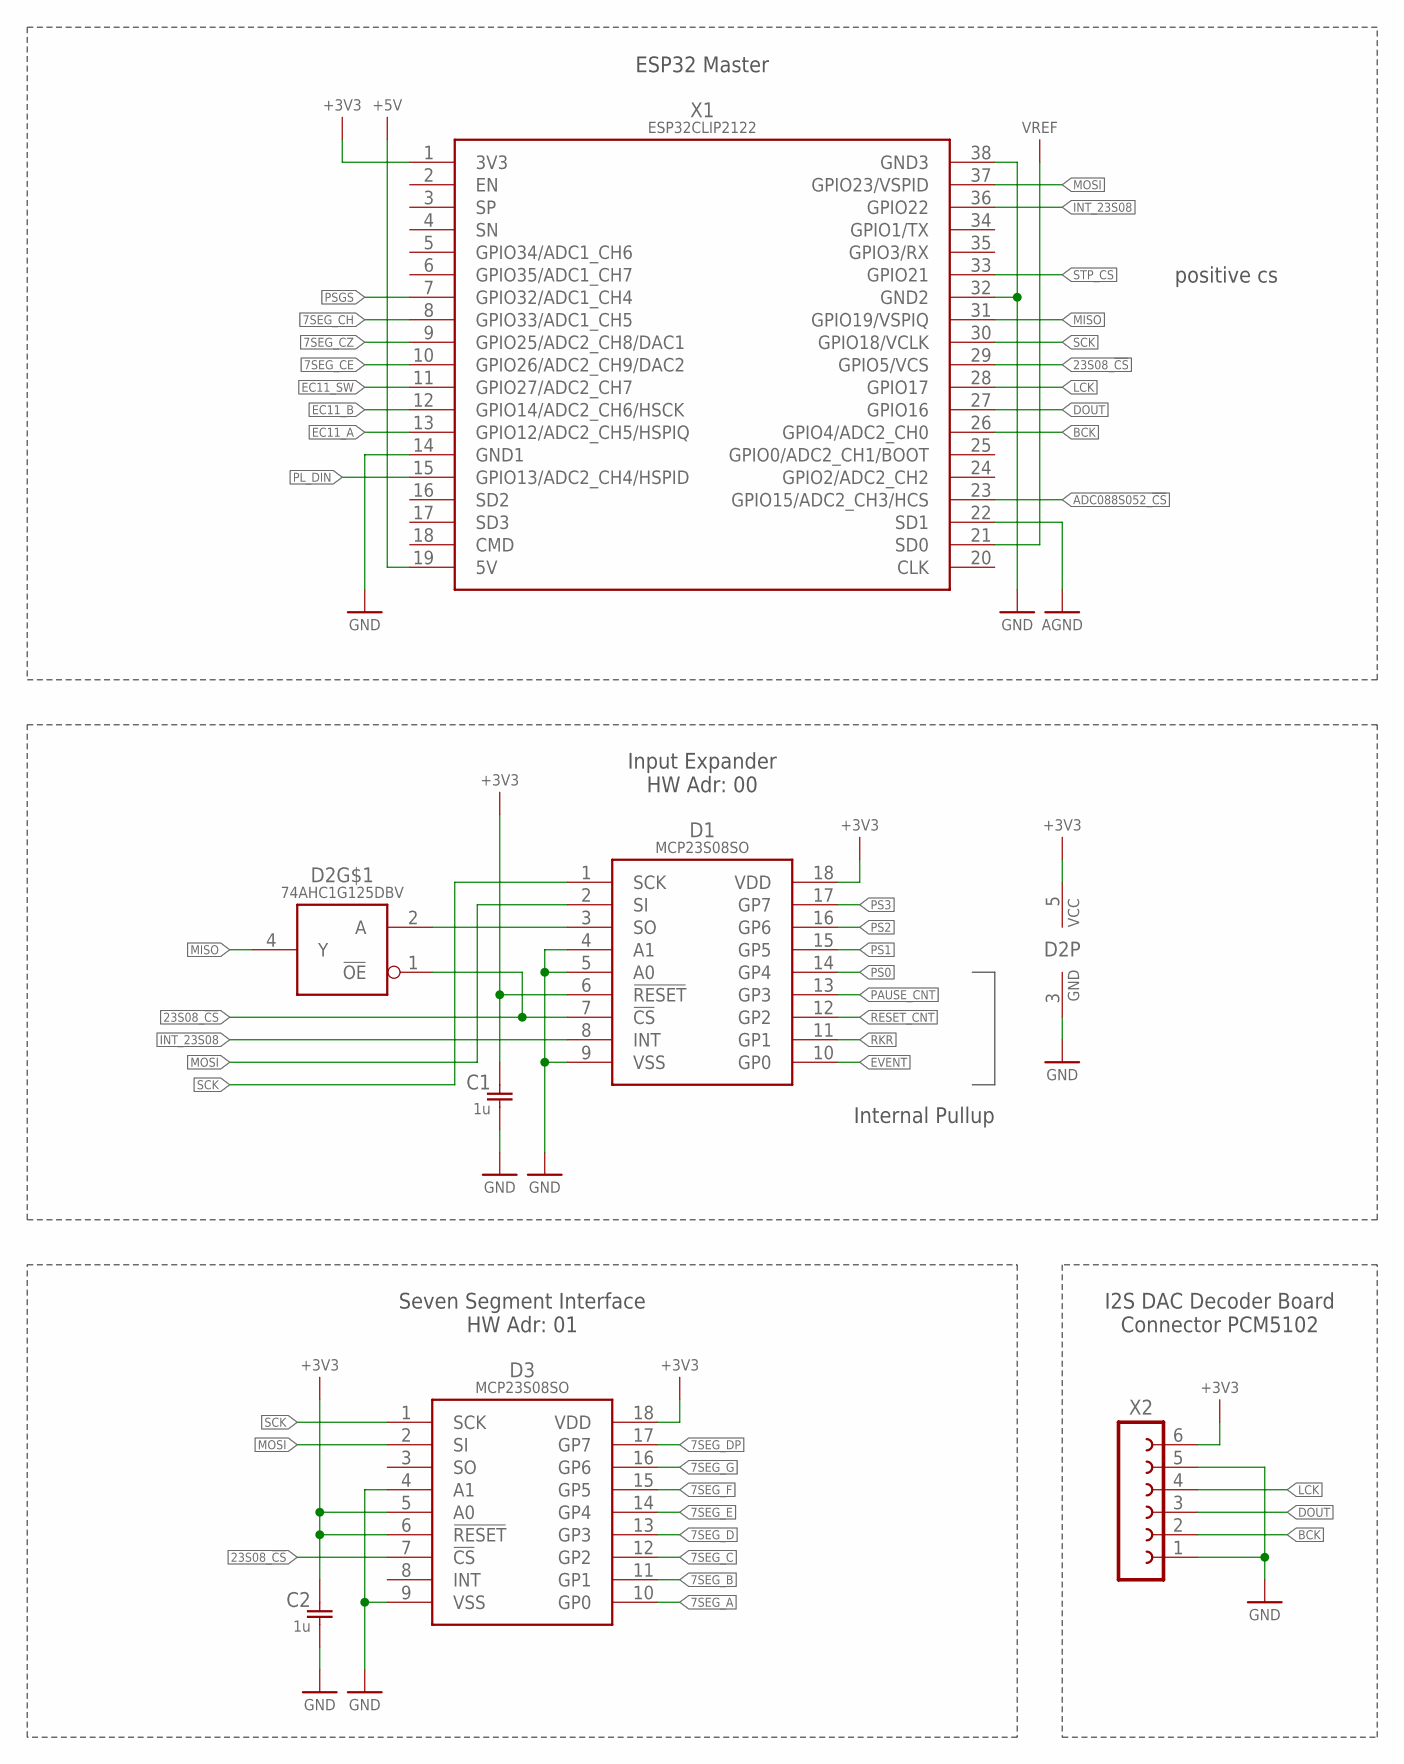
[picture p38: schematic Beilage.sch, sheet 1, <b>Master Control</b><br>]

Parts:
C1, C2: 1u; C0805
D1, D3: MCP23S08SO; SO18W
D2: 74AHC1G125DBV; SOT23-5
X1: ESP32CLIP2122; ESP32-DEVKIT-C-CLIP
X2: FE06-1; FE06

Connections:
7SEG_A: D3.10 (GP0); also elsewhere on the board
7SEG_B: D3.11 (GP1); also elsewhere on the board
7SEG_C: D3.12 (GP2); also elsewhere on the board
7SEG_CE: X1.10 (GPIO26/ADC2_CH9/DAC2); also elsewhere on the board
7SEG_CH: X1.8 (GPIO33/ADC1_CH5); also elsewhere on the board
7SEG_CZ: X1.9 (GPIO25/ADC2_CH8/DAC1); also elsewhere on the board
7SEG_D: D3.13 (GP3); also elsewhere on the board
7SEG_DP: D3.17 (GP7); also elsewhere on the board
7SEG_E: D3.14 (GP4); also elsewhere on the board
7SEG_F: D3.15 (GP5); also elsewhere on the board
7SEG_G: D3.16 (GP6); also elsewhere on the board
23S08_!CS: D1.7 (!CS), D2.1 (!OE), D3.7 (!CS), X1.29 (GPIO5/VCS)
+3V3: C1.1, C2.1, D1.6 (!RESET), D1.18 (VDD), D2.5 (VCC), D3.5 (A0), D3.6 (!RESET), D3.18 (VDD), X1.1 (3V3), X2.6; also elsewhere on the board
+5V: X1.19 (5V); also elsewhere on the board
ADC088S052_!CS: X1.23 (GPIO15/ADC2_CH3/HCS); also elsewhere on the board
AGND: X1.22 (SD1); also elsewhere on the board
BCK: X1.26 (GPIO4/ADC2_CH0), X2.2
DOUT: X1.27 (GPIO16), X2.3
EC11_A: X1.13 (GPIO12/ADC2_CH5/HSPIQ); also elsewhere on the board
EC11_B: X1.12 (GPIO14/ADC2_CH6/HSCK); also elsewhere on the board
EC11_SW: X1.11 (GPIO27/ADC2_CH7); also elsewhere on the board
EVENT: D1.10 (GP0); also elsewhere on the board
GND: C1.2, C2.2, D1.4 (A1), D1.5 (A0), D1.9 (VSS), D2.3 (GND), D3.4 (A1), D3.9 (VSS), X1.14 (GND1), X1.32 (GND2), X1.38 (GND3), X2.1, X2.5; also elsewhere on the board
INT_23S08: D1.8 (INT), X1.36 (GPIO22)
LCK: X1.28 (GPIO17), X2.4
MISO: D2.4 (Y), X1.31 (GPIO19/VSPIQ); also elsewhere on the board
MOSI: D1.2 (SI), D3.2 (SI), X1.37 (GPIO23/VSPID); also elsewhere on the board
unnamed: D1.3 (SO), D2.2 (A)
PAUSE_CNT: D1.13 (GP3); also elsewhere on the board
PL_DIN: X1.15 (GPIO13/ADC2_CH4/HSPID); also elsewhere on the board
PS0: D1.14 (GP4); also elsewhere on the board
PS1: D1.15 (GP5); also elsewhere on the board
PS2: D1.16 (GP6); also elsewhere on the board
PS3: D1.17 (GP7); also elsewhere on the board
PSGS: X1.7 (GPIO32/ADC1_CH4); also elsewhere on the board
RESET_CNT: D1.12 (GP2); also elsewhere on the board
RKR: D1.11 (GP1); also elsewhere on the board
SCK: D1.1 (SCK), D3.1 (SCK), X1.30 (GPIO18/VCLK); also elsewhere on the board
STP_CS: X1.33 (GPIO21); also elsewhere on the board
VREF: X1.21 (SD0); also elsewhere on the board

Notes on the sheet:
Seven Segment Interface HW Adr: 01
ESP32 Master
I2S DAC Decoder Board Connector PCM5102
Input Expander HW Adr: 00
Internal Pullup
positive cs

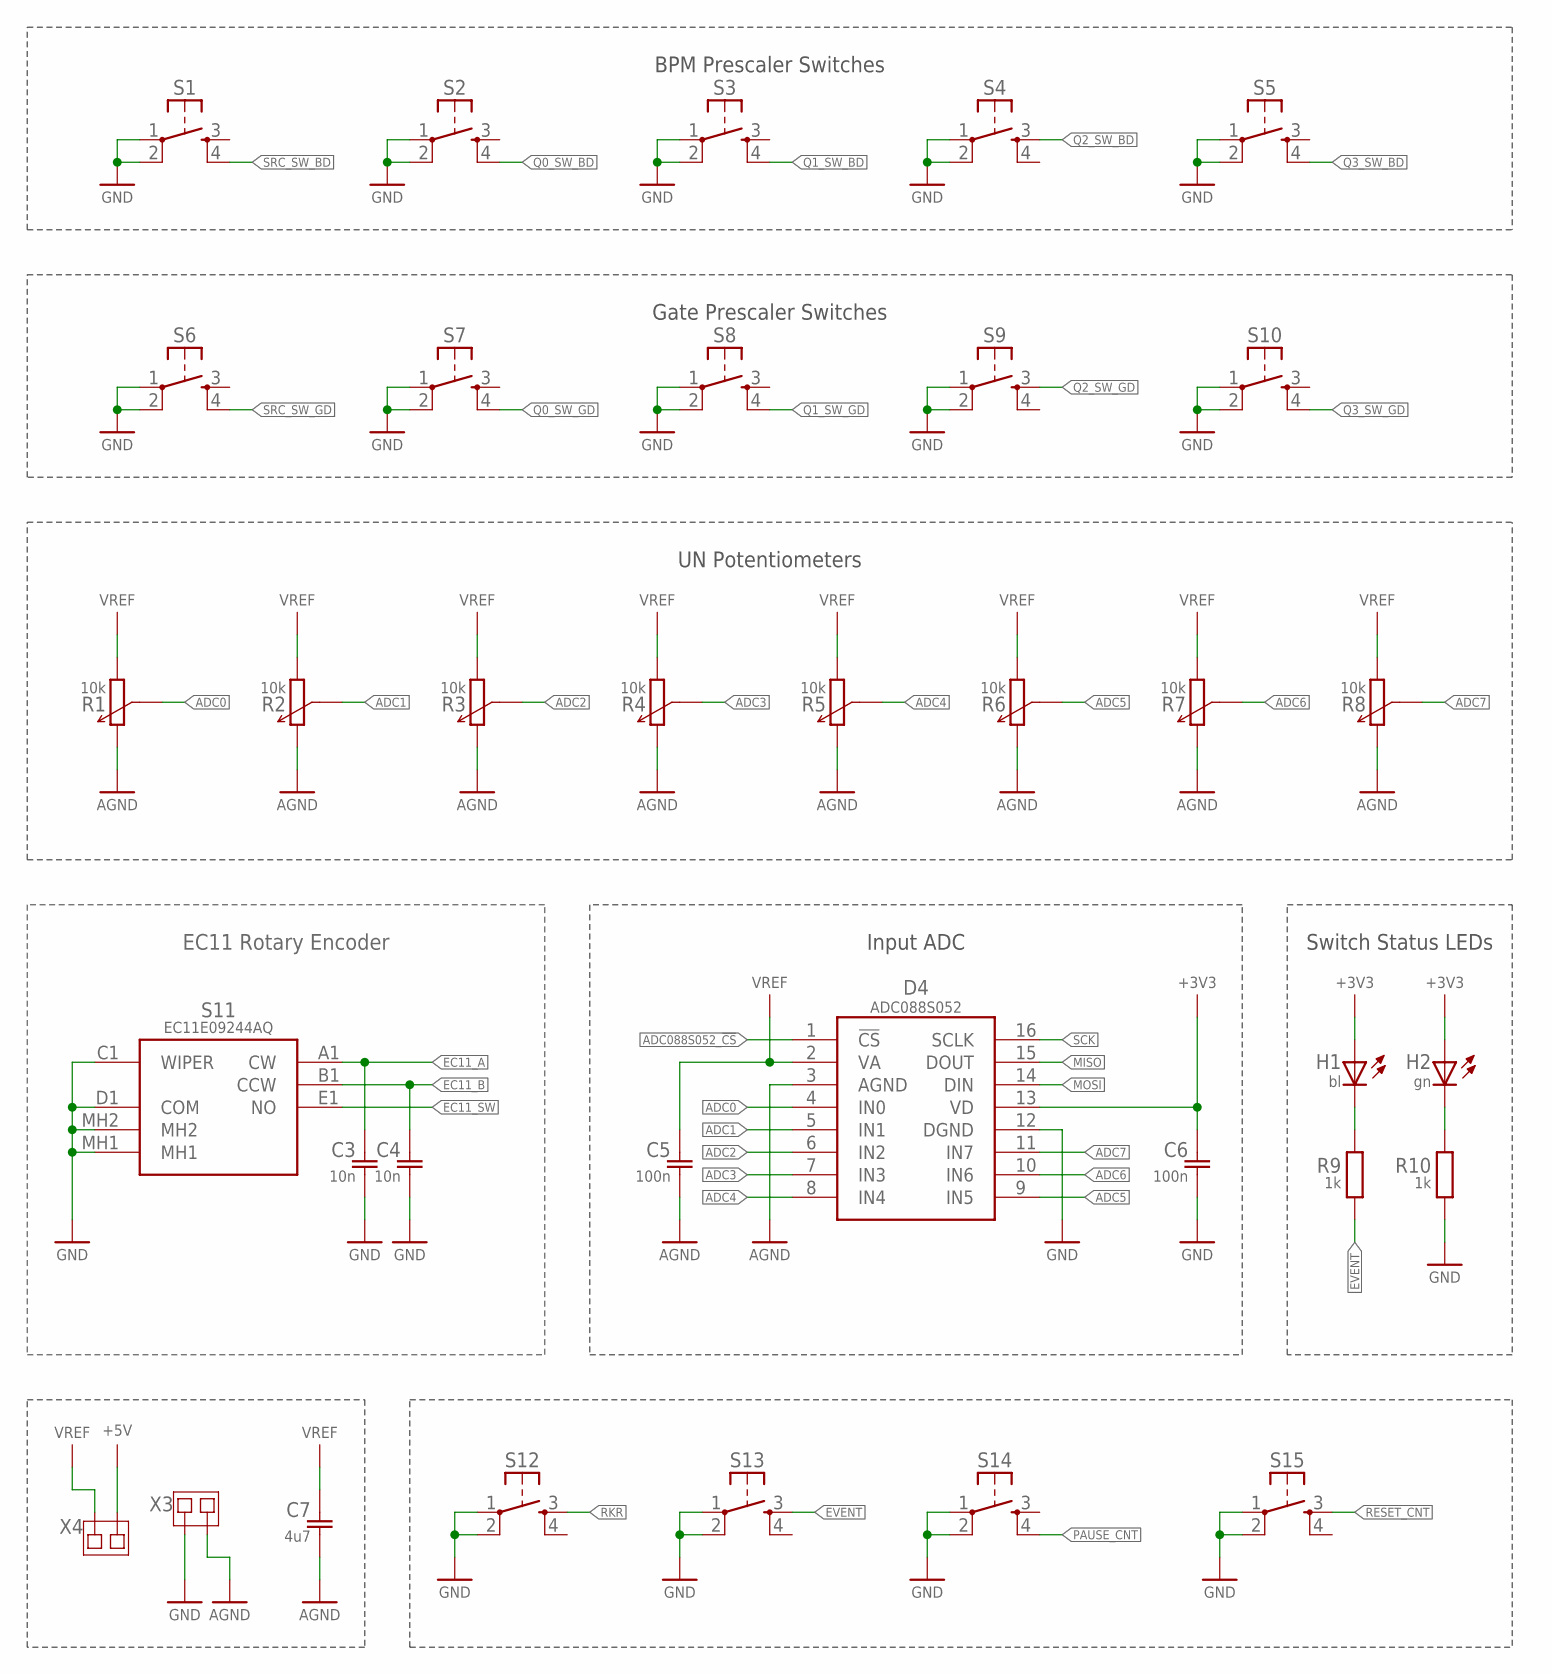
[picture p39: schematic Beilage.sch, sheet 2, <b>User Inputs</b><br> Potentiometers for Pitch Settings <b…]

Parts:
C3, C4: 10n; C0805
C5, C6: 100n; C0805
C7: 4u7; C0805
D4: ADC088S052; TSSOP16
H1: bl; CHIPLED_1206
H2: gn; CHIPLED_1206
R1, R2, R3, R4, R5, R6, R7, R8: 10k; P160LB
R9, R10: 1k; R0805
S1, S2, S3, S4, S5, S6, S7, S8, S9, S10, S12, S13, S14, S15: TASTE10XX; B3F-10XX
S11: EC11E09244AQ; EC11
X3, X4: JUMPSMD1FACH-1; MYLIB_SJ

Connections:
+3V3: C6.1, D4.13 (VD), H1.A, H2.A; also elsewhere on the board
+5V: X4.1; also elsewhere on the board
ADC0: D4.4 (IN0), R1.2 (3)
ADC1: D4.5 (IN1), R2.2 (3)
ADC2: D4.6 (IN2), R3.2 (3)
ADC3: D4.7 (IN3), R4.2 (3)
ADC4: D4.8 (IN4), R5.2 (3)
ADC5: D4.9 (IN5), R6.2 (3)
ADC6: D4.10 (IN6), R7.2 (3)
ADC7: D4.11 (IN7), R8.2 (3)
ADC088S052_!CS: D4.1 (!CS); also elsewhere on the board
AGND: C5.2, C7.2, D4.3 (AGND), R1.3 (2), R2.3 (2), R3.3 (2), R4.3 (2), R5.3 (2), R6.3 (2), R7.3 (2), R8.3 (2), X3.2; also elsewhere on the board
EC11_A: C3.1, S11.A1 (CW); also elsewhere on the board
EC11_B: C4.1, S11.B1 (CCW); also elsewhere on the board
EC11_SW: S11.E1 (NO); also elsewhere on the board
EVENT: R9.1, S13.3 (S); also elsewhere on the board
GND: C3.2, C4.2, C6.2, D4.12 (DGND), R10.1, S1.1, S1.2 (P1), S2.1, S2.2 (P1), S3.1, S3.2 (P1), S4.1, S4.2 (P1), S5.1, S5.2 (P1), S6.1, S6.2 (P1), S7.1, S7.2 (P1), S8.1, S8.2 (P1), S9.1, S9.2 (P1), S10.1, S10.2 (P1), S11.C1 (WIPER), S11.D1 (COM), S11.MH1, S11.MH2, S12.1, S12.2 (P1), S13.1, S13.2 (P1), S14.1, S14.2 (P1), S15.1, S15.2 (P1), X3.1; also elsewhere on the board
MISO: D4.15 (DOUT); also elsewhere on the board
MOSI: D4.14 (DIN); also elsewhere on the board
unnamed: H2.C, R10.2
unnamed: H1.C, R9.2
PAUSE_CNT: S14.4 (S1); also elsewhere on the board
Q0_SW_BD: S2.4 (S1); also elsewhere on the board
Q0_SW_GD: S7.4 (S1); also elsewhere on the board
Q1_SW_BD: S3.4 (S1); also elsewhere on the board
Q1_SW_GD: S8.4 (S1); also elsewhere on the board
Q2_SW_BD: S4.3 (S); also elsewhere on the board
Q2_SW_GD: S9.3 (S); also elsewhere on the board
Q3_SW_BD: S5.4 (S1); also elsewhere on the board
Q3_SW_GD: S10.4 (S1); also elsewhere on the board
RESET_CNT: S15.3 (S); also elsewhere on the board
RKR: S12.3 (S); also elsewhere on the board
SCK: D4.16 (SCLK); also elsewhere on the board
SRC_SW_BD: S1.4 (S1); also elsewhere on the board
SRC_SW_GD: S6.4 (S1); also elsewhere on the board
VREF: C5.1, C7.1, D4.2 (VA), R1.1, R2.1, R3.1, R4.1, R5.1, R6.1, R7.1, R8.1, X4.2; also elsewhere on the board

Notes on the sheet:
UN Potentiometers
EC11 Rotary Encoder
BPM Prescaler Switches
Gate Prescaler Switches
Switch Status LEDs
Input ADC

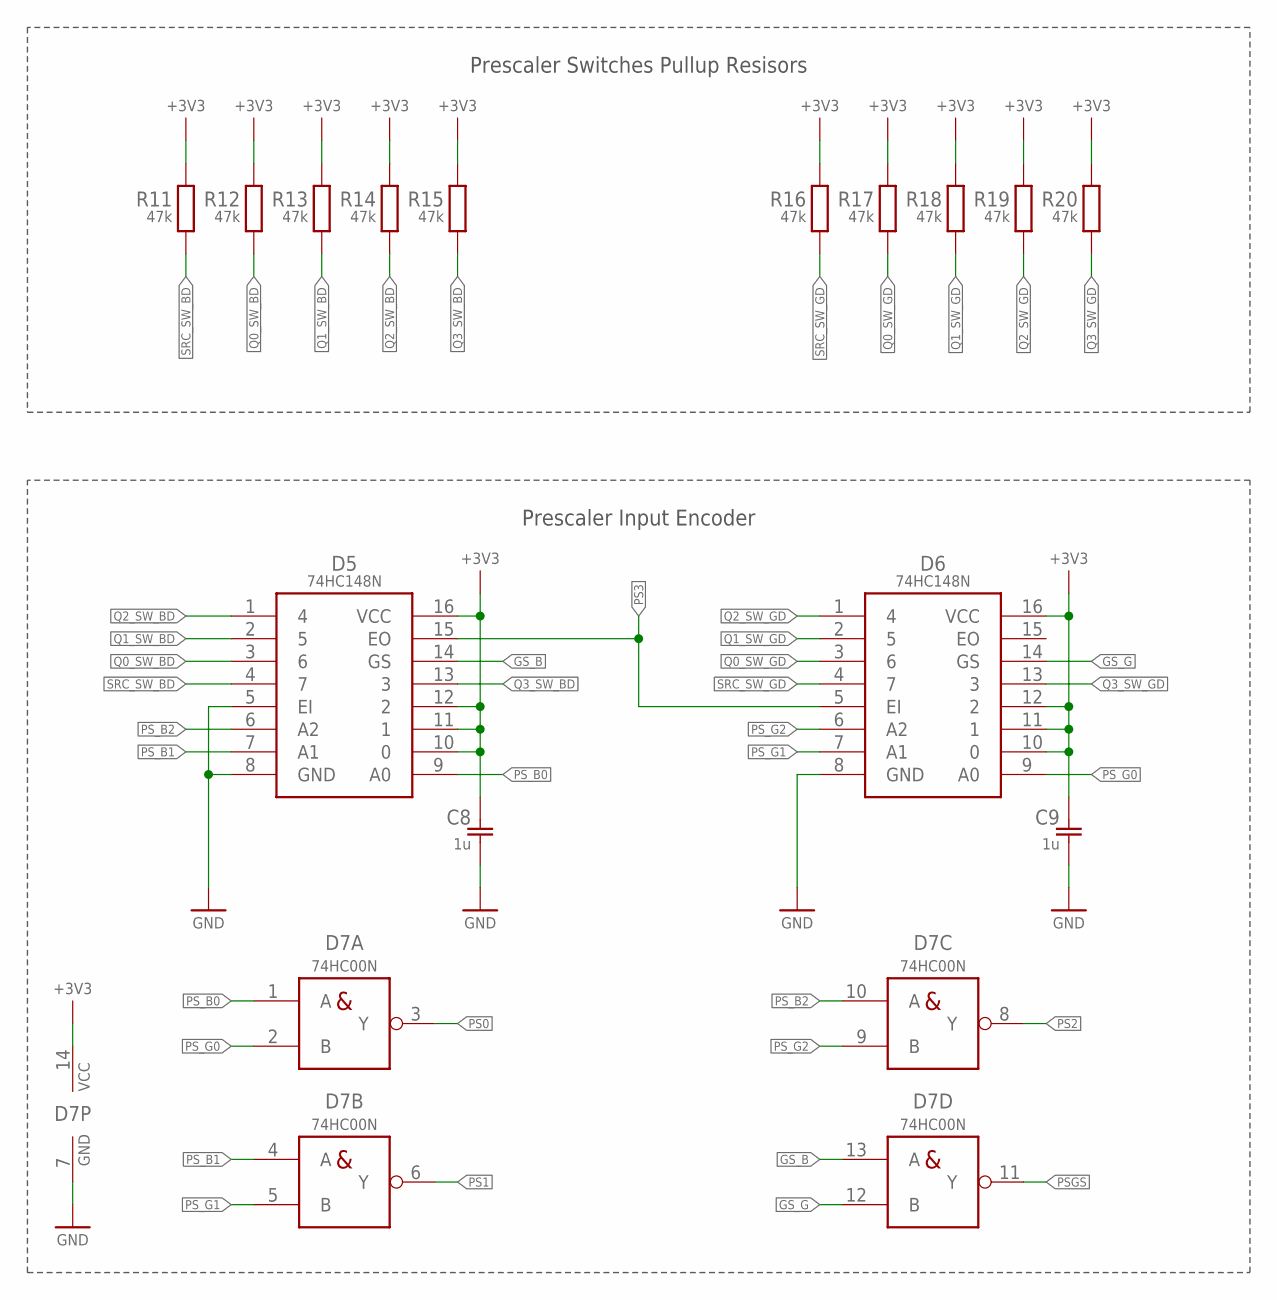
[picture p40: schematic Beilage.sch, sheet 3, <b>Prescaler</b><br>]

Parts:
C8, C9: 1u; C0805
D5, D6: 74HC148N; DIP16
D7: 74HC00N; DIP14
R11, R12, R13, R14, R15, R16, R17, R18, R19, R20: 47k; R0805

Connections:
+3V3: C8.1, C9.1, D5.10 (0), D5.11 (1), D5.12 (2), D5.16 (VCC), D6.10 (0), D6.11 (1), D6.12 (2), D6.16 (VCC), D7.14 (VCC), R11.2, R12.2, R13.2, R14.2, R15.2, R16.2, R17.2, R18.2, R19.2, R20.2; also elsewhere on the board
GND: C8.2, C9.2, D5.5 (EI), D5.8 (GND), D6.8 (GND), D7.7 (GND); also elsewhere on the board
GS_B: D5.14 (GS), D7.13 (A)
GS_G: D6.14 (GS), D7.12 (B)
PS0: D7.3 (Y); also elsewhere on the board
PS1: D7.6 (Y); also elsewhere on the board
PS2: D7.8 (Y); also elsewhere on the board
PS3: D5.15 (EO), D6.5 (EI); also elsewhere on the board
PSGS: D7.11 (Y); also elsewhere on the board
PS_B0: D5.9 (A0), D7.1 (A)
PS_B1: D5.7 (A1), D7.4 (A)
PS_B2: D5.6 (A2), D7.10 (A)
PS_G0: D6.9 (A0), D7.2 (B)
PS_G1: D6.7 (A1), D7.5 (B)
PS_G2: D6.6 (A2), D7.9 (B)
Q0_SW_BD: D5.3 (6), R12.1; also elsewhere on the board
Q0_SW_GD: D6.3 (6), R17.1; also elsewhere on the board
Q1_SW_BD: D5.2 (5), R13.1; also elsewhere on the board
Q1_SW_GD: D6.2 (5), R18.1; also elsewhere on the board
Q2_SW_BD: D5.1 (4), R14.1; also elsewhere on the board
Q2_SW_GD: D6.1 (4), R19.1; also elsewhere on the board
Q3_SW_BD: D5.13 (3), R15.1; also elsewhere on the board
Q3_SW_GD: D6.13 (3), R20.1; also elsewhere on the board
SRC_SW_BD: D5.4 (7), R11.1; also elsewhere on the board
SRC_SW_GD: D6.4 (7), R16.1; also elsewhere on the board

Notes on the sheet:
Prescaler Input Encoder
Prescaler Switches Pullup Resisors

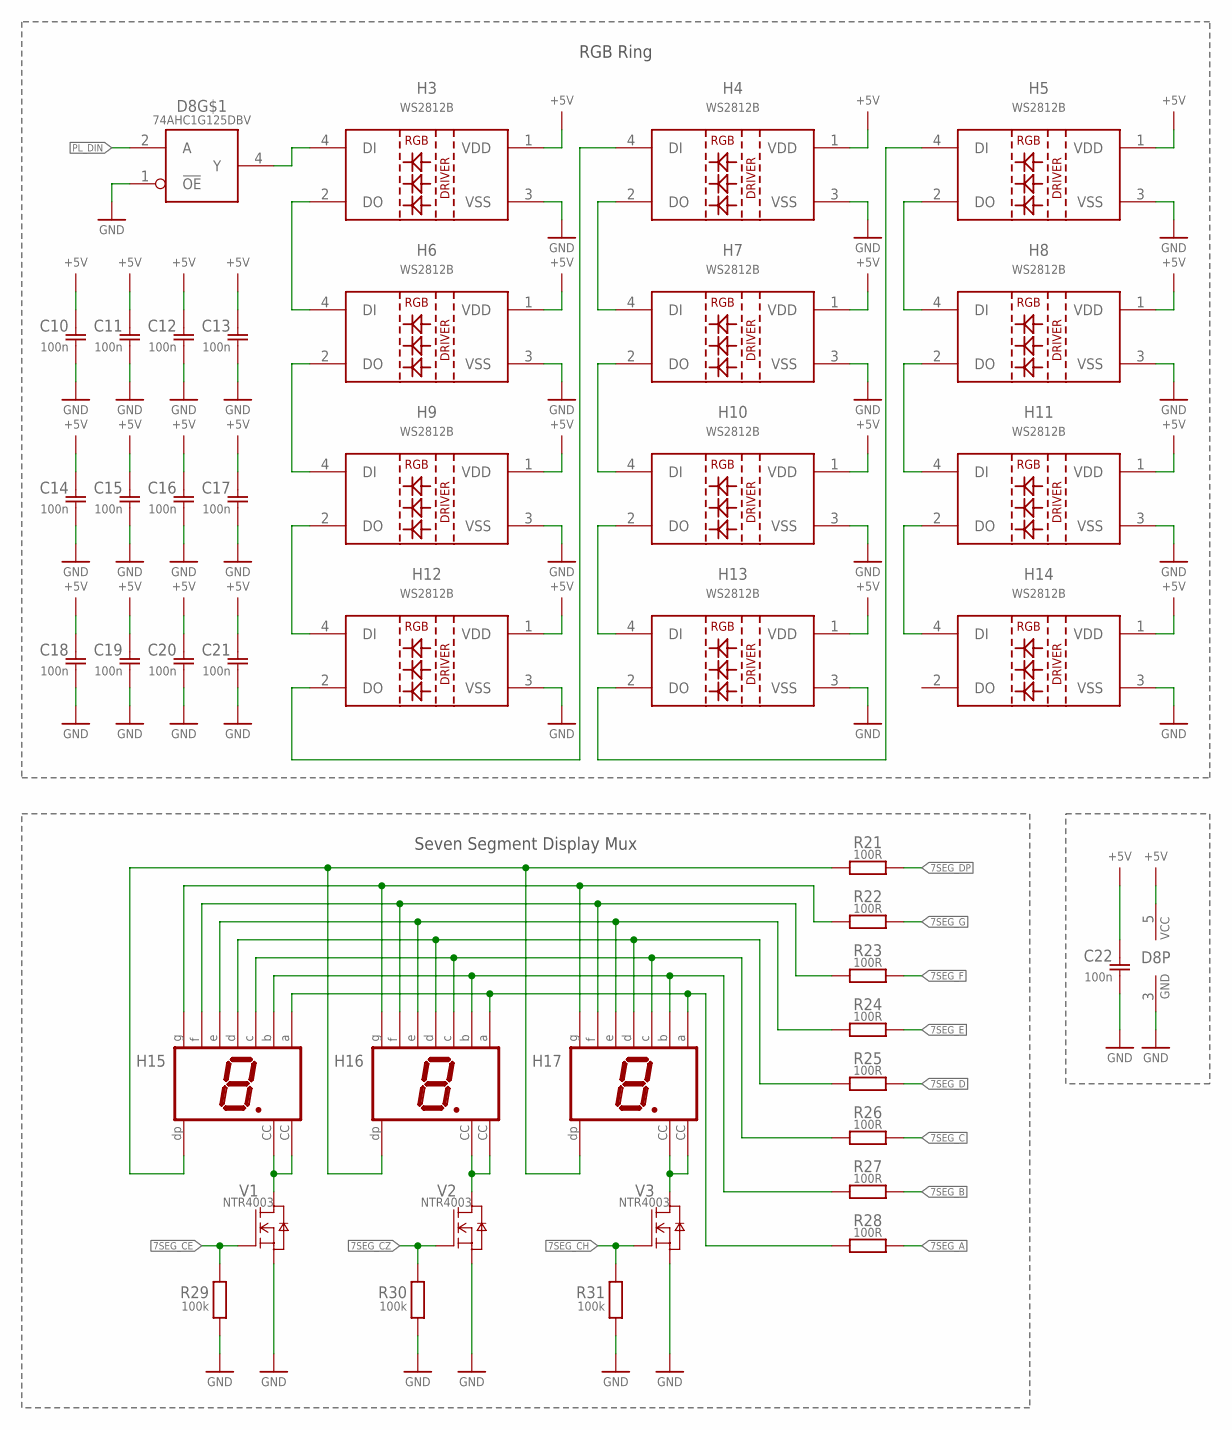
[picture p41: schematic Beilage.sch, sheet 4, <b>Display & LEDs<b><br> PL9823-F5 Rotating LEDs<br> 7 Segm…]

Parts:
C10, C11, C12, C13, C14, C15, C16, C17, C18, C19, C20, C21, C22: 100n; C0805
D8: 74AHC1G125DBV; SOT23-5
H3, H4, H5, H6, H7, H8, H9, H10, H11, H12, H13, H14: WS2812B
H15, H16, H17: HD-H103; HDSP-E
R21, R22, R23, R24, R25, R26, R27, R28: 100R; R0805
R29, R30, R31: 100k; R0805
V1, V2, V3: NTR4003; SOT23

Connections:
7SEG_A: R28.2; also elsewhere on the board
7SEG_B: R27.2; also elsewhere on the board
7SEG_C: R26.2; also elsewhere on the board
7SEG_CE: R29.2, V1.1 (G); also elsewhere on the board
7SEG_CH: R31.2, V3.1 (G); also elsewhere on the board
7SEG_CZ: R30.2, V2.1 (G); also elsewhere on the board
7SEG_D: R25.2; also elsewhere on the board
7SEG_DP: R21.2; also elsewhere on the board
7SEG_E: R24.2; also elsewhere on the board
7SEG_F: R23.2; also elsewhere on the board
7SEG_G: R22.2; also elsewhere on the board
+5V: C10.1, C11.1, C12.1, C13.1, C14.1, C15.1, C16.1, C17.1, C18.1, C19.1, C20.1, C21.1, C22.1, D8.5 (VCC), H3.1 (VDD), H4.1 (VDD), H5.1 (VDD), H6.1 (VDD), H7.1 (VDD), H8.1 (VDD), H9.1 (VDD), H10.1 (VDD), H11.1 (VDD), H12.1 (VDD), H13.1 (VDD), H14.1 (VDD); also elsewhere on the board
GND: C10.2, C11.2, C12.2, C13.2, C14.2, C15.2, C16.2, C17.2, C18.2, C19.2, C20.2, C21.2, C22.2, D8.1 (!OE), D8.3 (GND), H3.3 (VSS), H4.3 (VSS), H5.3 (VSS), H6.3 (VSS), H7.3 (VSS), H8.3 (VSS), H9.3 (VSS), H10.3 (VSS), H11.3 (VSS), H12.3 (VSS), H13.3 (VSS), H14.3 (VSS), R29.1, R30.1, R31.1, V1.2 (S), V2.2 (S), V3.2 (S); also elsewhere on the board
unnamed: D8.4 (Y), H3.4 (DI)
unnamed: H6.2 (DO), H9.4 (DI)
unnamed: H3.2 (DO), H6.4 (DI)
unnamed: H8.2 (DO), H11.4 (DI)
unnamed: H15.DP, H16.DP, H17.DP, R21.1
unnamed: H15.G, H16.G, H17.G, R22.1
unnamed: H15.F, H16.F, H17.F, R23.1
unnamed: H15.A, H16.A, H17.A, R28.1
unnamed: H15.B, H16.B, H17.B, R27.1
unnamed: H15.CC1 (CC), H15.CC2 (CC), V1.3 (D)
unnamed: H15.D, H16.D, H17.D, R25.1
unnamed: H10.2 (DO), H13.4 (DI)
unnamed: H5.4 (DI), H13.2 (DO)
unnamed: H5.2 (DO), H8.4 (DI)
unnamed: H16.CC1 (CC), H16.CC2 (CC), V2.3 (D)
unnamed: H17.CC1 (CC), H17.CC2 (CC), V3.3 (D)
unnamed: H7.2 (DO), H10.4 (DI)
unnamed: H9.2 (DO), H12.4 (DI)
unnamed: H11.2 (DO), H14.4 (DI)
unnamed: H4.4 (DI), H12.2 (DO)
unnamed: H4.2 (DO), H7.4 (DI)
unnamed: H15.C, H16.C, H17.C, R26.1
unnamed: H15.E, H16.E, H17.E, R24.1
PL_DIN: D8.2 (A); also elsewhere on the board

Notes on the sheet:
Seven Segment Display Mux
RGB Ring

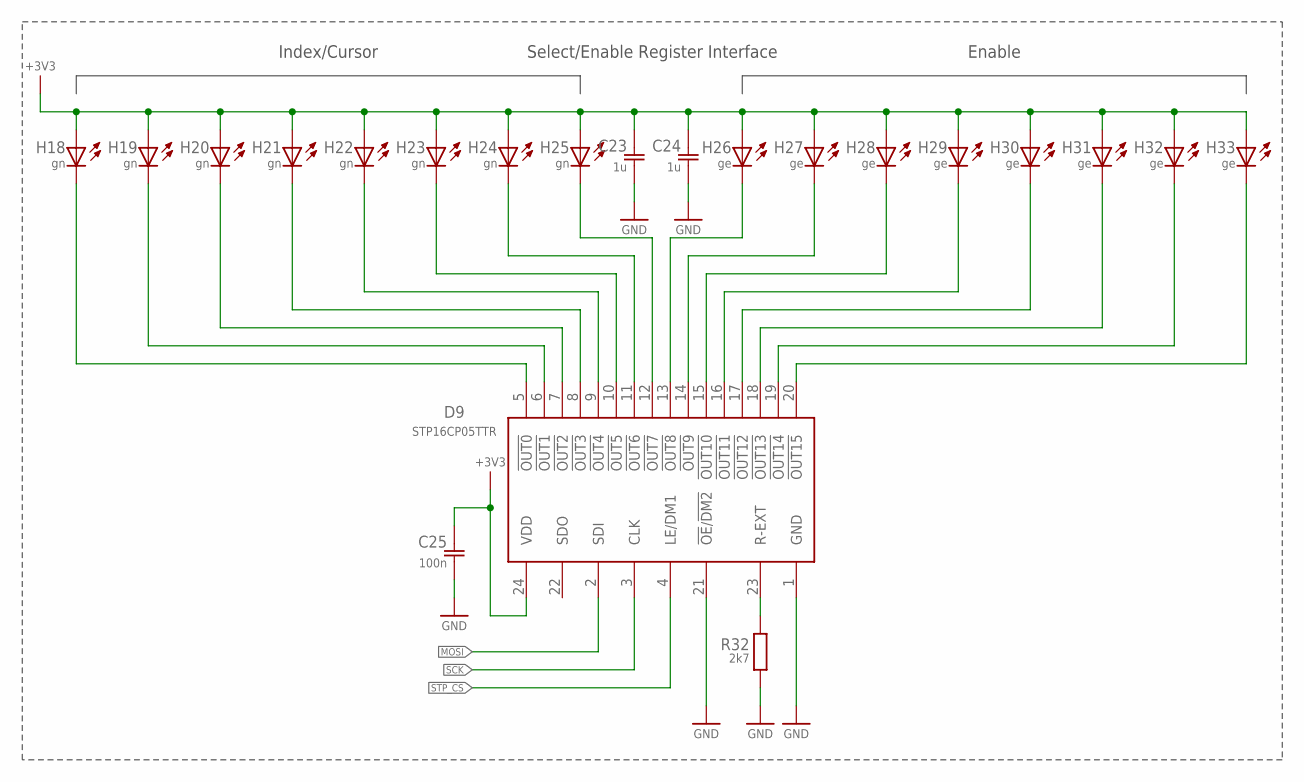
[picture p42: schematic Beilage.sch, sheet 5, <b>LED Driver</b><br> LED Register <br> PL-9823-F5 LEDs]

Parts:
C23, C24: 1u; C0805
C25: 100n; C0805
D9: STP16CP05TTR; TSSOP24
H18, H19, H20, H21, H22, H23, H24, H25: gn; LED5MM
H26, H27, H28, H29, H30, H31, H32, H33: ge; LED5MM
R32: 2k7; R0805

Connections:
+3V3: C23.1, C24.1, C25.1, D9.24 (VDD), H18.A, H19.A, H20.A, H21.A, H22.A, H23.A, H24.A, H25.A, H26.A, H27.A, H28.A, H29.A, H30.A, H31.A, H32.A, H33.A; also elsewhere on the board
GND: C23.2, C24.2, C25.2, D9.1 (GND), D9.21 (!OE!/!DM2), R32.1; also elsewhere on the board
MOSI: D9.2 (SDI); also elsewhere on the board
unnamed: D9.5 (!OUT0), H18.K (C)
unnamed: D9.6 (!OUT1), H19.K (C)
unnamed: D9.7 (!OUT2), H20.K (C)
unnamed: D9.8 (!OUT3), H21.K (C)
unnamed: D9.9 (!OUT4), H22.K (C)
unnamed: D9.10 (!OUT5), H23.K (C)
unnamed: D9.11 (!OUT6), H24.K (C)
unnamed: D9.12 (!OUT7), H25.K (C)
unnamed: D9.13 (!OUT8), H26.K (C)
unnamed: D9.14 (!OUT9), H27.K (C)
unnamed: D9.15 (!OUT10), H28.K (C)
unnamed: D9.16 (!OUT11), H29.K (C)
unnamed: D9.17 (!OUT12), H30.K (C)
unnamed: D9.18 (!OUT13), H31.K (C)
unnamed: D9.19 (!OUT14), H32.K (C)
unnamed: D9.20 (!OUT15), H33.K (C)
unnamed: D9.23 (R-EXT), R32.2
SCK: D9.3 (CLK); also elsewhere on the board
STP_CS: D9.4 (LE/DM1); also elsewhere on the board

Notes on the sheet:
Index/Cursor
Enable
Select/Enable Register Interface

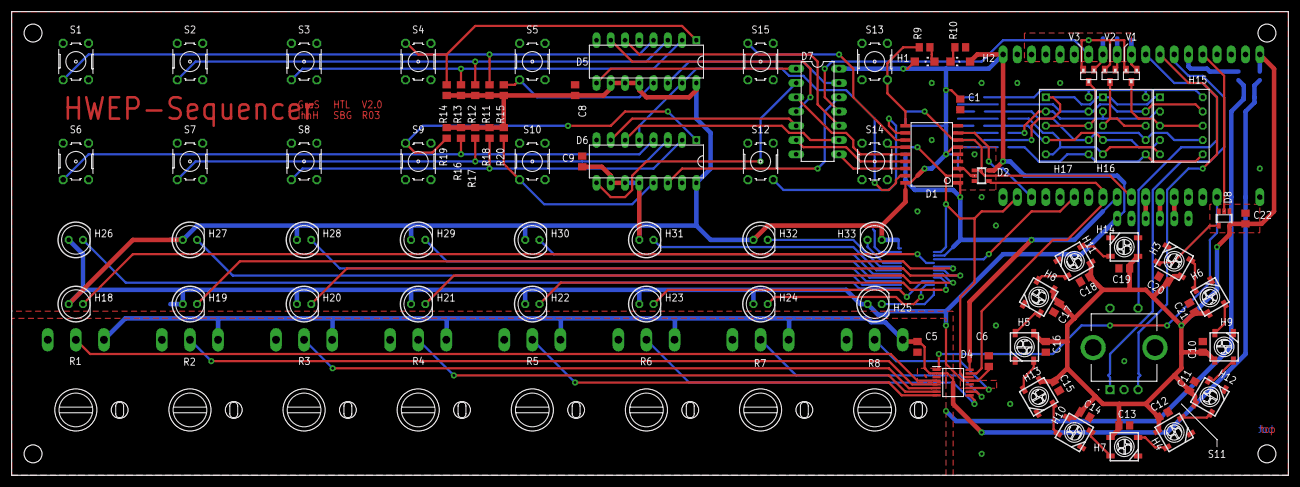
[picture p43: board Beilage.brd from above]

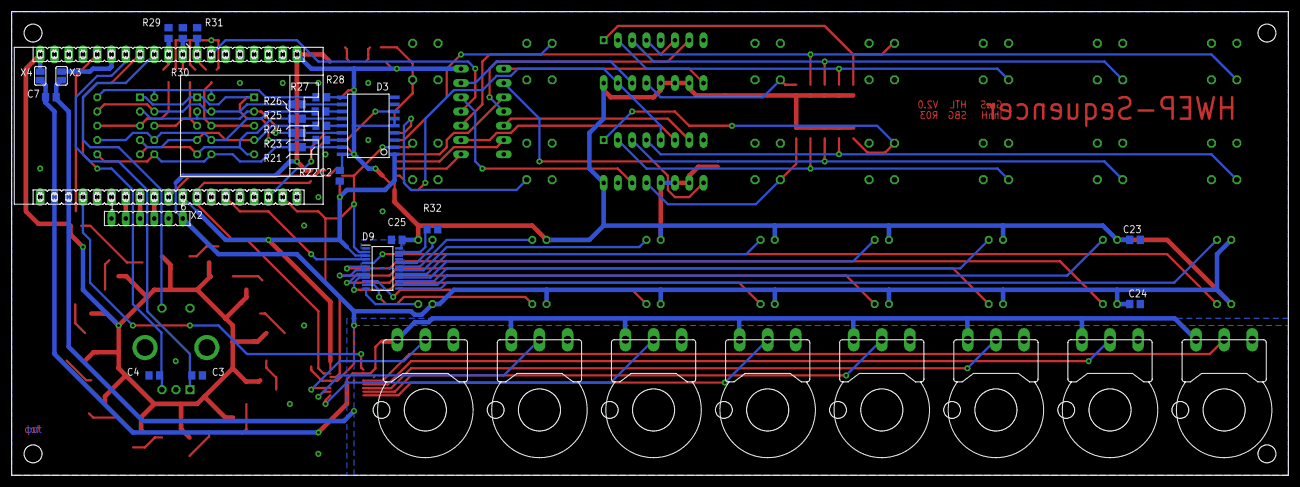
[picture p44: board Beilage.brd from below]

Board: 2 copper layers, 227.3 x 82.5 mm, 123 parts (25 on the bottom side), 108 nets.

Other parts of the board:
FABRICATION: FABRIACTION
MEASURE: MEASURE

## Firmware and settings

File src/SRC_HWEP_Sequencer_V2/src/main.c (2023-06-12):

/**
 * @file 	main.c
 * @author	@h-ihninger
 * @author 	@s-grundner
 * @brief 	main file of the HWEP Sequencer Project
 * @version 2
 * @date 2022-05-05
 *
 * @copyright Copyright (c) 2022
 *
 */

#include "sequencer.h"
#include "esp_log.h"

#define LED_BRIGHTNESS 1.0

#define CHASE_SPEED_MS (100)

static const char *TAG = "sequencer_main";

static void fsm(void *args)
{
	sequencer_handle_t sqc_handle = (sequencer_handle_t)args;
	int32_t ec_changed[ADC0880S052_CHANNEL_MAX];
	int32_t shift_ec_changed[ADC0880S052_CHANNEL_MAX];

	for (int i = 0; i < ADC0880S052_CHANNEL_MAX; i++)
	{
		ec_changed[i] = encoder_read(sqc_handle->encoder_handle) + 1;
		shift_ec_changed[i] = encoder_read(sqc_handle->encoder_handle) + 1;
	}

	for (;;)
	{
		// store encoder value in sqc struct to save time
		if (sqc_handle->btn_shift)
		{
			sqc_handle->shift_encoder_positions[sqc_handle->cur_appmode] += encoder_read(sqc_handle->encoder_handle);
		}
		else
		{
			sqc_handle->encoder_positions[sqc_handle->cur_appmode] += encoder_read(sqc_handle->encoder_handle);
		}
		encoder_write(sqc_handle->encoder_handle, 0);

		// Main Statemachine
		switch (sqc_handle->cur_appmode)
		{
		case APP_MODE_BPM:
			// reset at n index takes effect
			sqc_handle->reset_at_n = (((sqc_handle->encoder_positions[APP_MODE_ENR] >> 1) % 8) + 1);

			// check if encoder data has changed
			if (ec_changed[sqc_handle->cur_appmode] != sqc_handle->encoder_positions[sqc_handle->cur_appmode])
			{
				update_bpm(sqc_handle);
				ec_changed[sqc_handle->cur_appmode] = sqc_handle->encoder_positions[sqc_handle->cur_appmode];
			}

			// check if shift-encoder-data has changed
			if (shift_ec_changed[sqc_handle->cur_appmode] != sqc_handle->shift_encoder_positions[sqc_handle->cur_appmode])
			{
				// update wavetable
				sqc_handle->osc.wt_index = abs(sqc_handle->shift_encoder_positions[sqc_handle->cur_appmode] / 2) % WAVEFORM_TYPE_COUNT;
				sqc_handle->osc.wavetable = get_wavetable(sqc_handle->osc.wt_index);

				// reset changed state
				shift_ec_changed[sqc_handle->cur_appmode] = sqc_handle->shift_encoder_positions[sqc_handle->cur_appmode];
			}

			break;
		case APP_MODE_KEY:
			// reset at n index takes effect
			sqc_handle->reset_at_n = (((sqc_handle->encoder_positions[APP_MODE_ENR] >> 1) % 8) + 1);

			// check if encoder data has changed
			if (ec_changed[sqc_handle->cur_appmode] != sqc_handle->encoder_positions[sqc_handle->cur_appmode])
			{
				sqc_handle->cur_key = abs(sqc_handle->encoder_positions[sqc_handle->cur_appmode] >> 1) % 12;
				// reset changed state
				ec_changed[sqc_handle->cur_appmode] = sqc_handle->encoder_positions[sqc_handle->cur_appmode];
			}

			// check if shift-encoder-data has changed
			if (shift_ec_changed[sqc_handle->cur_appmode] != sqc_handle->shift_encoder_positions[sqc_handle->cur_appmode])
			{
				sqc_handle->cur_modal = abs(sqc_handle->shift_encoder_positions[sqc_handle->cur_appmode] >> 1) % 4;
				// reset changed state
				shift_ec_changed[sqc_handle->cur_appmode] = sqc_handle->shift_encoder_positions[sqc_handle->cur_appmode];
			}

			break;
		case APP_MODE_ENR:
			break;
		case APP_MODE_TSP:
			// reset at n index takes effect
			sqc_handle->reset_at_n = (((sqc_handle->encoder_positions[APP_MODE_ENR] >> 1) % 8) + 1);

			// check if encoder data has changed
			if (ec_changed[sqc_handle->cur_appmode] != sqc_handle->encoder_positions[sqc_handle->cur_appmode])
			{
				sqc_handle->osc.transpose = (sqc_handle->encoder_positions[sqc_handle->cur_appmode] - 1) / 2;
				if (sqc_handle->osc.transpose >= 12)
				{
					sqc_handle->osc.transpose -= 12;
					sqc_handle->osc.oct_offset += 1;
				}
				else if (sqc_handle->osc.transpose <= -12)
				{
					sqc_handle->osc.transpose += 12;
					sqc_handle->osc.oct_offset -= 1;
				}
				// reset changed state
				ec_changed[sqc_handle->cur_appmode] = sqc_handle->encoder_positions[sqc_handle->cur_appmode];
			}

			// check if shift-encoder-data has changed
			if (shift_ec_changed[sqc_handle->cur_appmode] != sqc_handle->shift_encoder_positions[sqc_handle->cur_appmode])
			{
				sqc_handle->osc.oct_offset = abs(sqc_handle->shift_encoder_positions[sqc_handle->cur_appmode] >> 1) % 8; // 8 max octave
				// reset changed state
				shift_ec_changed[sqc_handle->cur_appmode] = sqc_handle->shift_encoder_positions[sqc_handle->cur_appmode];
			}

			break;
		default:
			break;
		}

		// manage audio
		manage_audio(sqc_handle);

		// manage display
		if (sqc_handle->sseg_handle->sseg_refreshable)
		{
			if (sqc_handle->shkey_flag)
			{
				sseg_write(sqc_handle->sseg_handle, get_key_name(get_key_num(sqc_handle->osc.pitch)));
			}
			else
			{
				char str[] = "   ";
				switch (sqc_handle->cur_appmode)
				{
				case APP_MODE_BPM:
					// write display data
					sseg_write(sqc_handle->sseg_handle, sqc_handle->btn_shift ? get_wt_name(sqc_handle->osc.wt_index) : itoa(sqc_handle->cur_bpm, str, 10));
					break;
				case APP_MODE_KEY:
					// write display data
					sseg_write(sqc_handle->sseg_handle, sqc_handle->btn_shift ? get_modal_name(sqc_handle->cur_modal) : get_key_name(sqc_handle->cur_key));
					break;
				case APP_MODE_ENR:
					break;
				case APP_MODE_TSP:
					// write display data
					sseg_write(sqc_handle->sseg_handle, sqc_handle->btn_shift ? itoa(sqc_handle->osc.oct_offset, str, 10) : itoa(sqc_handle->osc.transpose, str, 10));
					break;
				default:
					break;
				}
			}
		}
		// manage_display(sqc_handle);

		// manage_ws2812(sqc_handle);

		vTaskDelay(10 / portTICK_PERIOD_MS);
	}
}

static void led_task(void *args)
{
	uint32_t red = 0;
	uint32_t green = 0;
	uint32_t blue = 0;
	uint16_t hue = 0;
	uint16_t start_rgb = 0;

	rmt_config_t config = RMT_DEFAULT_CONFIG_TX(13, RMT_TX_CHANNEL);
	// set counter clock to 40MHz
	config.clk_div = 2;

	ESP_ERROR_CHECK(rmt_config(&config));
	ESP_ERROR_CHECK(rmt_driver_install(config.channel, 0, 0));

	// install ws2812 driver
	led_strip_config_t strip_config = LED_STRIP_DEFAULT_CONFIG(12, (led_strip_dev_t)config.channel);
	led_strip_t *strip = led_strip_new_rmt_ws2812(&strip_config);
	if (!strip)
	{
		ESP_LOGE(TAG, "install WS2812 driver failed");
	}
	// Clear LED strip (turn off all LEDs)
	ESP_ERROR_CHECK(strip->clear(strip, 100));
	// Show simple rainbow chasing pattern
	ESP_LOGI(TAG, "LED Rainbow Chase Start");

	while (true)
	{
		for (int i = 0; i < 3; i++)
		{
			for (int j = i; j < 12; j += 3)
			{
				// Build RGB values
				hue = j * 360 / 12 + start_rgb;
				led_strip_hsv2rgb(hue, 100, 100, &red, &green, &blue);
				// Write RGB values to strip driver
				ESP_ERROR_CHECK(strip->set_pixel(strip, j, red * LED_BRIGHTNESS, green * LED_BRIGHTNESS, blue * LED_BRIGHTNESS));
			}
			// Flush RGB values to LEDs
			ESP_ERROR_CHECK(strip->refresh(strip, 100));
			vTaskDelay(pdMS_TO_TICKS(CHASE_SPEED_MS));
		}
		start_rgb += 60;
	}
}

void app_main(void)
{
	sequencer_handle_t sqc_handle;
	ESP_ERROR_CHECK(sequencer_init(&sqc_handle));

	xTaskCreate(led_task, "ws_led_task", 2048, NULL, 10, NULL);
	xTaskCreatePinnedToCore(&fsm, "main_fsm", 2048, sqc_handle, 10, NULL, 0);
	while (1)
		vTaskDelay(10 / portTICK_PERIOD_MS);
}

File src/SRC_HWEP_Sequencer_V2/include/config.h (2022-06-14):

#pragma once

#ifndef CONFIG_H_
#define CONFIG_H_

#include "esp_system.h"

// ------------------------------------------------------------
// Pinout
// ------------------------------------------------------------

#define PIN_UNUSED (-1)
#define MCP23S08_INTR (GPIO_NUM_22)
#define WS2812_DATA (GPIO_NUM_13)
#define WS2812_STRIP_LEN (12)
#define RMT_TX_CHANNEL RMT_CHANNEL_0
#define PS_FLAG (GPIO_NUM_32)

#define IN_PS_HW_ADR (0b00)
#define S_SEG_HW_ADR (0b01)

#define SW (GPIO_NUM_27)
#define A (GPIO_NUM_12)
#define B (GPIO_NUM_14)

#define VSPI (VSPI_HOST)
#define VSPIQ (GPIO_NUM_19)		// MISO for SPI3 (VSPI) host
#define VSPID (GPIO_NUM_23)		// MOSI for SPI3 (VSPI) host
#define VSPI_MISO (GPIO_NUM_19) // MISO for SPI3 (VSPI) host
#define VSPI_MOSI (GPIO_NUM_23) // MOSI for SPI3 (VSPI) host
#define VCS0 (GPIO_NUM_5)		// CS0 for SPI3 (VSPI) host
#define VSCK (GPIO_NUM_18)		// SCK for SPI3 (VSPI) hosts

#define CS_MCP23S08 (GPIO_NUM_5)
#define CS_ADC0880S052 (GPIO_NUM_15)
#define CS_STP16CP05 (GPIO_NUM_21)

#define SEG_CNT 3
#define SEG_CH_E (GPIO_NUM_26)
#define SEG_CH_Z (GPIO_NUM_25)
#define SEG_CH_H (GPIO_NUM_33)
#define S_SEG_CHANNEL_MASK (1ULL << SEG_CH_H) | (1ULL << SEG_CH_Z) | (1ULL << SEG_CH_E)

#define DEF_BPM 120
#define BPM_TO_US(a) (0x3938700 / (a))

// ------------------------------------------------------------
// define Application Modes
// ------------------------------------------------------------

/* Every Mode Starts with an Indicator on the Hex Display until it is updated by the modes tasks */

#define START_BPM 120
#define MAX_APP_MODES 4

typedef enum
{
	APP_MODE_BPM = 0, // Set Beats per Minute
					  // HEX:		shows BPM
					  // Rotary:	changes BPM on Rotation
					  // Event:		+SHIFT Rotary: CHange Waveform
					  //			+SHIFT HEX: Shows Selected Waveform
					  // Index/Cur:	Index (Yellow LEDS)
					  // Blue LEDS: Shows on off State

	APP_MODE_KEY = 1, // Key Settings
					  // HEX:		shows Current Key
					  // Rotary:	Change Key (Shift Key Register)
					  // Event:		+SHIFT Rotary: Change Mode
					  // Index/Cur:	Index (Yellow LEDS)
					  // Blue LEDS: Shows on off State

	APP_MODE_ENR = 2, // Enable and Reset at Index
					  // HEX:		-
					  // Rotary:	Moves Cursor
					  // Event:		Toggles On/Off State at Cursor -> Lights EN Led
					  // Index/Cur.:Cursor (Yellow LEDS)
					  // Blue LEDS: Shows on off State

	APP_MODE_TSP = 3, // Transpose in Key
					  // HEX:		Transposition amount
					  // Rotary:	Transpose +/- 1 ST
					  // Event:		+SHIFT Rotary: Transpose Octave (+/- 12 ST)
					  // Index/Cur.:Index (Yellow LEDS)
					  // Blue LEDS: Shows on off State
} app_mode_t;

// ------------------------------------------------------------
// Ideas
// ------------------------------------------------------------

// Triplets

#endif // #ifndef CONFIG_H_

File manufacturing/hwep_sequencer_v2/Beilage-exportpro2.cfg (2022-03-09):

layout_bot = 1
layout_top = 1
parts_top = 1
parts_bot = 1
drills = 1
measure = 1
drilltable = 1
enable_export_png = 1
construction = 1
bom = 0
mirror_bot = 1
crop_all = 1
bom_xls = 1
bom_csv = 0
bom_dbase3 = 0
bom_shorten_names = 1
bom_display_package_type = 1
no_measures = 1
auto_project = 1
output_folder = ./docu/
layout_inner_layer = 1
parts_display_names = 1
parts_display_values = 1
pricing = 0
idf_export = 0
pcbimage_top = 1
pcbimage_bottom = 1
image_resolution = 1
pcbimage_color = 0
pcbimage_silkscreen_color = 0
pcbimage_plating = 1
silkscreen_tnames = 1
silkscreen_tvalues = 1
silkscreen_tdocu = 1
silkscreen_bnames = 1
silkscreen_bvalues = 1
silkscreen_bdocu = 1
bom_farnell = 0
bom_quantity = 0.000000
renumber = 0
output_date_folder = 1
schematic_export = 1
schematic_bw = 1
schematic_color = 0
schematic_format = 0
silkscreen_tplace = 1
silkscreen_bplace = 1
board_layer.Nr.0 = 1
board_layer.Nr.1 = 0
board_layer.Nr.2 = 0
board_layer.Nr.3 = 0
board_layer.Nr.4 = 0
board_layer.Nr.5 = 0
board_layer.Nr.6 = 0
board_layer.Nr.7 = 0
board_layer.Nr.8 = 0
board_layer.Nr.9 = 0
board_layer.Nr.10 = 0
board_layer.Nr.11 = 0
board_layer.Nr.12 = 0
board_layer.Nr.13 = 0
board_layer.Nr.14 = 0
board_layer.Nr.15 = 1
ULP_REVISION_FORMAT_REVISION = 7
gerber_export = 0
gerber_copper = 1
gerber_stc = 1
gerber_sts = 1
gerber_plc = 1
gerber_pls = 1
gerber_crc = 1
gerber_crs = 1
gerber_drd = 1
board_thickness = 1.570000
board_type = 0
board_copper_thickness = 35.000000
eagle_export = 0
gerber_otl = 1
reference = 0
gerber_ref = 1
parts_top_docu = 1
parts_bot_docu = 1
ec_export = 0
gerber_format = 1
pnp_export = 0
pnp_top = 1
pnp_bot = 1
pnp_flip = 0
pnp_auto_offset = 0
pnp_offset_x = 0.000000
pnp_offset_y = 0.000000
fabrication = 0
stackup = 0
gerber_fab = 1
enable_export_pdf = 0
pdf_keep_frame = 1
pdf_merge = 1
enable_export_image = 0
copper_layer_thickness.Nr.0 = 35.000000
copper_layer_thickness.Nr.1 = 0.000000
copper_layer_thickness.Nr.2 = 0.000000
copper_layer_thickness.Nr.3 = 0.000000
copper_layer_thickness.Nr.4 = 0.000000
copper_layer_thickness.Nr.5 = 0.000000
copper_layer_thickness.Nr.6 = 0.000000
copper_layer_thickness.Nr.7 = 0.000000
copper_layer_thickness.Nr.8 = 0.000000
copper_layer_thickness.Nr.9 = 0.000000
copper_layer_thickness.Nr.10 = 0.000000
copper_layer_thickness.Nr.11 = 0.000000
copper_layer_thickness.Nr.12 = 0.000000
copper_layer_thickness.Nr.13 = 0.000000
copper_layer_thickness.Nr.14 = 0.000000
copper_layer_thickness.Nr.15 = 35.000000
bom_to_pdf = 1
board_format = 0
bom_offsetX = 0.150000
bom_offsetY = 0.150000
bom_width = 179.600000
board_info = 0
board_title  = Sequencer
board_subtitle  = Version 2.0

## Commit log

2022-01-13 init dev branch
    [UtoF.xlsx]
2022-01-14 Board: Bedruck Formatiert
    Board Optimiert und Layer:
    Names
    Values
    Formatiert
    [Beilage.brd, Beilage.sch]
2022-01-14 cleanup old versions
    [ADSR.sch, Beilage.brd, Beilage.sch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]
2022-01-14 Prototype Board
    [Beilage.brd]
2022-01-15 Board Prototyp Fertiggestellt
    Fehlende Entkoppel-Kondensatoren eingefügt
    Bestückungsdruck überarbeitet und Formatiert
    [Beilage.brd, Beilage.sch]
2022-01-16 RGB Ring now in SMD
    SMD RGB LEDS WS2812 used because of availability
    PSU Buck Converter 12v to 5v still to be added to the schematic
    [Beilage.brd, Beilage.sch]
2022-01-17 Optimized Wires
    [Beilage.brd]
2022-01-20 Major Prescaler Update
    Optimized Prescaler:
    Now Fully Software side.
    Inputs are priority encoded and put on MCP23S08 free input pins.
    Issues:
    Analog Reference Voltage Needed?
    Dedicated PSU / Voltage converter
    [Beilage.brd, Beilage.sch]
2022-01-20 fixed traces
    [Beilage.brd, Beilage.sch]
2022-01-21 Documentation Update
    Added STL
    cleaned up docs
    [Beilage.brd, Beilage.sch, Projektplan_GruS_IhnH.xlsx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]
2022-01-24 Schematic Pictures
    and word file for Printing
2022-01-24 sim and docu
    Updated BOM
    Prescaler Logisim Simulation
    [STL_HWEP_Prot.xlsx, STL_HWEP_Sequencer_V2.xlsx]
2022-01-25 Prescaler Sim
    Optimised Schematic
    Changed unavailable ICs
    Issue: Interrupt on Input MCP23S08 and Prescaler Strobe
    [Beilage.brd, Beilage.sch]
2022-01-25 upd BOM
    [STL_HWEP_Sequencer_V2.xlsx]
2022-01-25 Updated BOM
    [Beilage.brd, STL_HWEP_Sequencer_V2.xlsx]
2022-01-31 deleted mül
    [STL_HWEP_Sequencer_V2.xlsx]
2022-02-06 i2s testing & KUB
    [Beilage.brd, Beilage.sch]
2022-02-07 final commit before testing
    [Beilage.sch]
2022-02-07 removed key register visualisation
    bloat feature
    [Beilage.brd, Beilage.sch, STL_HWEP_Prot.xlsx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]
2022-02-07 upd doku
    [Beilage-exportpro2.cfg, Beilage.brd, Beilage.sch]
2022-02-09 removed unnecessary features
    [Beilage.brd, Beilage.sch]
2022-02-13 spi test
    [Beilage.brd, Beilage.sch, STL_HWEP_Sequencer_V2.xlsx]
2022-02-14 mcp23s08 implemented
    [Beilage.brd, Beilage.sch, STL_HWEP_Sequencer_V2.xlsx]
2022-02-15 reroute brd complete
    [Beilage.brd, Beilage.sch]
2022-02-15 optimized brd and 3d model
    [Beilage.brd]
2022-02-17 updated outline
    [Beilage-exportpro2.cfg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]
2022-02-18 mcp interrupt upd
2022-02-22 Finalised Board
    [Beilage-exportpro2.cfg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]
2022-02-25 ec11 rotary encoder tested
    relative rot angle/position and switch callback
    [Beilage.brd, Beilage.sch]
2022-02-25 finale gerber generation
    [Beilage-exportpro2.cfg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]
2022-02-25 removed trash references and deprecated files
    [Beilage xx.sch]
2022-02-28 Update adc
2022-03-01 encoder + adc upd
2022-03-02 updated ec11 package
    [Beilage.brd, Beilage.sch]
2022-03-06 i2s variable frequency
    + board finalized and ordered
    + i2s variable frequency tested
    [Beilage-exportpro2.cfg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]
2022-03-06 audio
    + i2s all waveforms functional
    + i2s variable frequency
    + encoder updated (now with pushbutton counter)
2022-03-09 waveform cutoff fix
    [Beilage-exportpro2.cfg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]
2022-03-10 cleaner way to write frequencies
    added oscillators
    [config.h, main.c]
2022-03-21 first device test (large commit)
    [Beilage-exportpro2.cfg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]
2022-03-31 fixed spi bus driver
    [Beilage.brd, Beilage.sch]
2022-04-04 led strip upd
2022-04-25 timer dycle started
2022-06-09 fixed seven segment muxing
    issue #41 fixed
    [config.h, main.c, sequencer.c]
2022-06-12 Added Button Control
    Implemented MCP interrupt for Buttons.
    Prescaler for Gate and BPM as well as 4 main buttons are now saved in the sequencer_handle_t on change
2022-06-13 upd buttons
    Still need to fix issue #45
    [main.c, sequencer.c]
2022-06-13 hwep 20221306
    added semaphores
    #45 not fixed
    [main.c]
2022-06-13 fixed a few
    # fixed #40
    # partly fixed #45:
    this occurs because of the fast display multiplexing -> timer interrupts spi transmissin or the other way around. ESP either crashes or th ebutton inputs are read in a weird way (no MSB read but still interrupts)
    [sequencer.c]
2022-06-14 upd ENR mode
    ENR mode now resets on cursor but only if mode is other than ENR.
    ADC to pitch fix
    [main.c, sequencer.c]
2022-06-14 upd button functions
2022-06-15 RTOS IS NOT NICE TO ME
    RTOS NEEDS MAJOR FIX
    spi bus transaction timings need to be scheduled correctls
    UPDATE
    updated ENR button funct a little bit
    [main.c, sequencer.c]
2022-06-17 implemented RTOS functions
    new mode Timer
    fixed #48 #47
    Started Software Documentatino
    [main.c, sequencer.c]
2022-06-18 updated functionality
    issue #50 still present
    [main.c, sequencer.c]
2022-06-18 fixed
    less ISR calls fixed #50
    [Beilage.sch]
2022-06-18 exprt pro
    [Beilage-exportpro2.cfg, Beilage.brd]
2022-06-18 Docu PCB
2022-06-18 cleanup and SW docs upd
    [Beilage-exportpro2.cfg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]
2022-06-19 docu print
    [Projektplan_GruS_IhnH_V2.xlsx, STL_HWEP_Sequencer_V2.xlsx]
2022-06-19 clean up and finished word docs
    [Beilage-exportpro2.cfg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]
2022-06-20 upd docs
    [06_STL_HWEP_Sequencer_V2.xlsx, 08_Projektplan_GruS_IhnH_V2.xlsx]
2023-06-12 upd libs
    [08_GANTT_GruS_IhnH_V2.xlsx]
